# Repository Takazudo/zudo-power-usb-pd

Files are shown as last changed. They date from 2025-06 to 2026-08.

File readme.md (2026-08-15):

# USB-PD Powered Modular Synthesizer Power Supply

A low-noise power module design that takes USB-C PD 15V input and provides ±12V/+5V power for modular synthesizers.

## Documentation

**Main documentation is in the `/doc/` Docusaurus site**

```bash
cd doc
pnpm install
pnpm start
```

Open http://localhost:3000 in your browser to view the documentation.

### Key Documents

- **[Project Overview](doc/src/content/docs/overview/overview.md)** - Design goals, architecture, features
- **[Board A — USB-PD Sink Core](doc/src/content/docs/overview/board-a-usb-pd-core.md)** - PD negotiation, load switch, A↔B interface
- **[Board B — Synth Power Conversion](doc/src/content/docs/overview/board-b-synth-power.md)** - DC-DCs, LDOs, protection, outputs
- **[Circuit Diagrams](doc/src/content/docs/overview/circuit-diagrams.mdx)** - Complete circuit configuration
- **[Bill of Materials](doc/src/content/docs/overview/bom.md)** - JLCPCB-compatible BOM
- **[Component Records](doc/src/content/docs/components/index.mdx)** - Generated per-component evidence pages

## Project Overview

### Design Goals

A modular synthesizer power supply powered by USB-C PD chargers.

- **Input**: USB-C PD 15V 3A (max 45W)
- **Output**: +12V/1.2A, -12V/1.0A, +5V/1.2A
- **Ripple**: <1mVp-p (low noise optimized for modular synths)
- **Protection**: PTC auto-reset + fuse backup (beginner-friendly)
- **Sourcing**: All parts JLCPCB-compatible (reliable supply, low cost)

### 4-Stage Architecture

```
USB-C 15V ──┬─→ +13.5V (DC-DC) ──→ +12V (LDO) ──→ +12V OUT
            │
            ├─→ +7.5V  (DC-DC) ──→ +5V  (LDO) ──→ +5V OUT
            │
            └─→ -13.5V (inverting DC-DC) ──→ -12V (LDO) ──→ -12V OUT
```

**DC-DC + LDO Two-Stage Design**: Balancing efficiency and noise

- DC-DC ensures efficiency (85-90%)
- LDO removes noise (<1mVp-p)
- Overall efficiency: 75-80%

## Current Status

### Completed

- Circuit design complete (4-stage architecture)
- Main component selection complete (JLCPCB part numbers confirmed)
- Detailed documentation complete

### Next Steps

1. **Search for remaining parts** (PTC fuses × 3, 2A fuse × 1)
2. **KiCad PCB design** (4-layer board recommended)
3. **Order prototype** (JLCPCB SMT)
4. **Performance testing** (ripple, efficiency, thermal)

## Repository Structure

- `/doc/` - Docusaurus documentation site **← Main documentation**
- `/footprints/` - PCB footprint images (CH224Q, USB-C)
- `/diagram-sources/` - Python schemdraw scripts for circuit diagrams
- `/symbols/` - KiCad symbol library
- `/3dp-files/` - 3D printable files
- `/jlcpcb-templates/` - JLCPCB order templates
- `/__inbox/` - Working directory (temporary files, gitignored)

## Original Concept

The reliable Doepfer power supplies use DC-DC converters for voltage conversion, with linear regulators (LM7812/LM7912) and capacitors at the final stage to reduce switching noise.

Following this design philosophy, this project obtains 15V power from USB-PD and provides low-noise ±12V/+5V power required by modular synthesizers.

- **+12V**: 1200mA (most commonly used voltage in modular synths)
- **-12V**: 800mA (used by VCOs/VCAs)
- **+5V**: 500mA (used by digital modules)

These values are based on typical usage ratios in standard modular synthesizer systems.

## Reference Links

- [JLCPCB Parts Library](https://jlcpcb.com/parts)
- [KiCad Official Site](https://www.kicad.org/)
- [CH224Q Datasheet](https://www.wch-ic.com/products/CH224.html)

## License

This project is open source. Hardware design files can be freely used and modified.

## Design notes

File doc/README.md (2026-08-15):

# USB-PD Modular Synth Power Documentation

This directory is the documentation site for the USB-PD powered modular
synthesizer power supply. It is a [zudo-doc](https://github.com/takazudo) site
(a zfb / MDX / Tailwind / Preact static-site framework) consuming
`@takazudo/zfb` + `@takazudo/zdtp`, deployed to **Cloudflare Workers** (static
assets).

## Setup

```bash
pnpm install        # install dependencies
pnpm dev            # start dev server at http://localhost:4321
pnpm build          # production build (emits dist/, incl. dist/_worker.js)
pnpm preview        # preview the built dist/ locally
pnpm check          # TypeScript typecheck
```

## Directory Structure

```
doc/
├── src/
│   ├── content/docs/   # Documentation content (the pages)
│   │   ├── overview/   # Project overview, circuit diagrams, BOM
│   │   ├── components/ # Individual component specifications
│   │   ├── learning/   # Circuit design learning notes
│   │   ├── how-to/     # How-to guides
│   │   ├── misc/       # Footprint preview, misc
│   │   └── inbox/      # Status, debug logs, quick reference
│   ├── chrome-bindings.tsx    # MDX component registry for generated pages
│   ├── component-model-viewer/ # 3D model viewer island
│   ├── component-preview/     # Footprint/component preview island
│   └── styles/                # Global CSS
├── public/             # Static assets served at site root
│   ├── circuits/       # Circuit diagram SVGs   → /circuits/<name>.svg
│   ├── footprints/     # Footprint layout SVGs  → /footprints/<name>.svg
│   ├── footprint-imgs/ # Footprint preview PNGs → /footprint-imgs/<name>.png
│   ├── datasheets/     # Component datasheets (PDF)
│   ├── img/            # General images
│   └── kicad/          # KiCad screenshots
├── pages/              # two package-owned route stubs (index, docs catch-all)
├── zfb.config.ts       # site config — one zudoDoc({...}) call
└── wrangler.toml       # Cloudflare Workers deploy config
```

## Adding Documentation

1. Create a `.md` (no JSX) or `.mdx` (with JSX) file in the appropriate
   `src/content/docs/<section>/` directory.
2. Add frontmatter — `title:` is required; `sidebar_position:` controls order:
   ```yaml
   ---
   title: My Page
   sidebar_position: 3
   ---
   ```
3. Write content in Markdown/MDX. Start headings at `##` (the `title` renders as
   the h1). See `CLAUDE.md` in this directory for the full authoring rules.

## Tech Stack

- **zudo-doc** / **zfb** (`@takazudo/zfb`) — static-site framework
- **Preact** — UI rendering (server-rendered, islands for interactivity)
- **MDX** — Markdown + JSX content
- **Tailwind CSS** — styling
- **Mermaid** — diagram rendering
- **TypeScript** — type safety
- **Cloudflare Workers** — hosting (static assets via the zfb CF adapter)

## Commands

- `pnpm dev` — dev server at http://localhost:4321
- `pnpm build` — production build → `dist/`
- `pnpm preview` — preview the built `dist/`
- `pnpm check` — TypeScript typecheck
- `pnpm check:html` — validate built HTML

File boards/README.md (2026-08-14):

# boards/

Home for the split-board KiCad projects — **Board A** (USB-PD sink core:
STUSB4500 + USB-C + load switch + NVM pads) and **Board B** (synth power
conversion: DC-DCs + LDOs + protection + outputs). See
`doc/src/content/docs/inbox/board-split-decision.md` for the full board-split
decision and the A/B interface contract.

Both board projects exist and their schematics are generated from the spec
modules in `scripts/schgen/`. PCB layout has not started yet — the
directories carry schematics only, no `.kicad_pcb`.

## Layout

Each board has its own directory with its own KiCad project, named after the
board (a `<board>.kicad_pcb` is added when layout starts):

```
boards/
  board-a/
    board-a.kicad_pro
    board-a.kicad_sch
    fp-lib-table
    sym-lib-table
  board-b/
    board-b.kicad_pro
    board-b.kicad_sch
    fp-lib-table
    sym-lib-table
```

## Depth rule for library tables

The repo's shared symbol and footprint libraries live at the repo root
(`symbols/zudo-pd.kicad_sym`, `footprints/kicad/zudo-power.pretty`). The
root-level `zudo-pd.kicad_pro`'s own `sym-lib-table`/`fp-lib-table` reference
them directly, because `${KIPRJMOD}` (the project's own directory) *is* the
repo root there:

```
(lib (name "zudo-pd")(uri "${KIPRJMOD}/symbols/zudo-pd.kicad_sym") ...)
```

Each board project instead lives two directories below the repo root
(`boards/<name>/`), so `${KIPRJMOD}` there resolves to `boards/<name>/`, not
the repo root. Board `fp-lib-table`/`sym-lib-table` files must therefore add
one extra `..` to reach back up to the shared libraries:

```
(lib (name "zudo-pd")(uri "${KIPRJMOD}/../../symbols/zudo-pd.kicad_sym") ...)
(lib (name "zudo-pd")(uri "${KIPRJMOD}/../../footprints/kicad/zudo-power.pretty") ...)
```

Getting this depth wrong is the classic "board opens with missing symbols"
failure mode — double-check it whenever a new board project is created here.

## Regenerating a board schematic

Board schematics are not hand-drawn; they're generated from a Python spec
module by the `schgen` toolchain. See `scripts/schgen/README.md` for the full
workflow. Short version:

```
python3 scripts/schgen/gen_schematic.py board_a_spec   # or board_b_spec
```

`<spec_module>` is either a dotted module name (`board_a_spec`) or a path
(`scripts/schgen/board_a_spec.py`); `--help` works.

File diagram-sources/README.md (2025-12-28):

# Circuit Diagram Sources

This directory contains Python scripts that generate circuit diagrams using the `schemdraw` library.

## Organization

- **Source files**: Python scripts (`.py`) are stored here
- **Generated files**: SVG outputs are saved to `../docs/_fragments/`
- **Dark theme**: All diagrams use dark theme (black background, white foreground, Arial font)

## Generating Diagrams

Run any Python script to regenerate its corresponding SVG:

```bash
cd diagram-sources
python3 buck-u2-diagram.py
```

Output will be saved to `docs/_fragments/buck-u2-diagram.svg`

## Current Diagrams

- `buck-u2-diagram.py` → LM2596S-ADJ Buck Converter (+15V → +13.5V)

## Adding New Diagrams

1. Create a new `.py` file in this directory
2. Use the existing scripts as templates
3. Set output path to: `../docs/_fragments/your-diagram-name.svg`
4. Run the script to generate the SVG
5. Import and use in MDX files via the `CircuitSvg` component

## Requirements

```bash
pip install schemdraw
```

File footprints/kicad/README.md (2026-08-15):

# KiCad Footprints

This directory contains KiCad footprint files (.kicad_mod) for components used in this USB-PD power supply project. All footprints were downloaded from LCSC/EasyEDA using the [easyeda2kicad.py](https://github.com/uPesy/easyeda2kicad.py) tool.

## Key Component Footprints

### USB-PD Stage
- **QFN-20_L3.0-W3.0-P0.40-BL-EP1.7.kicad_mod** - CH224D USB PD Controller (C3975094)
- **TYPE-C-SMD_TYPE-C-6P.kicad_mod** - USB Type-C 6P Female Connector (C456012)

### DC-DC Converter Stage
- **TO-263-5_L10.2-W8.9-P1.70-BR.kicad_mod** - LM2596S-ADJ Buck Converter (C347423) — also used for U4 in inverting buck-boost config

### Linear Regulator Stage
- **TO-220-3_L10.0-W4.5-P2.54-L.kicad_mod** - LM7812CV +12V Regulator (C2914)
- **TO-263-2_L10.0-W9.2-P5.08-LS15.3-TL-CW.kicad_mod** - L7805ABD2T +5V Regulator (C86206)
- **TO-252-3_L6.5-W5.8-P4.58-BL.kicad_mod** - CJ7912 -12V Regulator (C94173)

### Passive Components
- **C0603.kicad_mod** - 0603 Capacitor
- **R0603.kicad_mod** - 0603 Resistor
- **CAP-SMD_BD4.0-L4.3-W4.3-LS5.0-FD.kicad_mod** - SMD Electrolytic Capacitor (small)
- **CAP-SMD_BD18.0-L19.0-W19.0-LS20.4-FD.kicad_mod** - SMD Electrolytic Capacitor (large)

### Protection & Indicators
- **SMA_L4.4-W2.8-LS5.4-RD.kicad_mod** - SMA Diode Package (TVS, Schottky)
- **SOD-123FL_L2.8-W1.8-LS3.7-RD.kicad_mod** - SOD-123FL Diode Package
- **LED0603-RD.kicad_mod** - 0603 LED (Red)
- **LED0603-R-RD_WHITE.kicad_mod** - 0603 LED (White)

### Connectors
- **HDR-TH_16P-P2.54-H-M-R2-C8-S2.54.kicad_mod** - 16-pin 2.54mm Through-hole Header (Eurorack Power)
- **HDR-TH_3P-P2.54-V-M.kicad_mod** - 3-pin 2.54mm Through-hole Header
- **HDR-SMD_6P-P2.00-V-M_XBK_R2.kicad_mod** - 6-pin 2.00mm SMD Header
- **HDR-SMD_8P-P2.54-V-M-LS4.8_R2.kicad_mod** - 8-pin 2.54mm SMD Header
- **DC-IN-TH_DC550250-0366-2H.kicad_mod** - DC Input Jack (Through-hole)

## Usage

### In KiCad
1. Add this directory to your KiCad footprint library list
2. Select footprints when assigning components in your schematic

### Downloading Additional Footprints

To download footprints for other components:

```bash
easyeda2kicad --lcsc_id <LCSC_ID> --footprint
```

The footprints will be saved to `~/Documents/Kicad/easyeda2kicad/easyeda2kicad.pretty/` and can be copied to this directory.

Example:
```bash
# Download CH224D footprint
easyeda2kicad --lcsc_id C3975094 --footprint

# Copy to project
cp ~/Documents/Kicad/easyeda2kicad/easyeda2kicad.pretty/*.kicad_mod ./
```

## Notes

- All LCSC part numbers are referenced in the [Bill of Materials](/doc/src/content/docs/overview/bom.md)
- Footprints include pads, silkscreen, and courtyard layers
- Some footprints may include 3D model references (if available from EasyEDA)

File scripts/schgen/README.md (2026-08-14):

# schgen — schematic generation from board spec modules

Board schematics under `boards/` are not hand-drawn. Each board is generated
from a Python spec module (`board_a_spec.py` / `board_b_spec.py`) that lists
components, positions, nets, and no-connects. The spec is the source of
truth; the `.kicad_sch` file is a build artifact of it.

The toolchain was ported from `zudo-led-lamp`; both board spec modules are
committed and both boards under `boards/` are generated from them. See
`doc/src/content/docs/inbox/board-split-decision.md` for the A/B interface
contract.

## Files

- `board_a_spec.py`, `board_b_spec.py` — per-board `COMPONENTS` / `NETS` /
  `NO_CONNECT` tables. Edit these, never the generated `.kicad_sch` directly.
- `decisions.json` — the wave-6 decision lock for epic #86 (part swaps,
  provisions, dispositions the board specs must implement), with rationale and
  fact-ID evidence per decision. Machine-consumable source of truth; issue
  bodies #124/#125/#126 mirror it. Its `required_decision_keys` list declares
  which decision keys the validator requires.
- `check_decisions.py` — offline validator for `decisions.json`: schema shape,
  the data-declared required decision keys, and kind-aware resolution of every
  evidence ID against the component-bundle / integration-rule fact base. Run:
  `python3 scripts/schgen/check_decisions.py`.
- `baselines/` — locked connectivity baselines per board
  (`board-a.json` / `board-b.json`: net → `Ref.Pin` lists derived from the
  reviewed netlist) plus the allow-list files naming the intentional
  spec-vs-baseline deltas (`board-a-allowed-deltas.json` /
  `board-b-allow.json`).
- `check_baseline.py` — diffs a spec module's `NETS` against its locked
  baseline JSON, modulo the allow-list. Every declared allow-list delta is
  also verified to actually hold in the spec, so a stale entry surfaces as a
  mismatch instead of masking an incomplete implementation. Also has a
  fixture-driven `--self-test` (see `fixtures/check_baseline/`). Run:
  ```
  python3 scripts/schgen/check_baseline.py scripts/schgen/board_a_spec.py scripts/schgen/baselines/board-a.json --allow scripts/schgen/baselines/board-a-allowed-deltas.json
  python3 scripts/schgen/check_baseline.py scripts/schgen/board_b_spec.py scripts/schgen/baselines/board-b.json --allow scripts/schgen/baselines/board-b-allow.json
  python3 scripts/schgen/check_baseline.py --self-test
  ```
- `schgen_core.py` — shared generator: reads symbols from
  `symbols/zudo-pd.kicad_sym`, places components, and emits global labels for
  every net (no drawn wires) plus no-connect markers. Also home of the shared
  `load_spec_module()` loader (path or dotted module name) every CLI here
  uses, and the `SchgenError` the tools report as messages rather than
  tracebacks.
- `sexp.py` — tiny, dependency-free KiCad s-expression tokenizer/parser used
  by the generator, the verifiers, and the smoke test. No KiCad install
  required.
- `gen_schematic.py` — CLI entry point:
  `python3 scripts/schgen/gen_schematic.py <spec_module>` where
  `<spec_module>` is a path (`scripts/schgen/board_a_spec.py`) or a dotted
  module name (`board_a_spec`). `--help` works.
- `verify_geometry.py` — re-derives every pin endpoint from a generated
  `.kicad_sch` itself (embedded lib_symbols + instance placements) and checks
  that every global label sits on a pin endpoint, no coordinate mixes two
  nets (no implicit shorts), the label-derived net map equals the spec's
  `NETS`, and no-connect markers match `NO_CONNECT`. Pure Python, no KiCad.
  Run: `python3 scripts/schgen/verify_geometry.py <spec_module> <kicad_sch>`.
- `verify_netlist.py` — diffs a kicad-cli netlist export against a spec's
  `NETS`/`NO_CONNECT` tables and prints `PASS`/`FAIL`.
- `verify.sh` — wraps the kicad-cli export + `verify_netlist.py` call for one
  board. Local-only (see below); not run in CI.
- `test_spec_smoke.py` — minimal spec (3 real zudo-pd resistor symbols, 2
  nets, 2 no-connects) used only to smoke-test the generator itself. Not a
  real board.
- `run_smoke_test.sh` — regenerates `test_spec_smoke.py` into a throwaway
  temp dir (never touches the repo tree), asserts the emitted global net
  labels match the spec's `NETS`, runs the `verify_geometry.py` checks on the
  output, and proves the geometry check can fail via a corrupted-label
  negative control. Requires only stock `python3` — no pip installs, no
  KiCad.
- `fixtures/check_baseline/` — the fixture corpus behind
  `check_baseline.py --self-test`.

## Regen + verify workflow

1. Edit the spec module (`board_a_spec.py` or `board_b_spec.py`) — add/move a
   component, change a net, etc.
2. Regenerate the schematic:
   ```
   python3 scripts/schgen/gen_schematic.py board_a_spec   # or board_b_spec
   ```
   This rewrites `boards/<board>/<board>.kicad_sch` in place. No KiCad
   install needed — `gen_schematic.py` only depends on `sexp.py`.
3. Run the offline checks CI will run (baseline drift + geometry):
   ```
   python3 scripts/schgen/check_baseline.py scripts/schgen/board_a_spec.py scripts/schgen/baselines/board-a.json --allow scripts/schgen/baselines/board-a-allowed-deltas.json
   python3 scripts/schgen/verify_geometry.py scripts/schgen/board_a_spec.py boards/board-a/board-a.kicad_sch
   ```
4. Verify connectivity against a real netlist export (requires a local KiCad
   install with `kicad-cli` on `PATH`):
   ```
   scripts/schgen/verify.sh board-a   # or board-b
   ```
   This runs `kicad-cli sch export netlist --format kicadsexpr` on the
   regenerated `.kicad_sch`, then diffs the result against the spec's `NETS`
   and `NO_CONNECT` tables via `verify_netlist.py`, printing `PASS`/`FAIL`.
5. Open the regenerated schematic in KiCad's Eeschema at least once (ERC,
   visual sanity) before committing.
6. Commit the spec module and the regenerated `.kicad_sch` together — never
   one without the other.

## Smoke test (no board, no KiCad)

To sanity-check the generator itself — e.g. after touching `schgen_core.py`
or `sexp.py` — run:

```
bash scripts/schgen/run_smoke_test.sh
```

This generates `test_spec_smoke.py` into a temp directory, parses the result
back with `sexp.py`, asserts the emitted global labels equal the spec's
`NETS`, and runs the full geometry check (including its negative control). It
needs stock `python3` only.

## kicad-cli availability

`verify.sh` degrades gracefully when `kicad-cli` is not on `PATH`: it prints
a `SKIPPED` marker and exits `0` rather than failing. This is intentional —
netlist verification is a local-only check that needs a real KiCad install
(the CI runner has no KiCad). Install KiCad (kicad-cli ships with the desktop
app) to exercise the real path.

## What CI checks

`.github/workflows/component-spec-skills.yml` runs, for every PR touching
this toolchain (and pushes to `main`):

- **Regen-idempotency** — regenerate both boards against the checked-out tree
  and fail on any diff under `boards/` (with `git add --intent-to-add` first,
  so a newly emitted untracked file also fails). Catches "spec and committed
  schematic drifted apart".
- **Label geometry** — `verify_geometry.py` on both committed boards: labels
  on pin endpoints, no cross-net coordinate collisions, label net map equal
  to the spec, no-connects matching.
- **Baseline drift** — `check_baseline.py` per board against
  `baselines/*.json` with the allow-list files.
- **Tool self-tests** — `check_baseline.py --self-test` and
  `run_smoke_test.sh`.
- **Decision lock** — `check_decisions.py`.

What CI still cannot do is run `kicad-cli`; the netlist cross-check in
`verify.sh` stays a local, KiCad-installed step.

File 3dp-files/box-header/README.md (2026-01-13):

# Box Header Guard for Eurorack Power Connector

3D printable shrouded/keyed box header frame that converts standard 2×8 pin headers into IDC-compatible Eurorack power connectors.

## Target Component

- **LCSC Part**: [C5383092](https://jlcpcb.com/partdetail/C5383092)
- **Part Number**: 2541WR-2x08P
- **Type**: 2×8 pin header (16-pin), 2.54mm pitch

## Files

| File | Description |
|---|---|
| `box-header.scad` | OpenSCAD source file |
| `box-header.stl` | 3D printable STL |
| `C5383092.pdf` | Pin header datasheet (if present) |

## Key Dimensions

| Parameter | Value | Source |
|---|---|---|
| Pin pitch | 2.54mm | Datasheet |
| Pin size | 0.64mm (square) | Datasheet SQ.0.64 |
| Row spacing | 2.54mm | Standard |
| Box height | 8.9mm | Standard IDC |
| Bottom thickness | 0.5mm | Modified |
| Slot width | 0.6mm | Adjusted after print test |

## Design Features

- **Center divider** on bottom surface for alignment
- **0.8mm pin holes** for tight press-fit
- **Key notch** for polarized connection (prevents reverse insertion)
- **Thicker walls** (1.5mm) for print durability

## Print Settings

- Layer height: 0.2mm recommended
- No supports needed
- Print with bottom face down

## License

Original design by John Stäck 2018, licensed under [CC BY-SA 4.0](https://creativecommons.org/licenses/by-sa/4.0/).

Modifications:
- Changed bottom thickness to 0.5mm
- Added center divider
- Adjusted slot width to 0.6mm

## Usage

Press-fit onto the 2×8 pin headers (J2-J5) on the PCB to create shrouded connectors compatible with standard Eurorack 16-pin ribbon cables.

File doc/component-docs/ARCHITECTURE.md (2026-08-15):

# Component knowledge docs — architecture contract (zudo-pd port)

Status: **locked** (spec-architecture epic #86; ported from `zudo-led-lamp`'s
epic-#57 engine and trimmed to this repository's adapter reality)
Scope: project-local code under `doc/`. Not a framework feature, not an
installable package, not a change to any other repository.

This document is the contract the generator code cites. Where it names a file,
a command or a rule, that is the decision — not a suggestion. Section numbers
are stable because source comments cite them (`§5`, `§7`). Where this port
deliberately differs from led-lamp, the difference is stated inline; the
led-lamp original remains the reference for the sections of the engine that
were ported unchanged.

---

## 1. What this is

The repository holds validated component evidence as structured JSON under
`.claude/skills/`. That data is the **only** source of technical truth. This
feature adds a **projection** of it into human documentation. It never
re-states a fact in prose, never repairs a value, and never synthesises a
component-wide verdict.

Corpus as of this contract: **21 owner bundles, 41 records (all standalone),
126 sources, 454 facts, 144 coverage domains, 36 interactions, 41 routes, 41
pin maps, 136 pins**, plus **9 cross-component rules** in
`circuit-spec-integration`; 40 inventory lines fitted, 2 DNP/hand-fit (one
line, `line-c23186`, is mixed — fitted on board-b, DNP on board-a — which is
why fit state is carried per placement, §5). These figures are asserted in
code (`adapters/circuit/selection.ts` `expect`, and the test suites) and a
mismatch fails the build.

## 2. Directory ownership

| Path | Owner | Rule |
|---|---|---|
| `doc/component-docs/` | this feature | all generator code, tests, this document |
| `doc/src/content/docs/components/` | **generator, exclusively** | committed; never hand-edit; every file is rewritten from evidence |
| `doc/component-docs/preflight.json` | generator | committed, deterministic, reviewable |
| `doc/src/chrome-bindings.tsx` | site | carries the evidence-component registrations (`mdxExtras`); must stay in sync with `core/mdx.ts` `ALLOWED_COMPONENT_ATTRIBUTES` (guarded by `tests/presentation.test.ts`) |
| `doc/src/styles/global.css` | site | an appended presentation block for the generated pages (`.zld-evidence-*`) |
| `.claude/skills/**` | evidence owners | **read-only** to this feature |

**Matches led-lamp.** The exclusively-owned generated tree is rooted directly
at `doc/src/content/docs/components/` (`GENERATED_ROOT` in
`adapters/circuit/paths.ts`), identical to led-lamp's shape. The public URLs
read `/docs/components/{catalog,integration,records,records/<slug>}/`.

### Module layout under `doc/component-docs/`

```
core/                       provider-neutral; no Python, no `.claude`, no fs paths
  errors.ts                 ErrorCode union + ComponentDocsError + fail()
  text.ts                   SafeText brand + safeText() sanitiser
  url.ts                    SafeUrl brand + classifyUrl() policy
  ids.ts                    Slug/Anchor brands, recordSlug(), anchor(), byCodeUnit()
  view-model.ts             the public view model TYPES (frozen here)
  publication.ts            FieldKey union, PublicationMatrix, PublicationPolicy, PreflightReport
  mdx.ts                    mdast builders + serializeBody() + assertMdxSafe()
  page.ts                   frontmatter + buildPage() + generated-file marker
  emit.ts                   owned-tree write / prune / diff, path containment
  adapter.ts                ComponentDataAdapter + ValidationRunner interfaces
  pipeline.ts               the one generation path
  scan.ts                   denied-value artifact scanning (wired by cli/scan.ts)
  render/landing.ts         /docs/components/                    (landing)
  render/catalog.ts         /docs/components/catalog/
  render/record.ts          /docs/components/records/<slug>/
  render/shared.ts          routes, glosses and orderings the pages share
  render/integration.ts     /docs/components/integration/
adapters/circuit/           this repository's evidence provider
  paths.ts                  every path the adapter may touch
  validate.ts               python3 validate.py --strict subprocess
  read.ts                   contained, symlink-refusing JSON reads
  selection.ts              committed instance allowlist (41 records / 126 sources)
  matrix.ts                 committed per-field decisions
  canaries.ts               denied-key harvest for the artifact scan
  integration.ts            cross-component rules: shapes, projection, closure
  evidence.ts               provider shapes, bundle reads, the joins (pure)
  references.ts             the reviewed document / footprint / model contract
  model-assets.ts           deterministic WRL publication into doc/public/
  index.ts                  the adapter itself; `projectIndex` is the pure projection
footprint-previews/         the committed footprint SVG generator + drift check
cli/                        run.ts (shared body), generate.ts, check.ts, scan.ts, watch.ts, models.ts
ui/                         evidence-{anchor,details,table}.tsx, component-references.tsx,
                            footprint-preview.tsx, package-model-viewer.tsx
scripts/                    model-viewer-browser-smoke.mjs (headless Chrome over CDP)
tests/                      node:test suites + fixtures.ts / provider fixtures
```

The two interactive previews live outside this directory, under
`doc/src/component-preview/` and `doc/src/component-model-viewer/`: they are
`"use client"` islands the site's build bundles, and `ui/` holds only the
SSR-safe bindings that mount them. `three` is imported by exactly one module
(`viewer-runtime.ts`), which the island loads with a dynamic `import()`, so it
ships in its own chunk and never in the page bundle.

`evidence.ts` and `projectIndex` are pure functions over parsed JSON, so every
join rule and every publication rule is provable against a fixture corpus with
no filesystem, no subprocess and no edit to the read-only evidence tree.

The dependency direction is one-way: `adapters/circuit/**` imports from
`core/**`; `core/**` imports nothing from `adapters/**`.

## 3. Build seam — package scripts, not a host plugin

`doc/package.json`:

| Script | Purpose |
|---|---|
| `generate:components` | validate (strict) → project → render → emit |
| `check:components` | dry-run; nonzero on drift |
| `scan:components` | denied-value scan of the BUILT site (`dist/`, §6.1) |
| `test:components` | unit + integration suites |
| `dev:components` | debounced regeneration (watch) |
| `generate:models` / `check:models` | publish (or drift-check) the reviewed WRL models |
| `generate:footprint-previews` / `check:footprint-previews` | the same pair for the footprint SVGs |
| `check:built-component-references` | the reference section's built-`dist/` contract |
| `test:model-viewer:browser` | headless-Chrome smoke over `dist/` (not in `b4push`; needs a browser) |
| `build` | `pnpm generate:models && pnpm generate:components && zfb build` — generation precedes the content snapshot |
| `b4push` | `check && test:components && check:footprint-previews && check:models && build && check:built-component-references && check:components && scan:components` |

Generation ordering is a **package-script** boundary, not a host-plugin
assumption: `generate:components` has finished and exited before `zfb` starts,
which is why `cli/generate.ts` can promise the snapshot already contains its
output. (led-lamp's §3 records the full plugin-vs-script rationale; it applies
here unchanged.) `generate:models` runs before it for the same reason one step
down: the model assets have to be in `public/` before `zfb` copies it.

The browser smoke is deliberately outside `b4push`. It needs a Chrome binary
and roughly a minute of wall clock, which is a reasonable ask of CI and of a
change to the viewer, but not of every push.

## 4. Validation — one validator, in Python, fatal on failure

`adapters/circuit/validate.ts` runs
`python3 .claude/skills/component-spec-audit/scripts/validate.py --strict` as
an argument array (`execFile`, no shell, no interpolation), cwd = repository
root, before any evidence is read. `--strict` matches the mode CI's PR gate
enforces (`component-spec-skills.yml`), so the doc build cannot pass on
evidence the PR gate rejects. Nonzero exit aborts generation with
`VALIDATION_FAILED`. `--online` is never passed. Python is pinned to >= 3.12,
matching the workflow pin; `COMPONENT_DOCS_PYTHON` overrides the interpreter.
No component validation is reimplemented in TypeScript.

## 5. View model and adapter seam

`core/view-model.ts` freezes the public shape. `VIEW_MODEL_VERSION = 1`; an
adapter declares `supportedViewModelVersions` and the pipeline refuses to run
on a mismatch, so a core/adapter skew is a startup error rather than a subtly
wrong page.

**v1 stays v1 while `core/` and the only adapter compile together from this
repository, including through incompatible shape changes.** led-lamp's epic
made two such changes without bumping the number (widening
`PublicFact["value"]`; adding required `ownerSkill` fields), and this port has
made its own (adding required `PublicPlacement.dnp`; deleting the unported
3D/preview seam — `packagePreviews` and its types). None bumped the number,
deliberately: core and the single adapter are compiled together from one
repository, so a skew between them is a *compile* error long before the
runtime check sees it, and nothing outside this repository has ever consumed
v1 — a bump would only churn `preflight.json` and imply a compatibility
boundary that never existed. The number becomes a real boundary the moment
`core/**` is extracted as a package; from then on the rule in the
`VIEW_MODEL_VERSION` doc comment applies literally and any incompatible change
bumps it.

Port-specific shape decisions:

- **`PublicPlacement.dnp`** — fit state is per placement, because one
  inventory line is fitted on one board and DNP on the other
  (`line-c23186`). The line-level `dnp` is only the catalog rollup
  (fitted-if-fitted-anywhere); the record page renders each placement's own
  fit state, and a mixed line labels itself as mixed rather than either
  single state.
- **`ownerSkill` is `null` always** — zudo-pd runs with
  `claudeResources: false`, so `/docs/claude-skills/<name>/` does not exist
  as a route to link back to; `matrix.ts` denies both `record.ownerSkill`
  and `integration.ownerSkill`.
- **No `packagePreviews` seam** — led-lamp carries previews as a top-level
  view-model collection (`PublicPackagePreview` / `packagePreviews`) plus the
  `asset.footprintPreview` / `asset.modelPreview` field keys. Neither is
  ported: here both previews hang off `reference.footprint` on the record that
  uses them, so a preview cannot exist without a record pointing at it. The
  assets themselves do exist (waves 6 and 7) and both previews render — this
  is a shape difference, not an absence. Re-porting the collection starts from
  led-lamp's source, not from a vestigial copy here.
- **`corpus` counts what was published**, not what the provider holds: the
  landing page must never assert counts the site does not deliver. The three
  inventory-scoped rows (`inventoryLines`, `fittedLines`,
  `dnpOrHandFitLines`) stay inventory truth by design.

Identity, ordering and error rules (slugs from record IDs, verbatim provider
anchors scoped per page, inventory-line ordering with `byCodeUnit`, selection
closed under published links, integration rules count-asserted rather than
instance-selected, the closed `ErrorCode` union, fail-closed everywhere) are
ported unchanged from led-lamp §5.

## 6. Publication — default-zero, three gates

A value publishes only if it clears all three:

1. **Instance** — its record ID (and for a source, its source ID) is listed
   in `adapters/circuit/selection.ts`.
2. **Field** — its `FieldKey` is `PUBLISH` in `adapters/circuit/matrix.ts`.
3. **Value** — it survives `safeText()` / `classifyUrl()`.

`InstanceSelection.expect` pins **both sides**: the provider corpus size AND
the selection list lengths. The selection-side check exists because this
corpus once shipped a record (`rec-bzt52c11-c92321`) whose bundle validated
and whose counts were bumped while the ID list was left behind — the record
silently had no page. Either direction failing is a `STALE_SELECTION`.

zudo-pd's `DENY` set is 11 of 97 keys: led-lamp's seven content denials
(`source.sha256`, `source.evidenceExtract`,
`source.alternateAuthoritativeUrl`, `source.physicalPdfPageIndex`,
`routing.positivePrompts`, `routing.negativePrompts`, `pinMap.reviewedBy`),
`asset.binary`, both `ownerSkill` keys (`claudeResources: false`), and
`reference.package.recordIds`, which no renderer reads. All three halves of
`reference.*` publish: `documentSelections` names one reviewed source for 40
of the 41 records and `documentExceptions` names why the 41st has none,
`reference.footprint.{packageId,name,path}` back the rendered footprint
preview and its `Source:` line, and `reference.model.*` backs the interactive
package model viewer (wave 7 sourced a reviewed `.wrl`/`.step` pair for all
27 packages; wave 8 built the viewer). URL policy, the preflight report
contract, and the emitted-vs-withheld accounting are ported unchanged from
led-lamp §6.

### 6.1 Artifact-level proof (`pnpm scan:components`)

Everything above reasons about the projection; it cannot prove the **built
site** is clean, because between the view model and `dist/` sit the MDX
compiler, the HTML minifier and the indexers — none owned by this feature. So
`cli/scan.ts` (wired into `b4push` and `main-deploy.yml` after `pnpm build`)
harvests every value reachable only through a denied provider key
(`adapters/circuit/canaries.ts`), subtracts values independently published by
the hand-authored narrative pages, and scans every text artifact under
`dist/`. The scan fails closed in both directions: a hit is a leak, and too
few canaries or too few files means the scan proved nothing. Positive
controls (including `rec-bzt52c11-c92321`, the record that once shipped
page-less) prove "nothing leaked" is not "nothing shipped".

## 7. Safe generation — three layers

1. **Build.** Content is constructed only through the builders in
   `core/mdx.ts`. They accept `SafeText`/`SafeUrl` and a closed node
   vocabulary; there is no raw-node builder.
2. **Serialize.** `mdast-util-to-markdown` with `mdast-util-mdx` and
   `mdast-util-gfm-table`, plus `unsafe` rules for line-leading `:::` and
   line-leading `import`/`export`.
3. **Guard.** `assertMdxSafe` re-reads the **final** body text and fails the
   build on: line-leading `import`/`export`, line-leading `:::`, a `---`
   fence line, an HTML comment, any un-escaped `{` or `<`, any JSX name
   outside `ALLOWED_COMPONENT_ATTRIBUTES`, any attribute not listed for that
   component, and any attribute value outside `ATTRIBUTE_VALUE_PATTERN`
   (slug paths — slash-separated slug segments, admitted for `CategoryNav`'s
   nested `category` — and nothing else).

The guard's false positives are **deliberate**: it does not ask whether a
brace sat inside an inline-code span where MDX would treat it as inert — it
fails closed and a human decides. Renderers obey this rather than work around
it (monospace is for identifiers, which are code-shaped by construction;
evidence phrases render as text). Evidence text never reaches a JSX
attribute; frontmatter is a closed key set with `JSON.stringify`d values;
no generated data module is imported by any client entry; `safeText`
NFC-normalises and then **rejects** rather than strips. Relaxing any of this
is a publication decision, not a refactor.

## 8. Generated-tree ownership and cleanup

`doc/src/content/docs/components/` is written by `core/emit.ts` and
nothing else. Every write path is `assertContained` (segment-wise); emit
never `rm -rf`s — it prunes only marker-carrying `.mdx` leftovers under the
owned root; a file there without the generated marker is a fatal
`PATH_CONTAINMENT`; symlinks are fatal on both the write side and the
evidence-read side; emit is idempotent (a second run reports `0 written`).

## 9. Routes and navigation

| Route | Source |
|---|---|
| `/docs/components/` | `render/landing.ts` |
| `/docs/components/catalog/` | `render/catalog.ts` |
| `/docs/components/integration/` | `render/integration.ts` |
| `/docs/components/records/` | `render/record.ts` (records index) |
| `/docs/components/records/<slug>/` | `render/record.ts` (per-record pages) |

The landing page's `CategoryNav` targets `components` — this project's
wrapper resolves `category` as a slug path. The three evidence components
(`EvidenceAnchor`, `EvidenceDetails`, `EvidenceTable`) are registered in
`doc/src/chrome-bindings.tsx`; that registry and
`ALLOWED_COMPONENT_ATTRIBUTES` must change together, and
`tests/presentation.test.ts` enforces it.

## 10. CI

Two workflows, both credential-free on the checking side:

- **`component-spec-skills.yml`** (PRs + main): the strict Python validator,
  its unit tests, the strict forward tests, `check_baseline.py --self-test`,
  the schgen smoke test, regen-idempotency for both boards (untracked-aware
  via `git add --intent-to-add`), the label-geometry check, baseline drift,
  the decision lock — and a `doc-tests` job running `pnpm test:components`
  (Node + Python, because the pipeline tests shell out to the validator).
- **`main-deploy.yml`** (push to main): typecheck, build, the two-step
  generated-output drift gate (`--intent-to-add` + second-generation
  byte-identity via `check:components`), the `scan:components` artifact scan,
  then the guarded Cloudflare deploy. All actions are SHA-pinned.

## 11. Direct dependencies added

`mdast-util-to-markdown`, `mdast-util-mdx`, `mdast-util-gfm-table` (serializer
+ syntax tables), and `@types/mdast`. Everything else the generator uses is
Node builtin or already a site dependency.

## 12. Portability boundary

`core/**` is written to be extractable as a package: provider-neutral, no
`.claude` paths, no Python, no zudo-pd names. Extraction is deliberately
deferred — the port copies led-lamp's engine rather than sharing it, and both
repositories accept the divergence risk until a third consumer exists. The
`VIEW_MODEL_VERSION` rule flips from "stays 1" to "bumps on every
incompatible change" at that extraction boundary (§5).

## 13. Non-goals

No re-stated facts, no prose summaries of evidence, no component-wide
verdicts, no PDF republication, no `/docs/claude-skills/` routes, no sitemap
change, no framework feature. The generated pages are a projection; where they
disagree with the evidence JSON, the evidence is correct. The 3D preview is
in scope but stays inside that rule: the viewer shows the shared FOOTPRINT
package's geometry and says so on the card, which is a weaker claim than
"this is the part" and is the only one the evidence supports.

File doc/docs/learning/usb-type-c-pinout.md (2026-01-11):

---
sidebar_position: 6
---

# USB Type-C Pinout and Power Delivery

Understanding USB Type-C connector pinout and how it enables USB Power Delivery (PD) negotiation.

## Full USB Type-C Pinout (24-pin)

A full USB Type-C receptacle has 24 pins arranged symmetrically to support reversible insertion:

```
USB Type-C Receptacle (24-pin)
Receptacle Front View (looking into connector)

Top Row (A-side):
┌────────────────────────────────────────────────────┐
│ A1   A2   A3   A4   A5   A6   A7   A8   A9  A10  A11  A12 │
│ GND  TX1+ TX1- VBUS CC1  D+   D-  SBU1 VBUS RX2- RX2+ GND │
└────────────────────────────────────────────────────┘

Bottom Row (B-side):
┌────────────────────────────────────────────────────┐
│ B12  B11  B10  B9   B8   B7   B6   B5   B4   B3   B2   B1  │
│ GND  RX1- RX1+ VBUS SBU2 D-   D+  CC2  VBUS TX2- TX2+ GND │
└────────────────────────────────────────────────────┘
```

### Pin Functions

| Pin(s) | Signal | Purpose | Speed |
| --- | --- | --- | --- |
| **A1, A12, B1, B12** | **GND** | Ground reference | - |
| **A4, A9, B4, B9** | **VBUS** | Power delivery (5V-20V) | - |
| **A5** | **CC1** | Configuration Channel 1 | - |
| **B5** | **CC2** | Configuration Channel 2 | - |
| **A6, A7, B6, B7** | **D+, D-** | USB 2.0 data | 480 Mbps |
| **A2, A3** | **TX1+, TX1-** | SuperSpeed TX Lane 1 | 5-10 Gbps |
| **A10, A11** | **RX2-, RX2+** | SuperSpeed RX Lane 2 | 5-10 Gbps |
| **B2, B3** | **TX2-, TX2+** | SuperSpeed TX Lane 2 | 5-10 Gbps |
| **B10, B11** | **RX1-, RX1+** | SuperSpeed RX Lane 1 | 5-10 Gbps |
| **A8** | **SBU1** | Sideband Use 1 | Alternate modes |
| **B8** | **SBU2** | Sideband Use 2 | Alternate modes |

## Simplified USB Type-C for Power-Only (6-pin)

For applications requiring **only power delivery** (no data transfer), a simplified 6-pin connector is sufficient:

```
USB Type-C 6-Pin Connector (Power-Only)

┌──────────────────┐
│   1    2    3    │  Top Row
│  GND  VBUS  CC1  │
└──────────────────┘
┌──────────────────┐
│  CC2  VBUS  GND  │  Bottom Row
│   4    5    6    │
└──────────────────┘
```

### 6-Pin Functions

| Pin | Signal | Purpose |
| --- | --- | --- |
| **1, 6** | **GND**  | Ground reference |
| **2, 5** | **VBUS** | Power delivery (5V-20V) |
| **3** | **CC1**  | Configuration Channel 1 (orientation & PD) |
| **4** | **CC2**  | Configuration Channel 2 (orientation & PD) |

**This project uses a 6-pin connector** (JLCPCB C2927029) - see [J1 USB-C Connector documentation](/docs/components/usb-c-connector).

## Configuration Channel (CC) Pins

The CC pins are critical for USB Power Delivery. They serve multiple purposes:

### 1. Cable Orientation Detection

USB Type-C is reversible. When you plug in a cable:

- Only **one** CC pin is active at a time
- The active CC pin identifies cable orientation
- The other CC pin remains inactive

**Example**:

```
Orientation 1 (normal):
- CC1 active → CH224D detects cable on CC1
- CC2 inactive

Orientation 2 (flipped):
- CC2 active → CH224D detects cable on CC2
- CC1 inactive
```

### 2. Current Advertisement (Non-PD)

For standard USB Type-C (without PD negotiation), CC pins advertise available current:

| Rp (Pull-up resistor on source) | Advertised Current |
| --- | --- |
| 56kΩ | Default USB (500-900mA) |
| 22kΩ | 1.5A @ 5V |
| 10kΩ | 3A @ 5V |

### 3. Power Delivery Negotiation

With USB-PD (like CH224D), CC pins carry **digital communication**:

```
Negotiation Sequence:

1. Initial Connection (0-100ms):
   ┌─────────┐                    ┌─────────┐
   │ Source  │ ─── CC line ────→  │  Sink   │
   │ (PD     │                    │ (CH224D)│
   │ Charger)│                    │         │
   └─────────┘                    └─────────┘
   VBUS = 5V (default)

2. Capability Discovery (100-200ms):
   ┌─────────┐                    ┌─────────┐
   │ Source  │ ←── CC line ────   │  Sink   │
   │         │  "What voltages    │         │
   │         │   do you have?"    │         │
   └─────────┘                    └─────────┘

   Source responds:
   - 5V @ 3A
   - 9V @ 3A
   - 12V @ 3A
   - 15V @ 3A ✅
   - 20V @ 2.25A

3. Voltage Request (200-300ms):
   ┌─────────┐                    ┌─────────┐
   │ Source  │ ←── CC line ────   │  Sink   │
   │         │  "I want 15V/3A"   │         │
   │         │                    │         │
   └─────────┘                    └─────────┘

4. Acceptance (300-500ms):
   ┌─────────┐                    ┌─────────┐
   │ Source  │ ─── CC line ────→  │  Sink   │
   │         │  "OK, switching"   │         │
   │         │                    │         │
   └─────────┘                    └─────────┘

5. Voltage Transition (500-1000ms):
   VBUS transitions: 5V → 15V

6. Power Ready (>1000ms):
   VBUS stable at 15V
   System draws up to 45W (15V × 3A)
```

## VBUS Pins and Current Distribution

### Why Multiple VBUS Pins?

USB Type-C has **4 VBUS pins** (A4, A9, B4, B9) to:

1. **Distribute current**: Each pin carries a portion of total current
2. **Reduce resistance**: Parallel pins = lower resistance
3. **Improve reliability**: Redundancy in case of poor contact

**Current distribution example (3A total)**:

```
A4 ──┬─→ ~0.75A
     │
A9 ──┤─→ ~0.75A
     │
B4 ──┤─→ ~0.75A       Total: 3A
     │
B9 ──┴─→ ~0.75A
```

### 6-Pin Connector VBUS

In 6-pin connectors, only **2 VBUS pins** are present (pins 2, 5):

- Maximum current: **3A** (sufficient for most USB-PD applications)
- Current distribution: ~1.5A per pin

**This is adequate for our 15V/3A (45W) power supply.**

## Critical: Always Connect Redundant Pins Together

### Why Connect Both VBUS Pins Together?

USB Type-C has **redundant power pins** by design. For 6-pin connectors, this means:

- **2 VBUS pins** (pins 2, 5)
- **2 GND pins** (pins 1, 6)

**You must ALWAYS connect both pins of each type together.** Never connect just one!

### ✅ Correct Connection Strategy

```
J1 (USB-C 6P Connector)

Pin 1 (GND)  ──┬─→ System GND
               │   (via wide trace or ground plane)
Pin 6 (GND)  ──┘

Pin 2 (VBUS) ──┬─→ VBUS node → CH224D pin 2
               │   (via wide trace or copper pour)
Pin 5 (VBUS) ──┘

Pin 3 (CC1)  ────→ CH224D pin 10 (separate)
Pin 4 (CC2)  ────→ CH224D pin 11 (separate)
```

### ❌ Wrong: Connecting Only One Pin

```
❌ WRONG:
Pin 1 (GND)  ──→ System GND
Pin 6 (GND)  ──→ Not connected  ❌

Pin 2 (VBUS) ──→ VBUS node
Pin 5 (VBUS) ──→ Not connected  ❌
```

### Benefits of Connecting Both Pins

| Benefit | Single Pin | Both Pins Connected |
| --- | --- | --- |
| **Resistance** | R | **R/2** (half) ✅ |
| **Current per pin** | 3A | **1.5A** (distributed) ✅ |
| **Power dissipation** | I²R | **I²R/4** (quarter) ✅ |
| **Voltage drop** | High | **Low** ✅ |
| **Heating** | High | **Low** ✅ |
| **Reliability** | Single point of failure | **Redundancy** ✅ |
| **EMI/Noise** | Higher | **Lower** ✅ |

### Why This Matters: Practical Example

**Scenario**: 15V @ 3A power delivery

#### ❌ Using Only One GND Pin:

```
Resistance: 10mΩ (typical pin + trace resistance)
Current: 3A (full current through one pin)
Voltage drop: V = I × R = 3A × 10mΩ = 30mV
Power dissipation: P = I² × R = 9W × 10mΩ = 90mW (heats up!)
```

#### ✅ Using Both GND Pins:

```
Resistance: 5mΩ (two pins in parallel)
Current per pin: 1.5A (distributed)
Voltage drop: V = I × R = 3A × 5mΩ = 15mV (half!)
Power dissipation: P = I² × R = 9W × 5mΩ = 45mW (half the heating!)
```

**Result**: Connecting both pins gives you:

- 50% less voltage drop
- 50% less heating
- Better reliability with redundancy

### PCB Layout Best Practices

```
Top Copper Layer:

┌────────────────────────────────┐
│  USB-C Connector J1            │
│                                │
│  Pin 1 (GND) ────┐             │
│                  ├──→ Via to GND plane
│  Pin 6 (GND) ────┘             │
│                                │
│  Pin 2 (VBUS) ───┐             │
│                  ├──→ Wide trace to VBUS
│  Pin 5 (VBUS) ───┘             │
└────────────────────────────────┘

Ground Plane (Internal Layer):
████████████████████████████████
█ Solid copper pour             █
█ Multiple vias from pins 1, 6  █
████████████████████████████████
```

**Key points**:

1. Use **wide traces** (≥1mm) or **copper pours** for VBUS
2. Use **multiple vias** to connect GND pins to ground plane
3. Keep traces **short and direct**
4. Use **symmetrical routing** when possible

### USB-C Specification Requirement

The **USB Type-C specification requires** all redundant power pins to be connected:

- Ensures proper current distribution
- Guarantees reliable operation in both orientations
- Meets thermal and electrical specifications
- Required for USB-IF certification

**Bottom line**: Always connect both VBUS pins together AND both GND pins together. This is not optional!

## CH224D Connection to USB-C Connector

In this project, the CH224D connects to the 6-pin USB Type-C connector:

```
J1 (USB-C 6P)          CH224D (QFN-20)

Pin 1 (GND) ──────────→ Pin 0 (GND/EPAD)
Pin 2 (VBUS) ─────────→ Pin 2 (VBUS)
Pin 3 (CC1) ──────────→ Pin 10 (CC1)
Pin 4 (CC2) ──────────→ Pin 11 (CC2)
Pin 5 (VBUS) ─────────→ Pin 2 (VBUS) (paralleled with pin 2)
Pin 6 (GND) ──────────→ Pin 0 (GND/EPAD)
```

**Key points**:

- Both VBUS pins (2, 5) connect to CH224D VBUS (pin 2)
- Both GND pins (1, 6) connect to CH224D GND (pin 0/EPAD)
- CC1 and CC2 are separate signals for orientation detection
- CH224D automatically detects which CC pin is active

## Advantages of 6-Pin Power-Only Design

| Feature | 24-Pin Connector | 6-Pin Connector | Winner |
| --- | --- | --- | --- |
| **Cost** | Higher ($0.50-1.00)  | Lower ($0.20-0.30) | ✅ 6-pin |
| **PCB Space** | Larger footprint | Smaller footprint  | ✅ 6-pin |
| **Complexity** | More routing | Simpler routing | ✅ 6-pin |
| **Data Transfer** | ✅ Yes (USB 2.0/3.x) | ❌ No | 24-pin |
| **Power Delivery** | ✅ Yes (up to 5A) | ✅ Yes (up to 3A)  | Both |
| **Stock Availability** | Good | Very good | ✅ 6-pin |

**For power-only USB-PD applications, 6-pin connectors are the optimal choice.**

## Common Misconceptions

### ❌ "You need all 24 pins for USB-PD"

**False.** USB-PD only requires VBUS, GND, and CC pins. The 6-pin connector is sufficient for up to 60W (20V/3A).

### ❌ "CC pins carry power"

**False.** CC pins carry only **low-current signals** for communication and detection. Power flows through VBUS pins only.

### ❌ "Both CC pins are always active"

**False.** Only **one CC pin is active** at a time, depending on cable orientation. The CH224D automatically detects which one.

### ❌ "More VBUS pins = more power"

**Partially true.** More VBUS pins allow **higher current** (24-pin supports 5A, 6-pin supports 3A), but voltage is the same. For 45W (15V/3A), the 6-pin connector is sufficient.

## Related Documentation

- [J1 USB-C Connector Component Page](/docs/components/usb-c-connector) - Full specifications and footprint
- [CH224D USB-PD Controller](/docs/components/ch224d) - PD negotiation IC
- [Diagram1: USB-PD Section](/docs/overview/circuit-diagrams#diagram1-usb-pd-power-supply-section) - Complete circuit diagram
- [Open-Drain PG Pin](/docs/learning/open-drain-pg-pin) - Understanding the Power Good indicator

## References

- [USB Type-C Cable and Connector Specification v2.1](https://www.usb.org/document-library/usb-type-cr-cable-and-connector-specification-release-21)
- [USB Power Delivery Specification v3.1](https://www.usb.org/document-library/usb-power-delivery)
- [AN4879: USB Type-C Power Delivery Using the STM32 MCU](https://www.st.com/resource/en/application_note/an4879-usb-typec-power-delivery-using-stm32-mcus-and-stm32mpu-devices-stmicroelectronics.pdf)

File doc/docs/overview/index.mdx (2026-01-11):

---
sidebar_position: 1
pagination_next: null
pagination_prev: null
---

import CategoryNav from '@site/src/components/CategoryNav';

# Overview

Documentation for USB-PD powered modular synthesizer power supply.

## Project Features

### 4-Stage Design

1. **USB-PD Power Supply** (CH224D)
2. **DC-DC Converters** (LM2596S x 3)
3. **Linear Regulators** (LM7812/7805/7912)
4. **Protection Circuit** (PTC + Fuse + TVS)

### Performance

- **Output**: +12V/1.2A, -12V/1A, +5V/1.2A
- **Ripple**: &lt;1mVp-p
- **Efficiency**: 75-80%
- **Protection**: 2-stage (PTC auto-reset + fuse backup)

## Pages in this category

<CategoryNav category="overview" />

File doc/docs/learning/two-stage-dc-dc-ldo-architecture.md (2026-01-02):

---
sidebar_position: 10
---

# Two-Stage DC-DC + LDO Power Supply Architecture for Low-Noise Audio

Research and validation of the two-stage power supply topology used in this project: switching DC-DC converter followed by linear regulator for low-noise audio applications.

## Overview

This document synthesizes research from professional audio designs, modular synthesizer power supplies, and semiconductor application notes to validate the design approach used in this USB-PD power supply.

### Design Question

**Is a 1.5V dropout margin adequate for low-noise audio applications?**

The project uses intermediate voltages (±13.5V, +7.5V) that provide only 1.5V-2.5V headroom above the linear regulator outputs. Industry datasheets typically specify 2.0V-2.5V dropout voltage, raising the question of whether this margin is sufficient.

### Answer Summary

✅ **YES - The 1.5V dropout is validated by professional designs and represents proper engineering for audio applications.**

- Real-world professional PSU uses identical -13.5V → -12V (1.5V margin)
- Industry guidelines recommend 1-1.5V headroom for low-noise/precision applications
- The "marginal" dropout is an intentional design choice prioritizing noise reduction over efficiency

---

## Real-World Design Validation

### Professional Implementation: The Gremblog Dual ±12V 48W PSU

**Source:** [The Gremblog - Dual ±12V 48W Linear Power Supply (January 2025)](https://blog.gremblor.com/2025/01/dual-%C2%B112v-48w-linear-power-supply-from-single-sided-dc-input/)

This professional power supply design uses an approach nearly identical to our project:

**Architecture:**

- **Input:** +15V DC (from external power brick)
- **+12V Rail:** Direct linear regulation
  - Input voltage: ~14.5V (after protection)
  - Regulator: TI LM1085 (3A, ~1.5V dropout)
  - Output: +12V
- **-12V Rail:** Two-stage DC-DC + LDO
  - **Stage 1 (DC-DC):** LM3478 Boost Controller in Ćuk converter topology
    - Converts +15V → **-13.5V** at up to 1A
  - **Stage 2 (LDO):** LM2991 linear regulator (0.6V typical dropout)
    - Converts **-13.5V → -12V**
  - **Dropout margin: 1.5V** (identical to our design!)

**Key Design Features:**

- LC input filtering with RC damping
- BJT soft-start circuits (~100ms ramp)
- Type II compensation network for Ćuk converter (~500Hz cutoff)
- 60mΩ current sensing resistor

**Significance:** This validates that professional audio equipment designers choose 1.5V dropout margins for negative rail regulation, confirming our design approach.

### DIY Community Approaches

From ModWiggler forums and DIY audio communities:

- Users report using **adjustable DC-DC converters set to ±16V**, then using **15V LDO linear regulators** to eliminate ripple noise
- Some designs use **LM2596-ADJ modules** followed by linear regulation (matching our approach)
- Typical intermediate voltages: **±13.5V to ±16V** for ±12V outputs

**Common Practice:**

- For 12V systems: Get a ±15V converter and bring it down to 12V with linear regulators
- Provides 2-3V minimum margin above dropout voltage to account for ripple and load variations

---

## Industry Standards and Best Practices

### Dropout Voltage vs. Headroom Voltage

**Critical Distinction:**

- **Dropout Voltage (VDO):** Minimum voltage differential for basic regulation (DC conditions)
- **Headroom Voltage:** Input-to-output differential required for an LDO to meet **all specifications** (PSRR, regulation accuracy, noise)

**Typical Requirements:**

| Application Type | Recommended Headroom | Rationale |
| --- | --- | --- |
| General purpose | 300-400 mV | Basic regulation with margin |
| Optimal PSRR | 500 mV - 1 V | Good ripple rejection vs. power trade-off |
| Low-noise/precision audio | **1 - 1.5 V** | Excellent PSRR and noise performance |

**Our Design:**

- U6 (LM7812): 13.5V → 12V = **1.5V headroom** ✅
- U7 (LM7805): 7.5V → 5V = **2.5V headroom** ✅
- U8 (LM7912): |-13.5V| - |-12V| = **1.5V headroom** ✅

All rails meet or exceed the 1-1.5V recommendation for low-noise audio applications.

### PSRR (Power Supply Rejection Ratio) Performance

**PSRR Degradation with Reduced Headroom:**

At 100 kHz switching frequency:

- **1V → 500 mV headroom:** PSRR drops **5 dB**
- **500 mV → 300 mV headroom:** PSRR drops **>18 dB** (dramatic!)
- **Below 300 mV:** PSRR → 0 dB (unusable for noise rejection)

**Source:** [Analog Devices AN-1120: Noise Sources in Low Dropout (LDO) Regulators](https://www.analog.com/en/resources/app-notes/an-1120.html)

**Implication:** The 1.5V headroom provides excellent PSRR at the LM2596S switching frequency (~150 kHz), enabling effective ripple suppression.

### Load Current Dependency

**Dropout voltage increases with load current** due to internal pass transistor resistance (RDS(on)):

- **Example:** RDS(on) = 1 Ω → VDO = 1 Ω × 170 mA = 170 mV
- **Worst-case dropout:** Calculate at maximum load current and maximum temperature

**Our Design:**

- U6 load: 1.2A (below 1.5A max) → Lower dropout than rated spec
- U8 load: 0.8A (below 1.5A max) → Lower dropout than rated spec

Operating below maximum rated current reduces actual dropout requirements, making the 1.5V margin more conservative than it appears.

---

## Noise Performance Comparison

### Target Specifications

| Application | Ripple Target | Our Design |
| --- | --- | --- |
| Typical Eurorack switching  | 25-120 mVp-p  | **&lt;1 mVp-p** |
| Good DIY linear design | 10-22 mVp-p | **&lt;1 mVp-p** |
| Professional audio | &lt;1 mVp-p | **&lt;1 mVp-p** |
| Ultra-low noise (reference) | 100 µVp-p | Not targeting |

**Our design meets professional audio standards**, significantly exceeding typical modular synthesizer requirements.

### PSRR Specifications

**LM78xx/79xx Series:**

- **LM7812 PSRR:** 55-72 dB at 120 Hz
- **LM7805 PSRR:** 62-78 dB at 120 Hz
- **LM7912 noise:** 200 µV (5× higher than LM7812's 42 µV)

**Frequency Response:**

- **Low frequencies (&lt;1 kHz):** Excellent PSRR (60-80 dB)
- **Mid-range (1-100 kHz):** Error amplifier loop gain provides PSRR
- **High frequencies (&gt;100 kHz):** Output capacitors dominate PSRR

**LM2596S switching frequency:** ~150 kHz → Falls in range where both loop gain and output capacitors contribute to ripple rejection.

### Why Two-Stage Topology Works

From [Rohm Application Note](https://fscdn.rohm.com/en/products/databook/applinote/ic/power/suppression_method_of_switching_noise_an-e.pdf) and [DigiKey Technical Article](https://www.digikey.com/en/articles/understanding-linear-regulator-noise-in-hybrid-power-supplies):

> "Linear regulators tend to provide ripple suppression over a broader range of frequencies, making them useful for suppressing broadband noise from an upstream regulator, which is one reason a linear regulator is often used on the output in this strategy."

> "The LDO filters the switching regulator's ripple-affected regulated output, eliminating potential EMI issues and obviating the requirement to spend long hours refining the PCB design."

**Practical Results:**

- Hybrid designs (DC-DC + LDO) combine efficiency of switching regulators with low-noise characteristics of linear regulation
- Two-stage approach achieves &lt;1mVp-p ripple typical for audio applications
- An LDO with good PSRR after a switching supply is "the way to go if you want clean supplies"

---

## Alternative Regulator Options

### Lower-Dropout Modern LDOs

If even better dropout margin is desired, consider these alternatives:

| Current Part | Alternative | Dropout @ 1A | Output Noise | Benefit |
| --- | --- | --- | --- | --- |
| LM7812 | **LM1085**  | 1.5V | ~50 µV | Lower dropout |
| LM7912 | **LM2991**  | 0.6V | Lower | Much lower dropout |
| LM7805 | (keep) | 2.0V | Good | Already has 2.5V drop |

**The Gremblog design uses LM2991 for the -12V rail**, achieving only 0.6V dropout compared to LM7912's 2.5V requirement.

**Trade-offs:**

- **Pro:** Better dropout margins with same intermediate voltages
- **Pro:** LM2991 has lower noise than LM7912
- **Con:** Different package/footprint may require PCB redesign
- **Con:** Slightly higher cost

**Current design is sound as-is**, but these alternatives exist if optimization is desired.

---

## Design Philosophy: Audio vs. Efficiency

### Why Accept "Marginal" Dropout?

In modular synthesizer and audio applications:

1. **Noise reduction is paramount** - Clean power prevents audio artifacts
2. **Efficiency is secondary** - Power levels are low (&lt;30W total)
3. **Two-stage filtering provides maximum ripple rejection** - DC-DC handles bulk conversion, LDO eliminates switching noise
4. **Thermal management is not limiting** - Heat dissipation at these power levels is manageable

### The Trade-off Spectrum

| Approach | Dropout  | Efficiency | Noise Performance | Thermal Load |
| --- | --- | --- | --- | --- |
| Pure switching DC-DC | N/A | 85-95% | 25-120 mVp-p | Low |
| DC-DC + LDO (4V drop)  | 4.0V | 60-70% | &lt;1 mVp-p | High |
| DC-DC + LDO (2V drop)  | 2.0V | 70-80% | &lt;1 mVp-p | Medium |
| **DC-DC + LDO (1.5V)** | **1.5V** | **75-82%** | **&lt;1 mVp-p** | **Low** |
| DC-DC + LDO (0.6V) | 0.6V | 85-90% | &lt;1 mVp-p | Very Low |

**Our design sits in the "sweet spot":**

- Adequate dropout for excellent noise performance
- Reasonable efficiency for the application
- Manageable thermal dissipation
- Validated by professional implementations

---

## Modular Synthesizer Context

### DIY Culture and Power Budgeting

In the modular synthesizer community:

- **Users are expected to understand power budgets** - No automatic current monitoring needed
- **Power supply quality affects sound** - Clean power is critical for audio fidelity
- **Linear PSUs preferred by many** for lowest noise, despite lower efficiency
- **This is the compact version** - Larger current designs will follow

### Design Constraints

**Target Use Case:**

- Small modular synth system (10-20 modules)
- Current requirements: +12V/1.2A, -12V/0.8A, +5V/0.5A
- Noise-sensitive analog circuits (VCOs, VCAs, filters)

**Why Linear Regulators:**

- **DC-DC alone:** Efficient but noisy (25-120 mVp-p typical)
- **Linear alone:** Clean but inefficient from 15V USB-PD input
- **Two-stage hybrid:** Best of both worlds

**The 1.5V dropout is a conscious design choice** to balance noise performance with thermal management.

---

## Key Takeaways

### Design Validation

1. ✅ **Real-world professional designs use 1.5V dropout** - The Gremblog PSU validates our approach
2. ✅ **Industry guidelines support 1-1.5V headroom** for low-noise/precision applications
3. ✅ **PSRR performance is excellent** at 1.5V headroom (minimal degradation vs. 2V)
4. ✅ **Two-stage topology is industry standard** for audio power supplies
5. ✅ **Target ripple &lt;1mVp-p matches professional audio** requirements

### When to Accept Lower Dropout

**1.5V dropout is appropriate when:**

- Application prioritizes noise over efficiency
- Load currents are below regulator maximum ratings
- Power dissipation at the dropout is thermally manageable
- Switching regulator provides stable intermediate voltage
- Professional audio or precision analog applications

### When to Increase Dropout

**Consider 2V+ dropout if:**

- Input voltage has significant ripple (&gt;100 mVp-p)
- Operating at maximum rated load currents
- Temperature extremes reduce regulator performance
- PSRR requirements exceed standard LDO capabilities
- Safety margin for production variations needed

**For this project:** 1.5V dropout is validated and appropriate.

---

## References

### Professional Designs

- [Dual ±12V 48W linear power supply from single-sided DC input – The Gremblog](https://blog.gremblor.com/2025/01/dual-%C2%B112v-48w-linear-power-supply-from-single-sided-dc-input/)
- [Modular Synth – Dual 12V Power Supply – chillibasket](https://wired.chillibasket.com/2020/06/dual-power-supply/)
- [Green modular, part 1: Energy, carbon, and power supply regulators - North Coast Synthesis](https://northcoastsynthesis.com/news/green-modular-part-1-energy-carbon-and-power-supply-regulators/)

### Technical Application Notes

- [AN-1120: Noise Sources in Low Dropout (LDO) Regulators - Analog Devices](https://www.analog.com/en/resources/app-notes/an-1120.html)
- [Understanding power supply ripple rejection in linear regulators - TI SLYT202](https://www.ti.com/lit/pdf/slyt202)
- [Suppression Method of Switching Noise Using Linear Regulators - ROHM](https://fscdn.rohm.com/en/products/databook/applinote/ic/power/suppression_method_of_switching_noise_an-e.pdf)
- [Understanding Linear Regulator Noise in Hybrid Power Supplies - DigiKey](https://www.digikey.com/en/articles/understanding-linear-regulator-noise-in-hybrid-power-supplies)

### PSRR and Dropout Analysis

- [Understanding Noise and PSRR in LDOs - All About Circuits](https://www.allaboutcircuits.com/technical-articles/understanding-noise-and-psrr-in-ldos/)
- [LDO Operational Corners: Low Headroom and Minimum Load - Analog Devices](https://www.analog.com/en/analog-dialogue/articles/ldo-operational-corners.html)
- [Improved Power-Supply Rejection for Linear Regulators - Analog Devices](https://www.analog.com/en/resources/technical-articles/improved-powersupply-rejection-for-linear-regulators.html)

### Community Resources

- [Eurorack Power Supply Questions - MOD WIGGLER](https://www.modwiggler.com/forum/viewtopic.php?t=182586)
- [Modular Synthesizer Power Supplies and Distribution - Rabid Elephant](https://rabidelephant.com/blogs/general/modular-synthesizer-power-supplies-and-distribution-a-thorough-introduction)
- [Eurorack Power Guide - AI Synthesis](https://aisynthesis.com/eurorack-power-guide/)

### Component Datasheets

- [LM78 Positive Voltage Regulator Datasheet - STMicroelectronics](https://www.st.com/resource/en/datasheet/l78.pdf)
- [Understanding the Terms and Definitions of LDO Voltage Regulators - TI SLVA079](https://www.ti.com/lit/pdf/slva079)
- [Voltage Regulators 78xx and 79xx Family specifications](https://www.electroniclinic.com/voltage-regulators-78xx-and-79xx-family-specifications-and-uses/)

---

## Conclusion

The 1.5V dropout margin used in this power supply design is not "marginal" in the negative sense - it represents **proper engineering for low-noise audio applications**, validated by professional implementations and industry best practices.

The design achieves professional audio noise specifications (&lt;1mVp-p) while maintaining reasonable efficiency and manageable thermal dissipation. The two-stage DC-DC + LDO architecture is industry-standard for combining the efficiency of switching regulators with the clean output of linear regulation.

**For modular synthesizer applications, this approach is optimal.**

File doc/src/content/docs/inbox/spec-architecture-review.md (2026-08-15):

---
title: Spec Architecture Review
sidebar_position: 16
description: Evidence-grounded connectivity review of Board A and Board B against the wave-3 component fact bundles and wave-4 cross-component rules — findings are leads with fact IDs and locators, never verdicts.
---

This page is the wave-5 evidence review of the two-board split (epic #86). Each board
section reviews the locked baseline connectivity against the full fact base: the 20
component bundles (`.claude/skills/component-*`), the 9 cross-component rules
(`.claude/skills/circuit-spec-integration/references/rules.json`), the board baselines
(`scripts/schgen/baselines/`), and the locked decisions in
[Board Split Decision](./board-split-decision.md) (#90).

<Note>

**Findings are leads, never verdicts** (pd-schematic-review method). Every finding cites
the fact IDs and locators behind it; a static connectivity-plus-fact-table pass cannot
measure a waveform, prove a limit, or clear a rail. No v4 board ever completed PD
negotiation, so every downstream electrical claim stays NEEDS BENCH by construction
(`rule-evidence-chain`). Locked #90 items are re-verified but not reopened here.

</Note>

## Board A

### Inputs reviewed

- `scripts/schgen/baselines/board-a.json` (netlist-derived doc-table baseline)
- `usb-pd-input.kicad_sch` in this worktree (the as-fixed sheet after the #93 edits)
- Bundles: `component-stusb4500qtr`, `component-umw-ao3401a-c347476`,
  `component-high-diode-smaj20a-c571370`, `component-usb-type-c-009-c456012`,
  `component-pesd24vs1ub-c85382`, `component-jst-b6b-xh-a`, `component-project-passives`
- Rules: `rule-q1-gate-drive-vs-contract`, `rule-tvs-clamp-vs-absmax`,
  `rule-ab-interface-current`, `rule-evidence-chain`
- Locked decisions: #90 fix list (A1–A6) and the A↔B interface contract

### Locked items re-verified — baseline, bundles, and schematic agree

Each row was checked against the baseline nets, the owner bundle's board-a facts, and
(where the property survives a text-level read) the as-fixed `usb-pd-input.kicad_sch`.
No locked item is reopened; contradictions that are conditional on a 20 V contract are
carried as leads BA-1/BA-4 for the wave-6 decision task.

| Locked item | Evidence checked | Result |
|---|---|---|
| A1 CC topology (CCDB↔CC 0R links, R17/R18 DNP) | Baseline `CC1`/`CC2`/`CC1DB`/`CC2DB` rows; `fact-stusb-cc-termination`; `fact-usb-type-c-009-cc-topology`; `int-stusb-cc-termination`; sch properties R17/R18 `dnp yes` + `in_bom no` (C23186), R19/R20 fitted 0 Ω (C21189); D4 has zero references left in the sheet | Consistent across all three sources. Wire-level rewiring of R19.2/R20.2 onto the CC nets is **not** netlist-verifiable in this pass (no `kicad-cli` on this machine) — see coverage limits |
| A3 pin-18 network (`VBUS_IN → R14 470 Ω → U1.18`, no divider) | Baseline `VBUS_VS_DISCH` row (`U1.18 R14.2 TP6.1`); `fact-stusb-pin18-path`; `fact-c23179-topology`; sch R14 Value `470ohm`/C23179; discharge current 15 V/470 Ω ≈ 32 mA and 20 V/470 Ω ≈ 43 mA, both inside the 50 mA cap (`fact-stusb-vbus-vs-disch`) | Consistent; matches the locked A3 text. Clamp-event corner carried in BA-8 |
| A2 D5 SMAJ20A on VBUS_IN | Baseline `VBUS_IN` row (`D5.1`) + `GND` row (`D5.2`); `fact-smaj20a-d5-nets` (cathode on VBUS_IN); sch D5 Value `SMAJ20A_C571370`, fitted | Present and oriented per the locked decision (cathode = pin 1 on VBUS_IN). Clamp/standoff arithmetic carried in BA-2/BA-4 |
| J4 interface contract (pins 1–2 +15V, 3 ATT, 4 PDOK, 5–6 GND) | Baseline `VBUS_OUT` (`J4.1 J4.2`), `ATT` (`U1.11 J3.6 J4.3`), `PDOK` (`U1.20 J3.7 J4.4`), `GND` (`J4.5 J4.6`); `fact-stusb-interface-flags`; `fact-jst-b6b-xh-a-locked-contract`; pin-map rows ATTACH=11, POWER_OK2=20 | Baseline conforms to the locked pinout exactly; both flags are open-drain with no on-board pull-up, per contract. J4 exists only in the baseline — the legacy sheet has J1/J2/J3 only, which matches the "no Board A KiCad project yet" state (`cov-stusb-board-a-netlist`) |
| NVM provisioning (J2 pogo, I2C pull-ups) | Baseline `SCL-pin1` (`U1.7 R15.1 J2.1`), `SDA-pin2` (`U1.8 R16.1 J2.2`), `GND` (`J2.3`); `fact-c23162-topology` (R15/R16 4.7 kΩ); `int-stusb-safe-power` | Wiring consistent; J2.4 NC per the Board A doc. The pull-up *rail choice* (VREG_2V7) is lead BA-6 |
| Decoupling set | Baseline: C1 (10 µF, C13585, 50 V) + C2 (100 nF, C1711, 50 V) on `VBUS_IN`/VDD; C30 (1 µF, C15849) on `VREG_2V7`; C34 (1 µF) on `Net-(U1-VREG_1V2)`; C35 (100 nF) on the gate node; all voltage-rating facts 50 Vdc (`fact-c13585-voltage`, `fact-c1711-voltage`, `fact-c15849-voltage`) | All present and connected; cap ratings clear the 15 V rail and the 32.4 V clamp table point. Conformance to DS12499's *required* decoupling values is not checkable — the bundle retains no such requirement fact (coverage limits). Value-label drift on C30/C34 is lead BA-9 |
| Unused-pin set | Baseline `GND` row vs pin-map: RESET(6, active-high) grounded = run; ADDR0/1(12/13) grounded = I2C 0x28; VSYS(22) grounded ("ground if unused"); EP(25) grounded. Floating: 3 (NC), 14 (POWER_OK3), 15 (GPIO), 17 (A_B_SIDE), 19 (ALERT) — all open-drain outputs, float-safe (`fact-stusb-pin-states`) | Safe as wired; no unconnected input found |

### Clamp-event stress topology

The single highest-leverage net on Board A is `VBUS_IN`: a D5 clamp event at the
32.4 V table point reaches the STUSB4500's high-voltage pins and the Q1 gate divider
through the paths below (which pins are exposed depends on the Q1/VBEN state — see
BA-2). This diagram is the net-level view behind findings BA-1/BA-2.

```mermaid
flowchart TD
  D5["D5 SMAJ20A clamp\n32.4 V max table point\n(fact-high-diode-smaj20a-clamp)"] ---|"VBUS_IN"| VBUS["VBUS_IN net"]
  VBUS -->|"direct"| VDD["U1.24 VDD\nabs-max 28 V (mirror)"]
  VBUS -->|"R14 470R, sense input"| P18["U1.18 VBUS_VS_DISCH\nabs-max 28 V (mirror)"]
  VBUS -->|"R11 100k pull-up"| GATE["Q1 gate node\nNet-(Q1-G)"]
  GATE -->|"R12 56k, VBEN Hi-Z"| VBEN["U1.16 VBUS_EN_SNK\nabs-max 28 V (mirror)"]
  GATE -->|"Vgs = -VBUS x 100/156\nwhen VBEN asserted"| Q1G["Q1 gate-source\nabs-max +/-12 V"]
  VBUS -->|"Q1 on: VBUS_OUT tracks VBUS_IN"| VOUT["VBUS_OUT net"]
  VOUT -->|"R13 470R"| DISCH["U1.9 DISCH\nabs-max 28 V (mirror)"]
  VOUT -->|"J4.1 / J4.2"| BOARDB["Board B via A-B cable\nLM2596 VIN abs-max 45 V:\n12.6 V margin at table point"]
```

### Findings — leads ranked by severity

#### BA-1 — Q1 gate divider exceeds the Vgs abs-max at a 20 V contract (crossover ≈18.7 V); the factory-NVM 20 V window is unguarded in hardware (BLOCKER-class lead)

With VBEN asserted low, the R11/R12 divider sets `Vgs = -VBUS x R11/(R11+R12)` =
−VBUS × 0.641, crossing the ±12 V abs-max at VBUS ≈ 18.7 V (12 × 156/100):

- 15 V contract: **−9.62 V**, 2.38 V of margin to the ±12 V abs-max — legal.
- 20 V contract: **−12.82 V**, **0.82 V past the abs-max** — the deterministic
  BLOCKER fact.
- D5 clamp table point (32.4 V) while VBEN is asserted: **−20.77 V**, 8.77 V past
  abs-max (new arithmetic this pass — same divider, transient-class; companion to the
  already-recorded off-state VDS overage in BA-2).

Net-level analysis of when the 20 V case is reachable: VBEN asserts only on a live
contract, and a **factory-default (unprogrammed) STUSB4500 advertises PDO3 = 20 V/1 A
at highest priority** ([NVM Programming Setup](./nvm-programming.md), factory-defaults
table). Board A's build order is assemble → program NVM via J2 → use; on the first
plug-in of an unprogrammed board into a 20 V-capable charger, this divider exceeds Q1's
gate rating with **no hardware interlock** — the only guard is the procedural "use a
5 V-only charger for the programming session" instruction. The locked #90 warning
"do not touch the Q1 gate network — re-confirmed correct by #87/#89" holds **at the
15 V contract only**; this is not a reopen — the wave-6 20 V-contract decision task
owns the disposition (reprogram-before-first-attach gate, divider change, clamp, or
other mitigation).

Evidence: `fact-umw-ao3401a-vgs` (±12 V abs-max, PRIMARY-SPEC, page 1 abs-max table row
VGS), `fact-c25803-resistance` (100 kΩ) + `fact-c23206-resistance` (56 kΩ),
`fact-umw-ao3401a-gate-resistor-values` (sch instance values),
`fact-umw-ao3401a-vgs-pdo3-margin` (−0.8205 V margin, verdict "BLOCKER - deterministic
spec violation"), `rule-q1-gate-drive-vs-contract` / `calc-q1-vgs-margin-vben-low`
(reproduces −0.8205 at 20 V, +2.3846 at 15 V), `fact-high-diode-smaj20a-clamp` (32.4 V
table point), `fact-stusb-gate-network` (network topology).

#### BA-2 — a D5 clamp event reaches four distinct STUSB4500 high-voltage pins past the 28 V mirror-only abs-max (three at a time, by Q1 state), plus Q1 VDS (HIGH lead, mirror-conditioned)

`calc-tvs-d5-clamp-vs-stusb-vdd` records the 32.4 − 28 = **4.4 V overage** against VDD.
The net-level extension this pass adds: `VBUS_IN` reaches **U1.24 (VDD) directly** and
**U1.18 via R14** (high-impedance sense — no meaningful drop) in every state. The other
two exposures are state-dependent: with Q1 **off** (VBEN Hi-Z), **U1.16** floats to the
clamp voltage through R11+R12 (open-drain, no current); with Q1 **on** (VBEN actively
driven low — U1.16 itself safe), `VBUS_OUT` tracks `VBUS_IN` and reaches **U1.9 via
R13**. So each clamp event stresses three pins past the shared 28 V grouped abs-max
row, and four distinct pins are exposed across the two states. The off-state Q1 VDS overage (32.4 V vs −30 V,
2.4 V past) is `calc-tvs-d5-clamp-vs-q1-vds` and was **acknowledged as an accepted
residual in #90 A2 — but only for Q1**; the #90 residual text does not mention the
STUSB4500 28 V family at all. Downstream, the LM2596 keeps 12.6 V of margin at the
table point (`calc-tvs-d5-clamp-vs-lm2596-vin-absmax`).

Severity is capped at HIGH, not BLOCKER: the 28 V limit is **mirror-only evidence**
(see the cross-cutting caveat below), and 32.4 V is a 10/1000 µs table point at
12.3 A — not the installed surge waveform (`rule-tvs-clamp-vs-absmax`, verdict
UNSOURCED). Wave-6 input: either accept as transient-class residual with the mirror
caveat recorded, or pick a lower-clamp part during Board A layout (the #90 text itself
floats SMBJ20A as an upgrade).

Evidence: `fact-high-diode-smaj20a-clamp` (32.4 V, PRIMARY-SPEC),
`fact-stusb-vdd-absolute-max` + `fact-stusb-vbus-pin-absolute-max` (28 V, UNSOURCED
mirror), `fact-umw-ao3401a-vds` (−30 V, PRIMARY-SPEC), `calc-tvs-d5-clamp-vs-stusb-vdd`
(4.4), `calc-tvs-d5-clamp-vs-q1-vds` (2.4), baseline nets `VBUS_IN`, `VBEN`,
`Net-(Q1-G)`, `VBUS_OUT`, `Net-(U1-DISCH)`.

#### BA-3 — the Board A doc's "Electrical limits to respect" section contradicts the fact base (HIGH lead, doc defect — agent-found issue raised)

[Board A — USB-PD Core](../overview/board-a-usb-pd-core.md), reuse-guidance section,
states: "`VBUS_IN`/VDD abs-max is 22 V (DS12499)" and that D5's ≤32.4 V clamp was
chosen "specifically to sit under that ceiling with margin". Against the fact base,
both halves fail:

- 22 V is the top of VDD's **operating** range (`fact-stusb-supplies`, Table 21) and
  the **CC-pin** abs-max (`fact-stusb-cc-absolute-max`, Table 20); the VDD abs-max row
  is **28 V** (`fact-stusb-vdd-absolute-max`).
- 32.4 is greater than 28 is greater than 22 — the clamp table point sits **above**
  every one of those ceilings, not under any of them (`calc-tvs-d5-clamp-vs-stusb-vdd`).

The same section's reuse guidance says a reuse project may reprogram the NVM up to
20 V "as long as D5's 20 V standoff and Q1's ratings … still cover the new target
voltage", while listing only Q1's VDS/current rating — at 20 V the gate divider already
exceeds Q1's Vgs abs-max (BA-1) and D5's standoff margin is zero (BA-4), so the
guidance points a reuse reader at exactly the unsafe corner. This is a wave-3 doc
(#91), not a locked #90 decision, so it is a fixable doc defect, raised as agent-found
issue #130 rather than folded into the locked fix list.

Evidence: `fact-stusb-supplies`, `fact-stusb-cc-absolute-max`,
`fact-stusb-vdd-absolute-max`, `calc-tvs-d5-clamp-vs-stusb-vdd`,
`fact-umw-ao3401a-vgs-pdo3-margin`, `calc-tvs-d5-standoff-vs-pdo`; locator:
`doc/src/content/docs/overview/board-a-usb-pd-core.md`, "Electrical limits to respect"
and "NVM reconfiguration for other voltages" blocks.

#### BA-4 — D5 standoff has zero margin at a 20 V contract; minimum breakdown is only 2.2 V above it (MEDIUM lead)

`calc-tvs-d5-standoff-vs-pdo`: 5 V of standoff margin at the 15 V contract, **0 V at
20 V**. At exactly 20 V the part sits at its VRWM edge — leakage is specified at
precisely that voltage (5 µA, `fact-high-diode-smaj20a-leakage`) and any source
overshoot walks into the 22.2–24.5 V breakdown band
(`fact-high-diode-smaj20a-breakdown`). The #90 A2 justification "stays non-conducting
through the 20 V mis-contract edge case" is true only at exactly 20.0 V with zero
tolerance for overshoot — #90 itself flagged a 15 V-standoff part at 0% margin as "the
exact mistake #89 flagged for TVS2/SD05", and a 20 V contract reproduces that same 0%
condition one step up. Not a reopen (the fitted rail is 15 V by locked contract, where
the 33% margin claim holds); this is a numeric input to the wave-6 20 V-contract
decision alongside BA-1.

Evidence: `fact-high-diode-smaj20a-standoff` (20 V VRWM, PRIMARY-SPEC),
`fact-high-diode-smaj20a-breakdown`, `fact-high-diode-smaj20a-leakage`,
`calc-tvs-d5-standoff-vs-pdo` (0 V margin at vbus_v 20).

#### BA-5 — USB-C receptacle: 15 V contract is 3× the mirror's 5 V rating, 3 A is its zero-margin current cap, and the part identity is unsourced (MEDIUM lead, NEEDS BENCH)

The only voltage evidence for J1 (LCSC C456012) is a mirror approval spec's RATING row
of **5 V / 3 A** (`fact-usb-type-c-009-rating-voltage`,
`fact-usb-type-c-009-rating-current`, both UNSOURCED). The negotiated contract applies
15 V at up to 3 A: three times the voltage row, and exactly the current row with zero
margin (`fact-usb-type-c-009-pd-contract-stress`, NEEDS BENCH). The AC 100 V dielectric
test row suggests insulation headroom but is a test stress, not a working-voltage
rating (`fact-usb-type-c-009-dielectric`). Identity itself is degraded: the project MPN
label `USB-TYPE-C-009` matches no manufacturer or distributor document — the LCSC
catalog model is `TYPE-C 6P` — so the confirmed-distributor-identity lane is closed
(`fact-usb-type-c-009-distributor-binding`). The same 3 A cap is shared by the
A↔B interface's arithmetic (`rule-ab-interface-current`: 1.6× derated margin on J4's
paired contacts, but the receptacle itself carries 3 A at 1.0×). Bench engineering
acceptance at 15 V on the dead v4 boards is the stated gate.

Evidence: fact IDs above plus `rule-ab-interface-current` /
`calc-ab-derated-margin-ratio` (1.6) and `fact-jst-b6b-xh-a-current-derating-math`.

#### BA-6 — VREG_2V7 carries an external DC load DS12499 does not authorize (MEDIUM lead, NEEDS BENCH)

Pin 23 is documented as 2.7 V regulator **decoupling only**, yet the baseline hangs
R15/R16 (4.7 kΩ I2C pull-ups) and debug pad J3.3 on it (`fact-stusb-vreg2v7-load`,
`cov-stusb-vreg2v7-load`). Each asserted-low I2C line sinks ≈0.57 mA (2.7 V/4.7 kΩ)
from the internal regulator — ≈1.15 mA with both lines low, sustained during NVM
programming traffic. Open companions: whether the NVM jig (NUCLEO-F072RB, 3.3 V logic)
is happy with a 2.7 V pull-up rail (its VIH is ≈2.3 V — thin margin), and the SCL/SDA
pin abs-max, which the bundle does not retain at all. Wave-6/bench item: either confirm
the load empirically on a dead v4 board (the identical network is fitted there) or move
the pull-ups to a rail ST's reference designs use.

Evidence: `fact-stusb-vreg2v7-load` (NEEDS BENCH), `int-stusb-netlist` (UNSOURCED),
`fact-c23162-topology`/`fact-c23162-resistance`, baseline `VREG_2V7`/`SCL-pin1`/
`SDA-pin2` rows.

#### BA-7 — a fitted D6/D7 (PESD24VS1UB) clamps only above the CC pins' 22 V abs-max (LOW/MEDIUM lead, scope clarification)

The DNP CC-ESD provision's numbers: VRWM 24 V (`fact-pesd24vs1ub-standoff`), breakdown
26.5–27.5 V (`fact-pesd24vs1ub-breakdown`), clamp 36 V at 1 A / 70 V at 3 A
(`fact-pesd24vs1ub-clamp-1a`, `fact-pesd24vs1ub-clamp-3a`) — every conduction threshold
sits above the STUSB4500 CC-pin abs-max of 22 V (`fact-stusb-cc-absolute-max`,
mirror-only). This is *deliberate* per #90 A2 (the part must never become the weakest
link during a CC-short-to-VBUS fault) and is not a reopen — but the flip side deserves
recording: when fitted, D6/D7 provide **fast-ESD energy diversion only**; they cannot
hold any sustained overvoltage below the pin rating, and during a rated 8/20 µs surge
the CC pin still sees up to the 36 V clamp. CC-line protection therefore rests entirely
on U1's integrated structures in every DC/quasi-DC scenario, exactly as the fitted
(no-D6/D7) build does.

Evidence: fact IDs above plus `fact-pesd24vs1ub-dnp-provision` (DNP state, NEEDS
BENCH).

#### BA-8 — R13/R14 discharge-pulse dissipation is unspecified for the fitted 0.1 W parts (LOW lead, NEEDS BENCH)

Both 470 Ω resistors are 0603, 0.1 W rated (`fact-c23179-power`). During active
discharge with the rail still up, instantaneous dissipation is V²/470: **0.48 W at
15 V, 0.85 W at 20 V** — 4.8× to 8.5× the continuous rating. Discharge windows are
bounded (0x25 defaults: 800 ms to 0 V, 270 ms transition — `fact-stusb-discharge-registers`)
and the cap-bleed case is energy-trivial, but the resistor spec retains **no
installed-waveform pulse rating** — only the 5 s short-time-overload test
(`fact-c23179-pulse-caveat`, NEEDS BENCH). Current stays inside the pin's 50 mA cap at
both contract voltages (32 mA / 43 mA, `fact-stusb-vbus-vs-disch`); a discharge
coinciding with a clamp event would reach 69 mA (32.4 V/470 Ω), above the cap —
transient-class corner only. Bench scope note for the repeated attach/detach test.

Evidence: `fact-c23179-power`, `fact-c23179-resistance`, `fact-c23179-pulse-caveat`,
`fact-stusb-vbus-vs-disch`, `fact-stusb-discharge-registers`, baseline
`VBUS_VS_DISCH`/`Net-(U1-DISCH)` rows.

#### BA-9 — C30/C34 Value fields read "1uF 16V" but C15849 is a 50 V part (LOW lead, label drift)

The worktree `usb-pd-input.kicad_sch` carries `Value "1uF 16V"` on both C30 and C34
(LCSC C15849 = Samsung CL10A105KB8NNNC), while the primary-sourced rating is **50 Vdc**
(`fact-c15849-voltage`). Same class as the locked C4/C22/C23 value-label fix (#90 A5,
"prevents a future reviewer trusting the wrong label"), in the conservative direction
this time (label understates), electrically irrelevant on the 2.7 V/1.2 V nodes.
Netlist-neutral candidate for the same treatment at the next KiCad edit window — not
added to the locked #93 list by this review. The Board A doc's component table repeats
the 16 V label.

Evidence: `fact-c15849-voltage` (PRIMARY-SPEC); locator: `usb-pd-input.kicad_sch`
symbol property rows C30/C34; `doc/src/content/docs/overview/board-a-usb-pd-core.md`
component table.

#### BA-10 — the Board A doc still claims the fix list was never written back to KiCad (LOW lead, staleness — folded into agent-found issue #130)

[Board A — USB-PD Core](../overview/board-a-usb-pd-core.md) (net-table preamble) says
the #90 deltas were "applied on paper … none of this was written back into the KiCad
file". The as-fixed sheet in this worktree now carries them: D4 deleted (zero
references), D5 fitted as `SMAJ20A_C571370`/C571370, R17/R18 DNP + excluded from BOM,
R19/R20 fitted 0 Ω. The sentence predates #93 landing and now misleads a reader about
which artifact is authoritative.

Evidence: property-level reads of `usb-pd-input.kicad_sch` (this pass); locator:
`doc/src/content/docs/overview/board-a-usb-pd-core.md`, "Net-connectivity table (fixed
circuit)" intro paragraph.

### Cross-cutting caveat — every STUSB4500 limit above is mirror-only

Direct manufacturer-primary retrieval of DS12499 and UM2650 from st.com failed on both
attempt dates (2026-08-02, 2026-08-14); the retained bytes are reproducible mirrors
(`fact-stusb-ds12499-primary-attempt`, `fact-stusb-um2650-primary-attempt`, both
UNSOURCED). Every 28 V / 22 V abs-max and 4.1–22 V operating claim in BA-1 through BA-7
inherits that status: the arithmetic is deterministic, but the limits it compares
against are not primary-confirmed. This is why no finding above escalates past
BLOCKER-class *lead*.

### What this pass can and cannot catch

**Can catch (and did):** baseline-vs-bundle-vs-doc connectivity disagreements;
deterministic arithmetic on retained fact values (divider ratios, margins, overages);
locked-decision conformance of the baseline (J4 pinout, CC topology, pin-18 path);
property-level schematic state (DNP flags, BOM exclusion, Value/LCSC fields, symbol
presence/absence); doc text contradicting retained facts; unconnected-pin safety from
pin-function tables.

**Cannot catch:**

- **Wire-level netlist truth of the as-fixed sheet.** No `kicad-cli` exists on this
  machine, so the R19/R20 rewiring, D5 pin-to-net orientation, and every other
  geometry-borne connection in `usb-pd-input.kicad_sch` were verified only at the
  property level plus the (older, 2026-07-05) netlist-derived doc tables. A fresh
  netlist export diffed against `board-a.json` (`scripts/schgen/check_baseline.py`)
  remains open.
- **Anything bench-stage.** No rail has ever been energized from a negotiated contract
  (`rule-evidence-chain`: PCB orientation, BOM/CPL, as-built, programmed, and bench
  stages all OPEN). Waveforms — gate soft-start, clamp events, discharge pulses,
  inrush — are all unmeasured.
- **Mirror-limit truth.** BA-1/BA-2/BA-7's comparison ceilings are mirror-only; a
  primary DS12499 retrieval could move them.
- **Facts the bundles do not retain:** STUSB4500 SCL/SDA pin abs-max; DS12499's
  required decoupling values; the USB-PD CC-line capacitance budget (relevant to the
  J3.1/J3.2 debug stubs and a fitted D6/D7's 50 pF); NVM write endurance
  (`fact-stusb-endurance`); receptacle CC-pad continuity (a ranked v4 root-cause
  candidate, bench-gated).
- **Layout-phase items:** pogo-pad adjacency risk (J3.4 carries raw VBUS one pad away
  from the 2.7 V VREG_2V7 pad J3.3 — a probe slip is an unfused 15 V-into-2.7 V
  event), footprint geometry, thermal copper. Board A has no layout yet.

## Board B

### Inputs reviewed

- `scripts/schgen/baselines/board-b.json` (netlist-derived doc-table baseline; its
  output-stage nets are deliberately `unresolved` — see coverage limits)
- `dc-dc-conversion.kicad_sch`, `linear-regulation.kicad_sch`, `output.kicad_sch` in
  this worktree (as-fixed after the #93 edits, commit `1e053e1`)
- Bundles: `component-lm2596s-adj-c347423`, `component-l7812cd2t-c13456`,
  `component-l7805abd2t-c86206`, `component-cj7912-c94173`,
  `component-ptc-smd1210p200tf-c20808`, `component-ptc-msmd110-33v-c70119`,
  `component-ptc-bsmd1206-150-16v-c883133`, `component-sd05-c502527`,
  `component-smaj15a-c571368`, `component-ss34-c8678`,
  `component-cya1265-100uh-c19268674`, `component-project-passives`,
  `component-faston-c591344`, `component-hdr-2541wr-2x08p-c5383092`,
  `component-jst-b6b-xh-a`
- Rules: `rule-rail-envelope`, `rule-u4-inverting-stress`, `rule-ldo-dropout-chain`,
  `rule-pptc-vmax-vs-rail`, `rule-tvs-clamp-vs-absmax`,
  `rule-inverting-startup-vs-pd-source`, `rule-ab-interface-current`,
  `rule-evidence-chain`
- Locked decisions: #90 A5/A6 (Board B dispositions and #93 rows 6–8) and the A↔B
  interface contract

### Locked items re-verified — baseline, bundles, schematic, and fix-commit agree

| Locked item | Evidence checked | Result |
|---|---|---|
| DC-DC feedback dividers (13.53 / 7.503 / −13.53 V setpoints) | Sch values R1 `10k`/R2 `1k`, R3 `5.1k`/R4 `1k`, R5 `10k`/R6 `1k` (property reads, all matching `fact-lm2596-u2-r1` … `fact-lm2596-u4-r6`); `Vout = 1.23 × (1 + Rtop/Rbottom)` reproduces 13.53 / 7.503 / 13.53-magnitude (`fact-lm2596-u2-vout-setpoint`, `fact-lm2596-u3-vout-setpoint`, `fact-lm2596-u4-vout-setpoint-magnitude`); setpoint-vs-target errors +0.03 / +0.003 / −0.03 V (`calc-rail-u2/u3/u4-setpoint-error`); feedforward caps C31/C32/C33 22 nF placed across each high-side divider leg (`fact-c1729-topology`, baseline FB rows) | Consistent everywhere; all three magnitudes inside the 1.2–37 V ADJ range (`fact-lm2596-vout-adjust-range`). Rail truth stays NEEDS BENCH per `rule-rail-envelope` — tolerance-stack corners feed BB-5 |
| U4 inverting referencing (LOCKED — verify only) | Baseline `-13.5V OUT` row (`U4.3 U4.5 U4.6 D3.2 C9.2 C10.2 C11.2 R6.2 …`), `GND` row (`L3.2`), `Net-(D3-K)` (`U4.2 D3.1 L3.1`); `fact-lm2596-u4-inverting-nets`; ON/OFF at 0 V relative to the device GND pin = ON (`fact-lm2596-onoff-thresholds`, `fact-lm2596-onoff-inverting-note`); catch-diode sense D3.1 = K on the switch node, D3.2 = A on the negative output — the manufacturer-documented inverting arrangement (`fact-lm2596-inverting-topology-support`) | Verified, not reopened. Inductor-to-system-GND / diode-to-output arrangement is the mirror of U2/U3, exactly as the sheet doc states |
| #93 row 6 — `Net-(C16-Pad2)` → GND merge | Commit `1e053e1` message + diff (adds GND power symbol `#PWR054` to `linear-regulation.kicad_sch`); baseline `GND` row carries `C16.2 C24.1 C19.2 C25.1`; board-b-synth-power.md "Negative-rail decoupling" note | Applied at commit-diff + property level. Wire-level attach of all four plates is netlist-borne — open (no `kicad-cli`, see coverage limits) |
| #93 row 7 — C9 swap to 100 µF 50 V | Sch C9 Value `100uF 50V`, `LCSC Part` C970687, Datasheet `lcsc.com/datasheet/C970687.pdf`, Footprint `CAP-SMD_BD8.0-L8.3-W8.3-LS9.0-FD` (the 8×10.2 can) | Applied in full. The placed lib_id string still reads `RVT1E101M0607_C22383804` (the replaced 25 V part's name) — cosmetic drift, folded into BB-14 |
| #93 row 8 — C4/C22/C23 Value fix | All three read `470uF 10V` (property reads) | Applied. The deeper LCSC-field/drawn-symbol identity tangle is recorded by the bundle (`fact-c22383803-canonical-choice`) — BB-14 |
| J5 A↔B interface contract | Pinout tables in board-split-decision.md, board-a-usb-pd-core.md, and board-b-synth-power.md are byte-identical (md5-verified this pass); J5 absent from every sheet, matching the "connector does not exist in the netlist yet" doc state; 1.6× derated margin arithmetic reproduced by `calc-ab-derated-margin-ratio` | Conformant. Margin stays NEEDS BENCH (`rule-ab-interface-current`: harness unbuilt, derating assumed) |
| Output stage — Faston assignment + J10/J11 GND moat | Doc tables only: J6=−12V, J7=+12V, J8=+5V, J9=GND (`fact-faston-rail-assignment`); J10/J11 pins 9–14 six-pin GND moat, −12V on 15–16 far from signals (`fact-hdr-pin-pair-assignment`, `fact-hdr-gnd-moat-interactions`, `fact-hdr-misalignment-safety-note`) | Structure conforms to the Doepfer convention at doc level. **Not baselined**: every output-stage net is in `board-b.json`'s `unresolved` list, so no Ref.Pin verification exists — carried as a standing gap (coverage limits), with header key orientation NEEDS BENCH (`fact-hdr-keying-not-netlist-verifiable`) |
| Electrolytic polarity on the resolved nets | Baseline pin sides: C21.1/C25.2 on the ±12 V outputs, C21.2/C25.1 on GND; C24.2 on `-13.5V OUT`, C24.1 on GND; C11.2 on `-13.5V OUT`; C12.2 on `-13.5V OUT`, C12.1 on GND (decision `neg-rail-cap-bank`, mirrors C24) | Positive-plate-to-higher-potential convention holds on every resolved electrolytic, including the negative-rail mirror pattern |

### The two highest-leverage nets — +15 V input bus and the −13.5 V loop

Board B's stress concentrates on the shared +15 V input bus (three converters, the
C9/C10 bridge, and the only path a Board A clamp event can take into Board B) and on
the −13.5 V loop, where U4's bootstrapped ground makes every voltage additive. This
diagram is the net-level view behind BB-3/BB-5/BB-6/BB-7.

```mermaid
flowchart TD
  J5["J5 pins 1-2\n+15V from Board A\n(3.0 A contract cap)"] -->|"+15V bus"| BUS["+15V -> +13.5V gen net\nC5/C7 100uF 25V\nC6/C8 100nF 50V"]
  BUS --> U2["U2 buck -> +13.5V\nVIN sees 15 V"]
  BUS --> U3["U3 buck -> +7.5V\nVIN sees 15 V"]
  BUS --> U4["U4 inverting -> -13.5V\ndevice sees VIN + 13.53 V = 28.53 V\n45.93 V at the 32.4 V clamp table point"]
  BUS ---|"C9 100uF 50V + C10 100nF 50V\nbridge +15V to -13.5V"| N135
  U4 -->|"-13.5V OUT\n(U4 GND/ON-OFF/TAB ride here)"| N135["-13.5V rail\nC11 + C24 + C12 output bulk"]
  U2 -->|"+13.5V OUT"| U6["U6 L7812\n1.5 V headroom vs 2.0 V typ dropout"]
  U3 -->|"+7.5V OUT"| U7["U7 L7805\n0.5 V typ headroom at 5.0 V out"]
  N135 --> U8["U8 CJ7912\ninput 1.0 V outside guaranteed band"]
  U6 -->|"Net-(U6-OUT)"| PTC1["PTC1 SMD1210P200TF\nVmax 6 VDC on a 12 V rail"]
  U7 -->|"Net-(U7-OUT)"| PTC2["PTC2 33 V - clears"]
  U8 -->|"Net-(U8-OUT)"| PTC3["PTC3 16 V\n4 V nominal margin"]
  PTC1 -->|"+12V rail (unresolved)"| OUT["TVS1/TVS2/TVS3, J6-J11\n(no Ref.Pin baseline)"]
  PTC2 --> OUT
  PTC3 --> OUT
```

### Findings — leads ranked by severity

#### BB-1 — PTC1's 6 VDC maximum voltage sits on the +12 V rail: −6 V margin under normal operation, replacement required before any rail power-on (BLOCKER-class lead)

The fitted RUILON `SMD1210P200TF` (LCSC C20808) is rated **Vmax 6 VDC** — the
unsuffixed family member — while it protects the +12 V output. A tripped PPTC absorbs
its full rail voltage, so every trip applies twice its rating; the datasheet's own
cautions name arcing/flame as the exceed-Vmax failure mode. This is deterministic and
primary-sourced on both sides (`fact-ptc1-vmax`, PRIMARY-SPEC, RUILON SMD1210 spec
table + LCSC listing text; `fact-ptc1-vmax-margin` = −6 V, "BLOCKER - deterministic
spec violation"; `calc-pptc1-vmax-margin` reproduces −6). The rule's refusal is
explicit: *replace PTC1 with a part rated at or above the +12 V rail before any rail
power-on* (`rule-pptc-vmax-vs-rail`). The passthrough corner is worse than nominal: a
tripped PTC1 with U6 out of regulation can see up to ≈13.5 V.

Replacement leads already in evidence: the same RUILON datasheet lists 16 V-suffixed
siblings of adjacent current ratings (`SMD1210P150TF/16`, `SMD1210P110TF/16` — bundle
SKILL.md, suffixed-variants note), and the legacy `components/ptc-12v.md` page (since
deleted; the content now lives in `overview/board-b-synth-power.md`'s Protection Stage
table) *already documented* the P150TF/16 (see BB-10). Trade-off to carry into wave-6: P150TF/16's 1.5 A hold leaves
0.3 A of margin over the 1.2 A rail rating (vs the P200TF's 0.8 A,
`fact-ptc1-ihold-margin`) and its 85 °C derated hold will sit proportionally lower
(the P200TF's own 85 °C figure is 0.98 A, `fact-ptc1-hold-85c` — already below the
1.2 A rail rating; see BB-8). Wave-6 owns the part pick; this pass records that **no
currently-fitted-part disposition exists** — #90's protection-stage text predates the
Vmax confirmation and the board-b doc still calls it an open data gap.

Evidence: `fact-ptc1-vmax`, `fact-ptc1-vmax-margin`, `fact-ptc1-ihold`,
`fact-ptc1-ihold-margin`, `fact-ptc1-hold-85c`, `calc-pptc1-vmax-margin`,
`rule-pptc-vmax-vs-rail` (refusal text); sch property read PTC1 =
`SMD1210P200TF`/C20808, fitted; locator: bundle SKILL.md suffixed-sibling paragraph.

#### BB-2 — TVS2 SD05 stands off exactly 5 V on a rail whose guaranteed band tops at 5.2 V: zero margin at nominal, −0.2 V inside normal regulation (BLOCKER-class lead, locked deferral re-verified)

`fact-sd05-standoff` (5 V, PRIMARY-SPEC) against the L7805's guaranteed output band
(min 4.8 / max 5.2 V, `fact-l7805abd2t-vout-band`): margin is 0 V at 5.0 V and
**−0.2 V at the 5.2 V band top** (`calc-tvs-sd05-standoff-vs-plus5`,
`fact-sd05-plus5-margin` = 0, BLOCKER verdict) — the TVS can conduct inside normal
regulation, with breakdown starting at 6 V min (`fact-sd05-breakdown`). The #90
deferral ("replace with a ≥6 V-standoff part in the Board B design phase") is
re-verified, not reopened: TVS2 is still fitted in the legacy sheet (property read,
`dnp no`), which is consistent with the deferral scope. Three dated replacement
candidates are already primary-sourced in the bundle (all retrieved 2026-08-14):

| Candidate | LCSC | Standoff | Breakdown min | Margin at 5 V | Leakage at VRWM | Stock |
|---|---|---|---|---|---|---|
| MDD SMF6.0A | C123790 | 6 V | 6.67 V | 1.0 V | 400 µA | 148,360 |
| Brightking SMAJ6.5A | C87267 | 6.5 V | 7.22 V | 1.5 V | 500 µA | 8,450 |
| FOSAN SMAJ6.0A | C5353156 | 6 V | 6.67 V | 1.0 V | 800 µA | 6,400 |

All three clear the 5.2 V band top with their breakdown minimum. Note for the wave-6
pick: every candidate leaks 40–80× more than the SD05's 10 µA (`fact-sd05-leakage`) —
a real but budgetable trade on a 500 mA rail.

Evidence: fact IDs above plus `fact-cand-smf6-0a-*`, `fact-cand-smaj6-5a-*`,
`fact-cand-smaj6-0a-*` (standoff/breakdown/clamp/leakage/stock rows),
`rule-tvs-clamp-vs-absmax` (SD05 clause in conditions + refusal).

#### BB-3 — a Board A clamp event puts U4's effective input 0.93 V past its 45 V absolute maximum; the #90 A2 justification "clamp stays inside the LM2596S abs-max (40 V)" does not hold for U4 and mislabels the 40 V operating maximum (HIGH lead, table-point-conditioned)

U4's bootstrapped ground makes its device-seen input `VBUS + |VOUT|`
(`fact-lm2596-u4-effective-input-setpoint` = 28.53 V nominal). Across the VBUS
envelope (`calc-u4-effective-input-envelope` / `calc-u4-absmax-margin-envelope`):
28.53 V at the 15 V contract (16.47 V of margin), 33.53 V at a 20 V mis-contract
(11.47 V), and **45.93 V at the D5 SMAJ20A 32.4 V clamp table point — −0.93 V past
the 45 V absolute maximum** (`fact-lm2596-vin-absmax`, PRIMARY-SPEC;
`fact-high-diode-smaj20a-clamp`, PRIMARY-SPEC). Both compared values are
primary-sourced; what keeps this a lead rather than a verdict is the waveform: 32.4 V
is a 10/1000 µs table point, not the installed surge (`rule-u4-inverting-stress`,
NEEDS BENCH).

The #90 A2 text justifies the SMAJ20A with "the ≤32.4 V clamp stays inside the
LM2596S abs-max (40 V)". Two defects, neither a reopen: (a) 40 V is the *operating*
maximum (`fact-lm2596-vin-operating-max`); the absolute maximum is 45 V; (b) the
comparison is correct for U2/U3 (VIN-to-GND sees 32.4 V directly, 12.6 V under 45 V,
`calc-tvs-d5-clamp-vs-lm2596-vin-absmax`) but wrong in kind for U4, whose stress adds
the output magnitude. This mirrors BA-2's finding shape (the #90 residual text audits
one victim and misses another). C9/C10 (50 V, `fact-c970687-voltage`,
`fact-c1711-voltage`) keep 4.07 V of margin at the same table point — thin but
positive. Wave-6 input alongside BA-2's clamp-part options: a lower-clamp Board A part
(SMBJ20A is already floated in #90) shrinks this overage at its source.

Evidence: fact and calc IDs above; `fact-lm2596-u4-absmax-margin` (nominal 16.5 V),
`rule-u4-inverting-stress` (conditions + refusal), #90 A2 justification text
(board-split-decision.md, "Why a 20 V standoff" bullet).
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

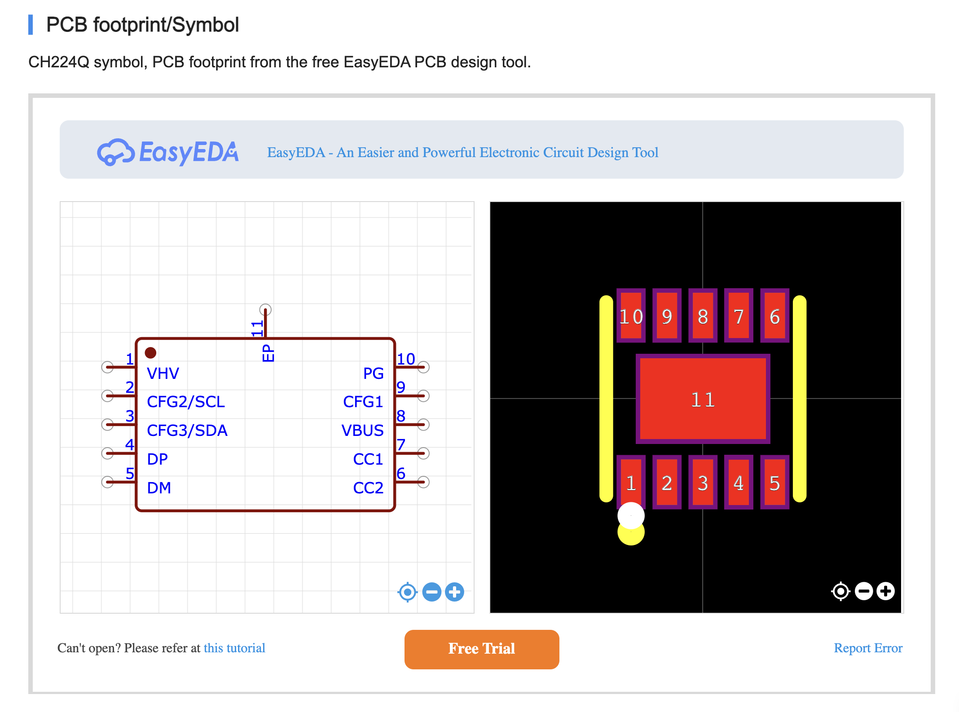
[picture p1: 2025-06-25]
footprints/CH224Q.png

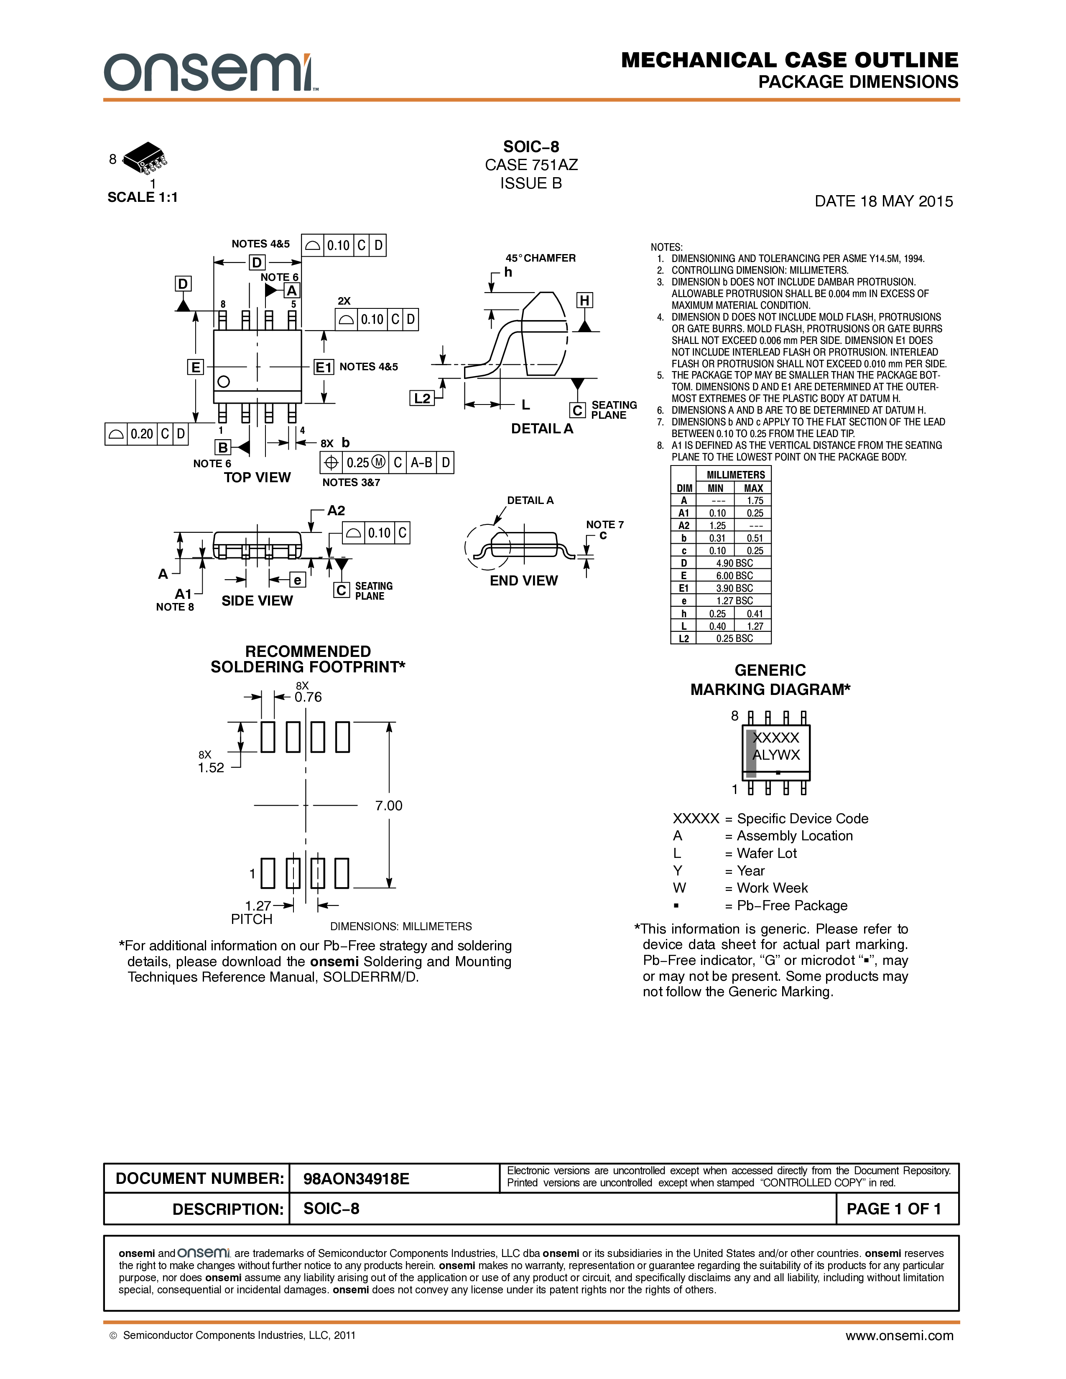
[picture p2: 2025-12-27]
doc/static/footprints/L7812CV.png

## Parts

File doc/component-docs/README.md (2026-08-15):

# component-docs — the evidence-to-docs generator

Projects the validated component evidence under `.claude/skills/` into the
generated human reference at `/docs/components/records/`. The evidence JSON is
the only source of truth; every generated page is a projection of it —
nothing is re-stated in prose, repaired, or rolled up into a verdict.

- **Architecture contract**: [`ARCHITECTURE.md`](./ARCHITECTURE.md) — the
  document the source comments cite (`§5` view-model versioning, `§7` safe
  generation). Read it before changing anything here.
- **Layout**: `core/` (provider-neutral engine) → `adapters/circuit/` (this
  repository's evidence provider) → `cli/` (generate / check / scan / watch /
  models) → `footprint-previews/` (SVG generator) → `ui/` (the MDX components)
  → `scripts/` (browser smoke) → `tests/`.
- **Commands** (run from `doc/`):
  - `pnpm generate:components` — validate (strict) → project → render → emit
  - `pnpm check:components` — dry-run drift check (CI's determinism gate)
  - `pnpm scan:components` — denied-value scan of the built `dist/`
  - `pnpm test:components` — the full test suite
  - `pnpm generate:models` / `pnpm check:models` — publish (or drift-check) the
    reviewed WRL package models into `public/assets/component-previews/models/`
  - `pnpm generate:footprint-previews` / `pnpm check:footprint-previews` — the
    same pair for the footprint SVGs
  - `pnpm check:built-component-references` — the built-`dist/` contract for the
    reference section (needs `pnpm build` first)
  - `pnpm test:model-viewer:browser` — headless-Chrome smoke over the built
    site: layout, WebGL, both enlarge dialogs, SPA teardown, no-JS fallback
- **Owned output**: `doc/src/content/docs/components/records/`,
  `preflight.json`, and the two published preview asset directories under
  `doc/public/assets/component-previews/` — committed, deterministic, never
  hand-edited.

Ported from `zudo-led-lamp`'s component-docs engine; the port's deliberate
differences (re-rooted generated tree, no `packagePreviews` seam, independently
optional reference cards, `ownerSkill` denied, per-placement DNP) are
catalogued in `ARCHITECTURE.md`.

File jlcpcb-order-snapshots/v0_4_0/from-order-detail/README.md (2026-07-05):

# v0.4.0 — from-order-detail (placeholder)

This directory is empty on purpose. Unlike `v0_1_0`, `v0_2_0`, and `v0_3_0` (each of which has a
`from-order-detail/` containing JLCPCB's own confirmed BOM export, layout render, and/or
product-detail photo), no equivalent artifact for the v0.4.0 order could be found anywhere on
this machine as of 2026-07-05. See
`doc/src/content/docs/inbox/v4-asbuilt-audit.md` for the full investigation.

## What to do

1. Log into the JLCPCB account used for this project's orders
   (`https://jlcpcb.com/user/order/list` → Order History).
2. Look for an order placed on or after **2026-06-05** for this board (the pin-18 fix + faston
   swap + BOM harmonization were committed at that date/time in `7854736`/`2c29375`).
3. If found, from the order-detail page download:
   - The **confirmed BOM** export (shows JLCPCB's actual matched/substituted LCSC parts — this
     is the only way to rule out a silent substitution, e.g. for D4 USBLC6-2SC6).
   - Any **layout / placement-preview render** JLCPCB generated.
   - Any **product-detail photo** (post-assembly photo, if the order has shipped).
4. Save them into this directory using the same naming convention as `v0_3_0/from-order-detail/`
   (`bom.xls`, `layout.png`, `product-detail.png`).
5. If **no** order exists for this date, v0.4.0 has not actually been manufactured yet — the
   design fix only exists in git plus the locally-generated package in
   `../used-for-order/` (recovered from this machine's gitignored `jlcpcb/` working directory).
   The next step would be to actually place the order using those files.

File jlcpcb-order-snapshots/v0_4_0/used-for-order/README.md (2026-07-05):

# v0.4.0 — used-for-order (recovered, not a fresh export)

`BOM-zudo-pd.csv`, `CPL-zudo-pd.csv`, and `GERBER-zudo-pd.zip` in this directory are **not**
newly generated — they were recovered on 2026-07-05 from this machine's gitignored `jlcpcb/`
working directory (`kicad-jlcpcb-tools` plugin output), where their file mtimes are
**2026-06-05 03:24**, about 1.5 hours before the design was committed as `7854736`
(`fix(usb-pd): v0.4.0 faston swap to C591344 + harmonize BOM comments`).

They reflect the fixed v0.4.0 design (pin-18 → R14 → VBUS_IN, faston C591344 swap) and are
believed to be the package that was prepared for the v0.4.0 order, but there is no local
evidence confirming they were ever actually uploaded/ordered at JLCPCB — see
`../from-order-detail/README.md` and
`doc/src/content/docs/inbox/v4-asbuilt-audit.md` for the full verification and what to check on
the JLCPCB side.

Known issue in this snapshot: the BOM's R13/R14 rows did not fully collapse per the
harmonization commit's intent (`R13` shows Comment `470`, `R14` shows `470ohm`, same LCSC
`C23179`) — a stale value cached in the plugin's local `project.db`, not a schematic problem.
Regenerate from KiCad before using this for a real order if that matters to you.

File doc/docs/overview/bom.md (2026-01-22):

---
sidebar_position: 4
---

# Bill of Materials (BOM)

Complete parts configuration using JLCPCB SMT service.

## Power Supply Specifications

- **+12V**: 1500mA max (L7812CD2T-TR)
- **-12V**: 1000mA max (CJ7912)
- **+5V**: 1500mA max (L7805ABD2T-TR)
- **Input**: USB-C PD 15V 3A
- **Efficiency**: Approximately 75-80%
- **Ripple**: \<1mVp-p (final output)

## Complete Parts Configuration by Stage

### Stage 1: USB-PD Voltage Acquisition (STUSB4500)

:::info v1.1 Upgrade
This stage was upgraded from CH224D to **STUSB4500** for significantly improved charger compatibility (~95%+ vs ~33%). See [CH224D](../components/ch224d) for the deprecated v1.0 design.
:::

#### Main ICs

| Symbol | Part Number | Manufacturer Part Number | Description | Package | Stock | Price | Application | Diagram |
| --- | --- | --- | --- | --- | --- | --- | --- | --- |
| **U1** | **[C2678061](https://jlcpcb.com/partdetail/C2678061)** | **[STUSB4500QTR](../components/stusb4500)** | USB-IF Certified PD Sink  | QFN-24  | **4,728** | **$2.50** | PD Negotiation (15V) | [D1](/docs/overview/circuit-diagrams#diagram1-usb-pd-power-supply-section) |
| **Q1** | **[C347476](https://jlcpcb.com/partdetail/C347476)** | **[AO3401A](../components/ao3401a)** | P-Channel MOSFET -30V -4A | SOT-23  | **1.1M**  | **$0.02** | Load Switch (High-side) | [D1](/docs/overview/circuit-diagrams#diagram1-usb-pd-power-supply-section) |
| **J1** | **[C456012](https://jlcpcb.com/partdetail/C456012)** | **[USB-TYPE-C-6P](../components/usb-c-connector)** | 6P Type-C Female | SMD | **Stock** | **$0.05** | USB-C Input | [D1](/docs/overview/circuit-diagrams#diagram1-usb-pd-power-supply-section) |

#### ESD Protection (Recommended)

| Symbol | Part Number | Manufacturer Part Number | Description | Package  | Stock | Price | Application | Diagram |
| --- | --- | --- | --- | --- | --- | --- | --- | --- |
| **D4** | **[C7519](https://jlcpcb.com/partdetail/C7519)** | **[USBLC6-2SC6](../components/usblc6-2sc6)** | CC + VBUS TVS Array 5V 3.5pF | SOT-23-6 | **354,000** | **$0.13** | CC1/CC2/VBUS Protection | [D1](/docs/overview/circuit-diagrams#diagram1-usb-pd-power-supply-section) |

#### Capacitors

| Symbol  | Part Number | Specification | Package | Stock | Price | Application | Diagram |
| --- | --- | --- | --- | --- | --- | --- | --- |
| **C1**  | **[C7432781](https://jlcpcb.com/partdetail/C7432781)** | 10µF 50V X5R ±10% | 1206 | **656,427** | **$0.024**  | VBUS Bulk Filter | [D1](/docs/overview/circuit-diagrams#diagram1-usb-pd-power-supply-section) |
| **C2**  | **[C49678](https://jlcpcb.com/partdetail/C49678)** | 100nF 50V X7R | 0805 | **23,309,869** | **$0.0021** | VDD HF Decoupling | [D1](/docs/overview/circuit-diagrams#diagram1-usb-pd-power-supply-section) |
| **C30** | **[C6119849](https://jlcpcb.com/partdetail/C6119849)** | 1µF 16V X5R ±10%  | 0603 | **1,225,237**  | **$0.0012** | VREG_2V7 Decoupling | [D1](/docs/overview/circuit-diagrams#diagram1-usb-pd-power-supply-section) |
| **C34** | **[C6119849](https://jlcpcb.com/partdetail/C6119849)** | 1µF 16V X5R ±10%  | 0603 | **1,225,237**  | **$0.0012** | VREG_1V2 Decoupling | [D1](/docs/overview/circuit-diagrams#diagram1-usb-pd-power-supply-section) |
| **C35** | **[C49678](https://jlcpcb.com/partdetail/C49678)** | 100nF 50V X7R | 0805 | **23,309,869** | **$0.0021** | Gate Soft-start | [D1](/docs/overview/circuit-diagrams#diagram1-usb-pd-power-supply-section) |

#### Resistors

| Symbol  | Part Number | Value | Description | Package | Price | Application | Diagram |
| --- | --- | ----- | --- | --- | --- | --- | --- |
| **R11** | **[C14675](https://jlcpcb.com/partdetail/C14675)** | 100kΩ | ±1% 100mW | 0603 | **$0.0005** | Gate Pull-up (default OFF) | [D1](/docs/overview/circuit-diagrams#diagram1-usb-pd-power-supply-section) |
| **R12** | **[C23168](https://jlcpcb.com/partdetail/C23168)** | 56kΩ  | ±1% 100mW | 0603 | **$0.0005** | Gate Voltage Divider | [D1](/docs/overview/circuit-diagrams#diagram1-usb-pd-power-supply-section) |
| **R13** | **[C23162](https://jlcpcb.com/partdetail/C23162)** | 470Ω  | ±1% 100mW | 0603 | **$0.0005** | VBUS Discharge | [D1](/docs/overview/circuit-diagrams#diagram1-usb-pd-power-supply-section) |

**Stage 1 Subtotal: ~$2.80**

**Key Features (STUSB4500 vs CH224D):**

| Feature | CH224D (v1.0) | STUSB4500 (v1.1) |
| --- | --- | --- |
| **USB-IF Certified** | No | **Yes** |
| **Charger Compat.**  | ~33% | **~95%+** |
| **Error Recovery** | None | **Built-in retry**  |
| **Power Sequencing** | None | **VBUS_EN_SNK pin** |
| **CC Protection** | 8V | **22V** |
| **Configuration** | Resistor | **NVM + I2C** |

**Critical Notes:**

- **Load switch (Q1)** controls power path - only enables after successful PD negotiation
- **VBUS_EN_SNK** goes HIGH when negotiation succeeds, turning ON Q1
- **Soft-start** via C35 (100nF) limits inrush current (τ = 56kΩ × 100nF = 5.6ms)
- **NVM programming** required to configure 15V PDO (one-time setup)

### Stage 2: DC-DC Converters (LM2596S-ADJ × 3 + ICL7660)

#### Main ICs

| Symbol | Part Number | Manufacturer Part Number | Description | Package  | Stock | Price | Application | Diagram |
| --- | --- | --- | --- | --- | --- | --- | --- | --- |
| **U2** | **[C347423](https://jlcpcb.com/partdetail/C347423)** | **[LM2596S-ADJ(UMW)](../components/lm2596s-adj)** | Adjustable 3A Buck | TO-263-5 | **12075** | **$0.266** | +15V→+13.5V | [D2](/docs/overview/circuit-diagrams#diagram2-usb-pd-15v--135v-buck-converter-lm2596s-adj-1)  |
| **U3** | **[C347423](https://jlcpcb.com/partdetail/C347423)** | **[LM2596S-ADJ(UMW)](../components/lm2596s-adj)** | Adjustable 3A Buck | TO-263-5 | **12075** | **$0.266** | +15V→+7.5V | [D3](/docs/overview/circuit-diagrams#diagram3-15v--75v-buck-converter-lm2596s-adj-2-u3) |
| **U4** | **[C347423](https://jlcpcb.com/partdetail/C347423)** | **[LM2596S-ADJ(UMW)](../components/lm2596s-adj)** | Adjustable 3A Buck | TO-263-5 | **12075** | **$0.266** | +15V→-13.5V Inverting Buck-Boost | [D4](/docs/overview/circuit-diagrams#diagram4-15v---135v-inverting-buck-boost-lm2596s-adj-u4) |

#### Inductors

| Symbol | Part Number | Manufacturer Part Number | Description | Package | Stock | Price | Application | Diagram |
| --- | --- | --- | --- | --- | --- | --- | --- | --- |
| **L1** | **[C19268674](https://jlcpcb.com/partdetail/C19268674)** | **CYA1265-100UH** | 100µH 4.5A  | SMD,13.8x12.8mm | **2763** | **$0.378** | U2 Energy Storage | [D2](/docs/overview/circuit-diagrams#diagram2-usb-pd-15v--135v-buck-converter-lm2596s-adj-1)  |
| **L2** | **[C19268674](https://jlcpcb.com/partdetail/C19268674)** | **CYA1265-100UH** | 100µH 4.5A  | SMD,13.8x12.8mm | **2763** | **$0.378** | U3 Energy Storage | [D3](/docs/overview/circuit-diagrams#diagram3-15v--75v-buck-converter-lm2596s-adj-2-u3) |
| **L3** | **[C19268674](https://jlcpcb.com/partdetail/C19268674)** | **CYA1265-100UH** | 100µH 4.5A  | SMD,13.8x12.8mm | **2763** | **$0.378** | U4 Energy Storage | [D4](/docs/overview/circuit-diagrams#diagram4-15v---135v-inverting-buck-boost-lm2596s-adj-u4) |

#### Diodes

| Symbol | Part Number | Manufacturer Part Number | Description | Package | Stock | Price | Application | Diagram |
| --- | --- | --- | --- | --- | --- | --- | --- | --- |
| **D1** | **[C8678](https://jlcpcb.com/partdetail/C8678)** | **SS34** | 3A 40V Schottky | SMA | **1,859,655** | **$0.012** | U2 Freewheeling | [D2](/docs/overview/circuit-diagrams#diagram2-usb-pd-15v--135v-buck-converter-lm2596s-adj-1)  |
| **D2** | **[C8678](https://jlcpcb.com/partdetail/C8678)** | **SS34** | 3A 40V Schottky | SMA | **1,859,655** | **$0.012** | U3 Freewheeling | [D3](/docs/overview/circuit-diagrams#diagram3-15v--75v-buck-converter-lm2596s-adj-2-u3) |
| **D3** | **[C8678](https://jlcpcb.com/partdetail/C8678)** | **SS34** | 3A 40V Schottky | SMA | **1,859,655** | **$0.012** | U4 Freewheeling | [D4](/docs/overview/circuit-diagrams#diagram4-15v---135v-inverting-buck-boost-lm2596s-adj-u4) |

#### Feedback Resistors (Basic Parts)

| Symbol | Part Number | Value | Description | Package | Price | Application | Diagram |
| --- | --- | --- | --- | --- | --- | --- | --- |
| **R1** | **[C25804](https://jlcpcb.com/partdetail/C25804)** | **10kΩ**  | ±1% 100mW | 0603 | **$0.0005** | U2 FB Upper | [D2](/docs/overview/circuit-diagrams#diagram2-usb-pd-15v--135v-buck-converter-lm2596s-adj-1)  |
| **R2** | **[C21190](https://jlcpcb.com/partdetail/C21190)** | **1kΩ** | ±1% 100mW | 0603 | **$0.0005** | U2 FB Lower | [D2](/docs/overview/circuit-diagrams#diagram2-usb-pd-15v--135v-buck-converter-lm2596s-adj-1)  |
| **R3** | **[C23186](https://jlcpcb.com/partdetail/C23186)** | **5.1kΩ** | ±1% 100mW | 0603 | **$0.0005** | U3 FB Upper | [D3](/docs/overview/circuit-diagrams#diagram3-15v--75v-buck-converter-lm2596s-adj-2-u3) |
| **R4** | **[C21190](https://jlcpcb.com/partdetail/C21190)** | **1kΩ** | ±1% 100mW | 0603 | **$0.0005** | U3 FB Lower | [D3](/docs/overview/circuit-diagrams#diagram3-15v--75v-buck-converter-lm2596s-adj-2-u3) |
| **R5** | **[C25804](https://jlcpcb.com/partdetail/C25804)** | **10kΩ**  | ±1% 100mW | 0603 | **$0.0005** | U4 FB Upper | [D4](/docs/overview/circuit-diagrams#diagram4-15v---135v-inverting-buck-boost-lm2596s-adj-u4) |
| **R6** | **[C21190](https://jlcpcb.com/partdetail/C21190)** | **1kΩ** | ±1% 100mW | 0603 | **$0.0005** | U4 FB Lower | [D4](/docs/overview/circuit-diagrams#diagram4-15v---135v-inverting-buck-boost-lm2596s-adj-u4) |

#### Electrolytic Capacitors

| Symbol  | Part Number | Specification | Package | Stock | Price | Application | Diagram |
| --- | --- | --- | --- | --- | --- | --- | --- |
| **C3**  | **[C2983319](https://jlcpcb.com/partdetail/C2983319)** | **470µF 25V** | D8xL10.5mm  | **46,748** | **$0.04**  | U2 Output Filter | [D2](/docs/overview/circuit-diagrams#diagram2-usb-pd-15v--135v-buck-converter-lm2596s-adj-1)  |
| **C4**  | **[C46550400](https://jlcpcb.com/partdetail/C46550400)** | **470µF 16V ±20%** | D6.3xL7.7mm | **23,331** | **$0.02**  | U3 Output Filter | [D3](/docs/overview/circuit-diagrams#diagram3-15v--75v-buck-converter-lm2596s-adj-2-u3) |
| **C5**  | **[C22383804](https://jlcpcb.com/partdetail/C22383804)** | **100µF 25V ±20%** | D6.3xL7.7mm | **43,359** | **$0.019** | U2 Input Bulk | [D2](/docs/overview/circuit-diagrams#diagram2-usb-pd-15v--135v-buck-converter-lm2596s-adj-1)  |
| **C7**  | **[C22383804](https://jlcpcb.com/partdetail/C22383804)** | **100µF 25V ±20%** | D6.3xL7.7mm | **43,359** | **$0.019** | U3 Input Bulk | [D3](/docs/overview/circuit-diagrams#diagram3-15v--75v-buck-converter-lm2596s-adj-2-u3) |
| **C9**  | **[C22383806](https://jlcpcb.com/partdetail/C22383806)** | **100µF 50V** | D6.3xL7.7mm | **8,337**  | **TBD** | U4 Input Bulk | [D4](/docs/overview/circuit-diagrams#diagram4-15v---135v-inverting-buck-boost-lm2596s-adj-u4) |
| **C11** | **[C2983319](https://jlcpcb.com/partdetail/C2983319)** | **470µF 25V** | D8xL10.5mm  | **46,748** | **$0.04**  | U4 Output Filter | [D4](/docs/overview/circuit-diagrams#diagram4-15v---135v-inverting-buck-boost-lm2596s-adj-u4) |

#### Ceramic Capacitors (DC-DC Stage)

| Symbol  | Part Number | Specification | Package | Stock | Price | Application | Diagram |
| --- | --- | --- | --- | --- | --- | --- | --- |
| **C6**  | **[C49678](https://jlcpcb.com/partdetail/C49678)** | **100nF 50V X7R** | 0805 | **23,309,869** | **$0.0021** | U2 Input Decoupling | [D2](/docs/overview/circuit-diagrams#diagram2-usb-pd-15v--135v-buck-converter-lm2596s-adj-1)  |
| **C8**  | **[C49678](https://jlcpcb.com/partdetail/C49678)** | **100nF 50V X7R** | 0805 | **23,309,869** | **$0.0021** | U3 Input Decoupling | [D3](/docs/overview/circuit-diagrams#diagram3-15v--75v-buck-converter-lm2596s-adj-2-u3) |
| **C10** | **[C49678](https://jlcpcb.com/partdetail/C49678)** | **100nF 50V X7R** | 0805 | **23,309,869** | **$0.0021** | U4 Input Decoupling | [D4](/docs/overview/circuit-diagrams#diagram4-15v---135v-inverting-buck-boost-lm2596s-adj-u4) |
| **C31** | **[C1710](https://jlcpcb.com/partdetail/C1710)** | **22nF 50V X7R**  | 0805 | **Rich Stock** | **$0.002**  | U2 Feedback Compensation | [D2](/docs/overview/circuit-diagrams#diagram2-usb-pd-15v--135v-buck-converter-lm2596s-adj-1)  |
| **C32** | **[C1710](https://jlcpcb.com/partdetail/C1710)** | **22nF 50V X7R**  | 0805 | **Rich Stock** | **$0.002**  | U3 Feedback Compensation | [D3](/docs/overview/circuit-diagrams#diagram3-15v--75v-buck-converter-lm2596s-adj-2-u3) |
| **C33** | **[C1710](https://jlcpcb.com/partdetail/C1710)** | **22nF 50V X7R**  | 0805 | **Rich Stock** | **$0.002**  | U4 Feedback Compensation | [D4](/docs/overview/circuit-diagrams#diagram4-15v---135v-inverting-buck-boost-lm2596s-adj-u4) |

**Note on C31/C32/C33:** These capacitors are not available in EasyEDA's symbol database. Use KiCad's built-in `Device:C` symbol paired with the `C0805.kicad_mod` footprint. This is standard practice for passive components in JLCPCB PCBA projects.

**Stage 2 Subtotal: TBD** (pending inductor/capacitor selection)

### Stage 3: Linear Regulators (LM7812/7805/7912)

#### Regulator ICs

| Symbol | Part Number | Manufacturer Part Number | Description | Package | Stock | Price | Application | Diagram |
| --- | --- | --- | --- | --- | --- | --- | --- | --- |
| **U6** | **[C13456](https://jlcpcb.com/partdetail/C13456)** | **[L7812CD2T-TR](../components/l7812cv)** | +12V 1.5A | TO-263-2  | **40,204**  | **$0.11** | +12V Output | [D5](/docs/overview/circuit-diagrams#diagram5-135v--12v-linear-regulator-l7812-u6) |
| **U7** | **[C86206](https://jlcpcb.com/partdetail/C86206)** | **[L7805ABD2T-TR](../components/l7805abd2t)** | +5V 1.5A | TO-263-2  | **272,379** | **$0.11** | +5V Output  | [D6](/docs/overview/circuit-diagrams#diagram6-75v--5v-linear-regulator-l7805-u7) |
| **U8** | **[C94173](https://jlcpcb.com/partdetail/C94173)** | **[CJ7912](../components/cj7912)** | -12V 1.5A | TO-252-2L | **3,386** | **$0.11** | -12V Output | [D7](/docs/overview/circuit-diagrams#diagram7--135v---12v-linear-regulator-cj7912-u8) |

#### Input Capacitors (470nF) - Basic Parts

| Symbol  | Part Number | Specification | Package | Stock | Price | Application | Diagram |
| --- | --- | --- | --- | --- | --- | --- | --- |
| **C15** | **[C1623](https://jlcpcb.com/partdetail/C1623)** | **470nF 25V X7R** | 0603 | **1,100,473** | **$0.0036** | U7 Input Filter | [D6](/docs/overview/circuit-diagrams#diagram6-75v--5v-linear-regulator-l7805-u7) |
| **C16** | **[C1623](https://jlcpcb.com/partdetail/C1623)** | **470nF 25V X7R** | 0603 | **1,100,473** | **$0.0036** | U8 Input Filter | [D7](/docs/overview/circuit-diagrams#diagram7--135v---12v-linear-regulator-cj7912-u8) |

#### Output Capacitors (0.1µF) - Basic Parts

| Symbol  | Part Number | Specification | Package | Stock | Price | Application | Diagram |
| --- | --- | --- | --- | --- | --- | --- | --- |
| **C17** | **[C49678](https://jlcpcb.com/partdetail/C49678)** | **100nF 50V X7R** | 0805 | **23,309,869** | **$0.0021** | U6 Output Filter | [D5](/docs/overview/circuit-diagrams#diagram5-135v--12v-linear-regulator-l7812-u6) |
| **C18** | **[C49678](https://jlcpcb.com/partdetail/C49678)** | **100nF 50V X7R** | 0805 | **23,309,869** | **$0.0021** | U7 Output Filter | [D6](/docs/overview/circuit-diagrams#diagram6-75v--5v-linear-regulator-l7805-u7) |
| **C19** | **[C49678](https://jlcpcb.com/partdetail/C49678)** | **100nF 50V X7R** | 0805 | **23,309,869** | **$0.0021** | U8 Output Filter | [D7](/docs/overview/circuit-diagrams#diagram7--135v---12v-linear-regulator-cj7912-u8) |

#### Large Electrolytic Capacitors (Linear Regulator Stage)

| Symbol  | Part Number | Specification | Package | Stock | Price | Application | Diagram |
| --- | --- | --- | --- | --- | --- | --- | --- |
| **C14** | **[C2992611](https://jlcpcb.com/partdetail/C2992611)** | **470µF 35V** | D10xL10.5mm | **13,862** | **$0.04** | U6 Input | [D5](/docs/overview/circuit-diagrams#diagram5-135v--12v-linear-regulator-l7812-u6) |
| **C20** | **[C2992611](https://jlcpcb.com/partdetail/C2992611)** | **470µF 35V** | D10xL10.5mm | **13,862** | **$0.04** | U6 Input | [D5](/docs/overview/circuit-diagrams#diagram5-135v--12v-linear-regulator-l7812-u6) |
| **C21** | **[C2992611](https://jlcpcb.com/partdetail/C2992611)** | **470µF 35V** | D10xL10.5mm | **13,862** | **$0.04** | U6 Output | [D5](/docs/overview/circuit-diagrams#diagram5-135v--12v-linear-regulator-l7812-u6) |
| **C22** | **[C46550400](https://jlcpcb.com/partdetail/C46550400)** | **470µF 16V** | D6.3xL7.7mm | **23,331** | **$0.02** | U7 Input | [D6](/docs/overview/circuit-diagrams#diagram6-75v--5v-linear-regulator-l7805-u7) |
| **C23** | **[C46550400](https://jlcpcb.com/partdetail/C46550400)** | **470µF 16V** | D6.3xL7.7mm | **23,331** | **$0.02** | U7 Output | [D6](/docs/overview/circuit-diagrams#diagram6-75v--5v-linear-regulator-l7805-u7) |
| **C24** | **[C2992611](https://jlcpcb.com/partdetail/C2992611)** | **470µF 35V** | D10xL10.5mm | **13,862** | **$0.04** | U8 Input | [D7](/docs/overview/circuit-diagrams#diagram7--135v---12v-linear-regulator-cj7912-u8) |
| **C25** | **[C2992611](https://jlcpcb.com/partdetail/C2992611)** | **470µF 35V** | D10xL10.5mm | **13,862** | **$0.04** | U8 Output | [D7](/docs/overview/circuit-diagrams#diagram7--135v---12v-linear-regulator-cj7912-u8) |

**Stage 3 Subtotal: $0.37** (Using high-stock regulators)

### Stage 4: Protection Circuit (PTC Auto-Reset with Multi-Layer Protection)

#### PTC Resettable Fuses (Auto-Recovery)

| Symbol | Part Number | Manufacturer Part Number | Specification | Package | Stock | Price | Application | Diagram |
| --- | --- | --- | --- | --- | --- | --- | --- | --- |
| **PTC1** | **[C20808](https://jlcpcb.com/partdetail/C20808)** | **[SMD1210P200TF](../components/ptc-12v)** | **2.0A hold / 4A trip** | SMD1210 | **1,744**  | **$0.22** | +12V Rail Protection | [D5](/docs/overview/circuit-diagrams#diagram5-135v--12v-linear-regulator-l7812-u6) |
| **PTC2** | **[C70119](https://jlcpcb.com/partdetail/C70119)** | **[mSMD110-33V](../components/ptc-5v)** | **1.1A hold / 2.2A trip** | 1812 | **44,459** | **$0.10** | +5V Rail Protection  | [D6](/docs/overview/circuit-diagrams#diagram6-75v--5v-linear-regulator-l7805-u7) |
| **PTC3** | **[C883133](https://jlcpcb.com/partdetail/C883133)** | **[BSMD1206-150-16V](../components/ptc-12v-neg)** | **1.5A hold / 3.0A trip** | 1206 | **60,591** | **$0.14** | -12V Rail Protection | [D7](/docs/overview/circuit-diagrams#diagram7--135v---12v-linear-regulator-cj7912-u8) |

**Protection Philosophy:**

- **PTC-only design** - No backup fuses needed (traditional fuses unavailable on JLCPCB)
- **Linear regulators provide inherent protection**: Current limiting (~1-2A) + thermal shutdown
- **Four-layer protection**: USB-PD → DC-DC → Linear Regulator → PTC
- **Auto-reset convenience**: No manual fuse replacement required

#### TVS Diodes

| Symbol | Part Number | Manufacturer Part Number | Description | Package | Estimated Price | Application | Diagram |
| --- | --- | --- | --- | --- | --- | --- | --- |
| **TVS1** | **[C571368](https://jlcpcb.com/partdetail/C571368)** | **[SMAJ15A](../components/smaj15a)** | 15V TVS Unidirectional | SMA | **$0.15** | +12V Protection | [D5](/docs/overview/circuit-diagrams#diagram5-135v--12v-linear-regulator-l7812-u6) |
| **TVS2** | **[C502527](https://jlcpcb.com/partdetail/C502527)** | **[SD05](../components/sd05)** | 5V TVS Unidirectional  | SOD-323 | **$0.02** | +5V Protection  | [D6](/docs/overview/circuit-diagrams#diagram6-75v--5v-linear-regulator-l7805-u7) |
| **TVS3** | **[C571368](https://jlcpcb.com/partdetail/C571368)** | **[SMAJ15A](../components/smaj15a)** | 15V TVS Unidirectional | SMA | **$0.15** | -12V Protection | [D7](/docs/overview/circuit-diagrams#diagram7--135v---12v-linear-regulator-cj7912-u8) |

#### Status Indicator LEDs (Using Basic Parts)

| Symbol | Part Number | Specification | Package | Price | Application | Diagram |
| --- | --- | --- | --- | --- | --- | --- |
| **LED2** | **[C19171392](https://jlcpcb.com/partdetail/C19171392)** | **Green LED** | 0603 | **$0.01** | +12V Status Indicator | [D5](/docs/overview/circuit-diagrams#diagram5-135v--12v-linear-regulator-l7812-u6) |
| **LED3** | **[C5382145](https://jlcpcb.com/partdetail/C5382145)** | **Blue LED**  | 0603 | **$0.01** | +5V Status Indicator  | [D6](/docs/overview/circuit-diagrams#diagram6-75v--5v-linear-regulator-l7805-u7) |
| **LED4** | **[C2286](https://jlcpcb.com/partdetail/C2286)** | **Red LED** | 0603 | **$0.01** | -12V Status Indicator | [D7](/docs/overview/circuit-diagrams#diagram7--135v---12v-linear-regulator-cj7912-u8) |
| **R7** | **[C25623](https://jlcpcb.com/partdetail/C25623)** | **1kΩ 125mW** | 0805 | **$0.0010** | LED2 Current Limit | [D5](/docs/overview/circuit-diagrams#diagram5-135v--12v-linear-regulator-l7812-u6) |
| **R8** | **[C25623](https://jlcpcb.com/partdetail/C25623)** | **1kΩ 125mW** | 0805 | **$0.0010** | LED3 Current Limit | [D6](/docs/overview/circuit-diagrams#diagram6-75v--5v-linear-regulator-l7805-u7) |
| **R9** | **[C25623](https://jlcpcb.com/partdetail/C25623)** | **1kΩ 125mW** | 0805 | **$0.0010** | LED4 Current Limit | [D7](/docs/overview/circuit-diagrams#diagram7--135v---12v-linear-regulator-cj7912-u8) |

**Stage 4 Subtotal: $0.77** (PTC-only protection, no fuses needed)

### Stage 5: Output Connectors

#### Eurorack Power Connector (16-pin)

| Symbol | Part Number | Manufacturer Part Number | Description | Package | Stock | Price | Application | Diagram |
| --- | --- | --- | --- | --- | --- | --- | --- | --- |
| **J2** | **[C5383092](https://jlcpcb.com/partdetail/C5383092)** | **2541WR-2x08P** | 2x8P Pin Header 2.54mm | Through-hole | **6,813** | **$0.08** | Eurorack Power Output | - |

**Connector Type:** Standard 2x8 pin header (male, through-hole, 2.54mm pitch)

**Note:** This is a standard pin header. For box/shrouded connectors (commonly used in Eurorack), users should source the mating female box header connector separately from:

- Tayda Electronics
- Mouser / Digikey
- Other electronics distributors

**Eurorack 16-Pin Pinout (Flipped for bottom-facing PCB):**

```
  GATE  [ 1]  [ 2]  GATE
  CV    [ 3]  [ 4]  CV
  +5V   [ 5]  [ 6]  +5V
  +12V  [ 7]  [ 8]  +12V
  n/c   [ 9]  [10]  n/c
  GND   [11]  [12]  GND
  n/c   [13]  [14]  n/c
  -12V  [15]  [16]  -12V   ← Red stripe side
```

**Design Note:** The pinout is vertically flipped from the standard Eurorack orientation because the PCB is mounted facing downward. When viewed from the module side (looking up at the PCB), the red stripe (-12V) is at the bottom as expected.

**Note:** This power supply provides +12V, -12V, +5V, and GND. The CV (pins 3-4) and GATE (pins 1-2) pins are active but typically unused for power-only applications.

#### Individual Power Terminals

| Symbol | Part Number | Manufacturer Part Number | Description | Package | Stock | Price | Application |
| --- | --- | --- | --- | --- | --- | --- | --- |
| **J6-J9** | **[C305825](https://jlcpcb.com/partdetail/C305825)** | **[1217754-1](../components/faston-terminal)** (×4) | FASTON 250 PCB Tab 6.35mm | Through-hole | **4,044** | **$0.03 × 4** | Individual Power Output |

**Individual Terminal Configuration:**

| Terminal | Signal | Max Current |
| --- | --- | --- |
| **J6** | -12V | 7A (rated)  |
| **J7** | +12V | 7A (rated)  |
| **J8** | +5V | 7A (rated)  |
| **J9** | GND | 7A (rated)  |

**Purpose:** Individual power output terminals for direct wire connection or busboard connection. FASTON 250 series terminals support thick gauge wire for low-resistance, low-noise power delivery.

**Note:** Requires matching FASTON receptacles. Combined GND return current is ~2.5A max (well within 7A rating).

**Stage 5 Subtotal: $0.20** (Header: $0.08 + FASTON × 4: $0.12)

## Performance Specifications

### Power Supply Performance

| Item | Specification |
| --- | --- |
| **Efficiency** | 75-80% (Overall) |
| **Ripple Noise** | \<1mVp-p (Final Output) |
| **Regulation** | ±1% (Line & Load Variation) |
| **Response Speed** | Excellent (Linear Stage) |
| **Safety Margin**  | 150%+ on All Circuits |

### Output Specifications

| Voltage  | Current | Accuracy | Ripple |
| --- | --- | --- | --- |
| **+12V** | 1.5A | ±0.5% | \<1mVp-p |
| **-12V** | 1.0A | ±0.5% | \<1mVp-p |
| **+5V**  | 1.5A | ±0.5% | \<1mVp-p |

## Protection Circuit Operation

### Normal Operation (Current < Hold Rating)

- PTC: Low resistance (0.03-0.05Ω), minimal voltage drop
- Linear regulator: Normal operation
- LED: Brightly lit ✅

### Overload Condition (Current > Hold Rating)

1. PTC heats up and increases resistance
2. LED dims/turns off (clear visual feedback)
3. Within 1-5 seconds: PTC trips, current drops to ~10mA
4. **User action**: Reduce modules
5. **Auto-recovery**: Wait 30-60 seconds for PTC to cool
6. PTC resets automatically, power restored 🔄

### Short Circuit Condition (Output Shorted to GND)

**Multi-layer protection sequence:**

1. **Immediate**: Linear regulator current limiting kicks in (~1-2A max)
2. **0.5-5s**: PTC trips due to limited current flow
3. **1-5s**: If sustained, regulator thermal shutdown (150°C)
4. **LED**: Turns off (indicates fault)
5. **Recovery**: Both PTC and regulator auto-reset after cooling
6. **No damage**: Protected by four independent layers ✅

**Key insight:** Linear regulators prevent catastrophic shorts by limiting current before PTC trips, making PTC-only protection adequate.

## Design Features

### 1. Fully JLCPCB Sourceable with High Stock

- **Extensive Basic Parts Usage**: No additional costs
- **Abundant Stock**: Regulator ICs 150k~270k pieces in stock
- **Stable Sourcing**: High stock secured for all major components
- **USB-PD IC**: STUSB4500 (USB-IF certified) - 15V support, excellent charger compatibility

### 2. High-Performance Design

- **2-Stage Filtering**: DC-DC + Linear for low noise
- **Ample Margin**: 150%+ safety margin on all circuits
- **Modular Synth Optimized**: Low noise, high stability

### 3. Advanced Multi-Layer Protection

- **Four independent protection layers**: USB-PD → DC-DC → Linear Regulator → PTC
- **PTC Auto-Recovery**: Auto-resets in 30-60 seconds for all fault types
- **Linear regulator protection**: Built-in current limiting + thermal shutdown
- **Visual Feedback**: LED status indicates power/fault conditions
- **No Manual Intervention**: All protections auto-reset (no fuse replacement)
- **Better than commercial**: Exceeds Doepfer (4 layers vs 1), simpler than Intellijel

### 4. Implementation

- **100% SMD Components**: Fully compatible with automated PCBA assembly
- **Surface-Mount Design**: All regulators use SMD packages (TO-263-2, TO-252-2L)
- **Separated Design**: Physical separation of DC-DC and linear stages

## Component Heights

For detailed component height information and mechanical design considerations, see **[Mechanical Design](/docs/overview/mechanical-design)**.

**Quick reference** (tallest components):

- 470µF 25V electrolytic caps: **10.2mm** (tallest)
- FASTON terminals: **8.89mm**
- Total board height: **~12mm** including PCB

## Total Cost Summary

| Stage | Description | Subtotal  |
| --- | --- | --- |
| **Stage 1** | USB-PD Voltage Acquisition  | **$0.45** |
| **Stage 2** | DC-DC Converters | **$2.09** |
| **Stage 3** | Linear Regulators | **$0.37** |
| **Stage 4** | Protection Circuit | **$0.77** |
| **Stage 5** | Output Connectors | **$0.20** |
| | **Total (Components Only)** | **$3.88** |

**Cost Savings:**

- **Previous design** (PTC + Fuse): ~$4.76
- **Current design** (PTC-only + Connectors): **$3.88**
- **Savings**: **$0.88** (18% reduction)

**Notes:**

- Prices are estimates based on JLCPCB part catalog
- Does not include PCB fabrication or assembly fees
- All parts available on JLCPCB with good stock levels
- PTC-only design reduces cost while improving user experience

## JLCPCB Assembly Cost Structure

The component prices above are only part of the total PCBA cost. JLCPCB charges additional fees:

### Fee Types

| Fee | Description | Typical Cost  |
| --- | --- | --- |
| **PCB Fabrication** | Board manufacturing | ¥500-1,000 |
| **Setup Fee** | One-time assembly setup  | ~¥1,250 |
| **Stencil** | Solder paste stencil | ~¥235 |
| **SMT Assembly** | Per-placement fee | ~¥145 |
| **Extended Parts Fee** | Per unique Extended part | **¥470 each** |
| **Hand-soldering** | THT components | ~¥550 |

### Basic vs Extended Parts

JLCPCB classifies components into two categories:

- **Basic Parts**: Common resistors, MLCCs, some diodes - **No extra fee**
- **Extended Parts**: Specialty ICs, electrolytic caps, LEDs, inductors, connectors - **¥470 per unique part number**

This project uses ~20 Extended parts, adding ~¥9,400 to the assembly cost.

### Cost Per Board (Reference: January 2025)

| Quantity  | Total Cost | Per Board  |
| --- | --- | --- |
| 1 board | ~¥16,500 | ¥16,500 |
| 5 boards  | ~¥21,000 | ¥4,200 |
| 10 boards | ~¥26,000 | **¥2,600** |

**Key insight**: Extended fees are **one-time setup costs**, not per-board. Ordering more boards significantly reduces the per-unit cost.

### Cost Optimization Tips

1. **Order in batches of 5-10** to amortize setup fees
2. **Hand-solder large components** (electrolytic caps, connectors) to reduce Extended fees
3. **Use Basic parts** where possible (resistors, MLCCs are usually Basic)
4. **Consolidate part numbers** - fewer unique Extended parts = lower fees

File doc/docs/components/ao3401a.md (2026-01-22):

---
sidebar_position: 3
---

# AO3401A - P-Channel MOSFET (Load Switch)

P-Channel MOSFET for USB-PD power path control, used as load switch with STUSB4500.

- [View on JLCPCB: C347476](https://jlcpcb.com/partdetail/C347476)

## Overview

The AO3401A is a P-Channel enhancement mode MOSFET used as a high-side load switch in the USB-PD power path. It is controlled by the STUSB4500's VBUS_EN_SNK pin to enable power to downstream circuits only after successful PD negotiation.

## Key Specifications

| Parameter | Value | Notes |
| --- | --- | --- |
| **JLCPCB Part Number** | C347476 | |
| **Manufacturer Part Number** | AO3401A | Alpha & Omega Semi |
| **Package** | SOT-23 | 3-pin surface-mount |
| **Stock Availability** | 1,094,498 | Excellent availability |
| **Unit Price** | ~$0.02 | Very low cost |
| **Drain-Source Voltage** | -30V | Suitable for 20V PD |
| **Continuous Drain Current** | -4A | Sufficient for 3A load |
| **Rds(on) @ Vgs=-4.5V** | 44mΩ | Low power loss |
| **Gate Threshold Voltage** | -0.5V to -1.2V | Logic-level compatible |
| **Power Dissipation** | 1.4W | SOT-23 package limit |

## Pin Configuration

```
    AO3401A (SOT-23)
        Top View

    ┌───────────────┐
    │   ┌─────┐     │
    │   │     │     │
  G │1  │     │  3│ S
    │   │     │     │
    │   └─────┘     │
    │       2       │
    └───────┬───────┘
            D

Pin 1: Gate (G)
Pin 2: Drain (D)
Pin 3: Source (S)
```

## Application in STUSB4500 Circuit

```
Load Switch Circuit:

VBUS_IN (15V from USB-C)
    │
    ├───────────────────────────────┐
    │                               │
   R1 (100kΩ)                     Source (pin 3)
    │                               │
    ├─────────── Gate (pin 1) ─── AO3401A
    │                               │
   R2 (56kΩ)                      Drain (pin 2)
    │                               │
VBUS_EN_SNK ──┘                     │
(from STUSB4500)                    │
    │                               ▼
   C5 (100nF)                   VBUS_OUT
    │                           (to DC-DC)
   GND

Operation:
- VBUS_EN_SNK = LOW: Gate pulled HIGH by R1 → MOSFET OFF
- VBUS_EN_SNK = HIGH: Gate pulled LOW through R2 → MOSFET ON
- C5 provides soft-start (slew rate control)
```

### Component Values

| Reference | Value | Purpose |
| --- | ----- | --- |
| R1 | 100kΩ | Gate pull-up (default OFF) |
| R2 | 56kΩ  | Gate voltage divider |
| C5 | 100nF | Soft-start |

### Soft-Start Calculation

Time constant: τ = R2 × C5 = 56kΩ × 100nF = 5.6ms

This limits the dV/dt during turn-on, reducing inrush current.

## Power Dissipation

At maximum load (3A, 15V):

- Conduction loss: P = I² × Rds(on) = 3² × 0.044 = 0.4W
- Well within SOT-23 thermal limit (1.4W)

## Why P-Channel for High-Side Switch?

| Switch Type | Position  | Gate Drive | Complexity |
| --- | --- | --- | --- |
| P-Channel | High-side | Simple (ref to VBUS) | Low |
| N-Channel | High-side | Needs charge pump | High |
| N-Channel | Low-side  | Simple | Breaks ground path |

P-Channel is ideal for high-side switching with simple gate drive.

## References

- [AO3401A Datasheet](https://www.aosmd.com/res/data_sheets/AO3401A.pdf)
- [JLCPCB Part Page](https://jlcpcb.com/partdetail/C347476)

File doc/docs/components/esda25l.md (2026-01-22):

---
sidebar_position: 4
---

# ESDA25L - TVS Diode (Legacy)

:::caution Not Used in Current Design
ESDA25L has been **replaced by [USBLC6-2SC6](./usblc6-2sc6.md)** in v1.1 design.

**Reason**: ESDA25L's clamping voltage (~44V) is too high for CC line protection. USBLC6-2SC6 clamps at ~17V and includes VBUS protection.
:::

TVS diode for high-voltage ESD and overvoltage protection.

- [View on JLCPCB: C343997](https://jlcpcb.com/partdetail/C343997)

## Overview

The ESDA25L is a TVS (Transient Voltage Suppressor) diode designed for ESD protection on USB Type-C CC (Configuration Channel) lines. It protects the STUSB4500 CC pins from electrostatic discharge and voltage transients.

## Key Specifications

| Parameter | Value | Notes |
| --- | --- | --- |
| **JLCPCB Part Number** | C343997 | |
| **Manufacturer Part Number** | ESDA25L | STMicroelectronics |
| **Package** | SOT-23 | 3-pin surface-mount |
| **Stock Availability** | 4,584 | Good availability |
| **Unit Price** | ~$0.15 | |
| **Working Voltage** | 25V | CC lines up to 22V |
| **Breakdown Voltage** | 27.6V min  | |
| **Clamping Voltage** | 40V @ 1A | |
| **Peak Pulse Current** | 3A | 8/20µs waveform |
| **Capacitance** | 3pF typ | Low impact on CC signals |
| **ESD Rating** | 15kV (HBM) | IEC 61000-4-2 |

## Pin Configuration

```
    ESDA25L (SOT-23)
       Top View

    ┌───────────────┐
    │   ┌─────┐     │
    │   │     │     │
 K1 │1  │     │  3│ K2
    │   │     │     │
    │   └─────┘     │
    │       2       │
    └───────┬───────┘
            A (Common Anode)

Pin 1: Cathode 1 (K1) - CC1
Pin 2: Anode (A) - GND
Pin 3: Cathode 2 (K2) - CC2

Internal Structure:
CC1 ───┤◄├───┬───┤►├─── CC2
              │
             GND
```

## Application in STUSB4500 Circuit

```
USB-C Connector              STUSB4500
┌──────────────┐            ┌──────────────┐
│              │            │              │
│  CC1  ───────┼────────┬───┤ CC1 (pin 2)  │
│              │        │   │              │
│  CC2  ───────┼────┬───┼───┤ CC2 (pin 3)  │
│              │    │   │   │              │
└──────────────┘    │   │   └──────────────┘
                    │   │
                    │   │   ESDA25L
                    │   │   ┌────────┐
                    │   └───┤ K1 (1) │
                    │       │        │
                    │       │ A  (2) ├─── GND
                    │       │        │
                    └───────┤ K2 (3) │
                            └────────┘
```

## Why CC Protection is Important

| Threat | Source | Protection |
| --- | --- | --- |
| ESD | Cable insertion/removal | 15kV HBM rating |
| Short to VBUS | Faulty cable/adapter | 25V working voltage |
| Transients | Hot-plug events | Fast clamping |

The STUSB4500 has internal CC protection up to 22V, but external TVS provides additional margin and faster response.

## Design Considerations

### Placement

- Place ESDA25L as close as possible to USB-C connector
- Short traces to GND for effective clamping
- Before any series resistors on CC lines

### Capacitance Impact

- 3pF typical capacitance is acceptable for CC communication
- USB PD CC signaling tolerates up to 200pF

## Alternative Parts

| Part | Package  | Voltage | Capacitance | Notes |
| --- | --- | --- | --- | --- |
| ESDA25L | SOT-23 | 25V | 3pF | Recommended |
| ESDA25W | SOT-353  | 25V | 1.5pF | Lower capacitance |
| ESDA25SC6 | SOT-23-6 | 25V | 1.5pF | 4-channel version |

## References

- [ESDA25L Datasheet (ST)](https://www.st.com/resource/en/datasheet/esda25.pdf)
- [JLCPCB Part Page](https://jlcpcb.com/partdetail/C343997)
- [USB Type-C ESD Protection App Note](https://www.st.com/resource/en/application_note/an4641-design-guidelines-for-using-st-esd-protection-device-for-usb-typec-interface-stmicroelectronics.pdf)

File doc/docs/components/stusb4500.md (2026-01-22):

---
sidebar_position: 2
---

# STUSB4500 - USB Power Delivery Controller

USB-IF certified USB Power Delivery sink controller for reliable 15V/3A power negotiation from USB-C PD chargers.

- [View on JLCPCB: C2678061](https://jlcpcb.com/partdetail/C2678061)
- [Download Datasheet (PDF)](https://www.st.com/resource/en/datasheet/stusb4500.pdf)

:::tip Why STUSB4500 over CH224D?
**STUSB4500 is USB-IF certified** with significantly better charger compatibility:

| Feature | CH224D | STUSB4500 |
| --- | --- | --- |
| USB-IF Certified | No | **Yes** |
| Charger Compat.  | ~33% | **~95%+** |
| Error Recovery | None | **Built-in** |
| Power Sequencing | None | **VBUS_EN_SNK** |
| Retry on Failure | No | **Yes** |
| CC Protection | 8V | **22V** |
| Configuration | Resistor | **NVM + I2C** |

CH224D failed with most modern GaN chargers. STUSB4500 is the recommended replacement for v1.1.
:::

## Overview

The STUSB4500 is a USB Power Delivery (PD) sink controller manufactured by STMicroelectronics. It implements a proprietary algorithm to negotiate power delivery contracts without MCU support (auto-run mode).

Key advantages:

- **USB-IF Certified**: Tested for interoperability with certified chargers
- **NVM Configuration**: Store up to 3 PDO profiles in non-volatile memory
- **Power Path Control**: VBUS_EN_SNK pin controls external load switch
- **Dead Battery Mode**: Can negotiate even with discharged battery
- **I2C Interface**: Optional MCU communication for advanced control

## Key Specifications

| Parameter | Value | Notes |
| --- | --- | --- |
| **JLCPCB Part Number** | C2678061 | |
| **Manufacturer Part Number** | STUSB4500QTR | |
| **Package** | QFN-24 (4mm × 4mm) | Surface-mount |
| **Stock Availability** | 4,728 units | Good availability |
| **Unit Price** | ~$2.50 | JLCPCB pricing |
| **VDD Voltage Range** | 4.1V - 22V DC | From USB-C VBUS |
| **VBUS Tolerance** | Up to 28V | Overvoltage tolerant |
| **CC Pin Protection** | Up to 22V | Short-to-VBUS protection |
| **Output Voltage Options** | 5V / 9V / 15V / 20V (configurable) | Via NVM programming |
| **Maximum Current** | 5A (100W) | Depends on PD source |
| **PD Protocol Support** | USB PD 2.0 / 3.0 | USB-IF certified |
| **Configuration Method** | NVM + I2C | No MCU required for basic use |
| **Operating Temperature** | -40°C to +105°C | |

## Pin Configuration

```
                 STUSB4500QTR (QFN-24)
                      Top View
    ┌──────────────────────────────────────┐
    │                                      │
    │ 1  CC1DB                   VDD    24 │
    │ 2  CC1                 VREG_2V7  23 │
    │ 3  NC                      VSYS  22 │
    │ 4  CC2                 VREG_1V2  21 │
    │ 5  CC2DB              POWER_OK2  20 │
    │ 6  RESET                  ALERT  19 │
    │ 7  SCL             VBUS_VS_DISCH 18 │
    │ 8  SDA                 A_B_SIDE  17 │
    │ 9  DISCH            VBUS_EN_SNK  16 │
    │ 10 GND                     GPIO  15 │
    │ 11 ATTACH            POWER_OK3   14 │
    │ 12 ADDR0                  ADDR1  13 │
    │                                      │
    │          ┌──────────────┐            │
    └──────────┤  Exposed Pad ├────────────┘
               │   GND (25)   │
               └──────────────┘

Note: Pin 16 (VBUS_EN_SNK) is critical for load switch control
```

### Pin Descriptions

| Pin | Name | Function | Connection in Design |
| --- | --- | --- | --- |
| 25  | GND (EPAD) | Ground / Thermal pad | System ground plane |
| 1 | CC1DB | CC1 dead battery mode | Connect to CC1 |
| 2 | CC1 | USB-C Configuration Channel 1 | USB-C CC1 via ESD protection (D4) |
| 3 | NC | No connection | Leave unconnected |
| 4 | CC2 | USB-C Configuration Channel 2 | USB-C CC2 via ESD protection (D4) |
| 5 | CC2DB | CC2 dead battery mode | Connect to CC2 |
| 6 | RESET | Active-HIGH reset | GND (normal operation) |
| 7 | SCL | I2C clock | NC (not used in this design) |
| 8 | SDA | I2C data | NC (not used in this design) |
| 9 | DISCH | VBUS discharge control | Via R13 (470Ω) to VBUS_OUT |
| 10  | GND | Ground | System ground |
| 11  | ATTACH | Cable attach indicator | NC (optional LED/MCU) |
| 12  | ADDR0 | I2C address bit 0 | GND (I2C address 0x28) |
| 13  | ADDR1 | I2C address bit 1 | GND (I2C address 0x28) |
| 14  | POWER_OK3 | PDO3 selected indicator | NC (optional LED/MCU) |
| 15  | GPIO | General purpose I/O | NC |
| 16  | VBUS_EN_SNK | **Load switch enable (active HIGH)** | To P-MOSFET gate via R12 (56kΩ) |
| 17  | A_B_SIDE | Cable orientation indicator | NC |
| 18  | VBUS_VS_DISCH | VBUS voltage sense / discharge | NC |
| 19  | ALERT | Interrupt output (open-drain) | NC |
| 20  | POWER_OK2 | PDO2 selected indicator | NC (optional LED/MCU) |
| 21  | VREG_1V2 | 1.2V internal regulator output | C34 (1µF) to GND |
| 22  | VSYS | System voltage input (3.0-5.5V) | Tie to VREG_2V7 (pin 23) |
| 23  | VREG_2V7 | 2.7V internal regulator output | C30 (1µF) to GND, also to VSYS |
| 24  | VDD | Main power supply (4.1-22V) | VBUS_IN + C1 (10µF) + C2 (100nF)  |
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

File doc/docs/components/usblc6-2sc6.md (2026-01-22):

---
sidebar_position: 5
---

# USBLC6-2SC6 - USB ESD Protection (D4)

TVS diode array for USB Type-C CC line and VBUS ESD protection. Replaces ESDA25L in v1.1 design.

- [View on JLCPCB: C7519](https://jlcpcb.com/partdetail/C7519)
- [Download Datasheet (PDF)](https://www.st.com/resource/en/datasheet/usblc6-2.pdf)

## Overview

The USBLC6-2SC6 is a 6-pin TVS diode array specifically designed for USB ESD protection. It provides 2 bidirectional channels for data/CC lines plus a VBUS protection channel, making it ideal for USB Type-C applications.

:::tip Why USBLC6-2SC6 over ESDA25L?
| Feature | ESDA25L | USBLC6-2SC6 |
|---|---|---|
| Clamping Voltage | ~44V | **~17V** |
| VBUS Protection | No | **Yes (Pin 5)** |
| Working Voltage | 25V | 5.25V |
| Capacitance | 3pF | 3.5pF |
| Design Target | High-voltage lines | **USB signals** |

USBLC6-2SC6 has lower clamping voltage, providing better protection for CC lines operating at ~1.7V.
:::

## Key Specifications

| Parameter | Value | Notes |
| --- | --- | --- |
| **JLCPCB Part Number** | C7519 | |
| **Manufacturer Part Number** | USBLC6-2SC6 | STMicroelectronics |
| **Package** | SOT-23-6 | 6-pin surface-mount |
| **Stock Availability** | 354,000+ | Excellent availability |
| **Unit Price** | ~$0.13 | |
| **Working Voltage** | 5.25V | USB specification |
| **Breakdown Voltage** | 6V min | |
| **Clamping Voltage** | 17V @ 1A | Much lower than ESDA25L  |
| **Peak Pulse Current** | 3A | 8/20µs waveform |
| **Capacitance** | 3.5pF typ | Low impact on CC signals |
| **ESD Rating** | 15kV (HBM)  | IEC 61000-4-2 |
| **Channels** | 2 + VBUS | I/O1, I/O2, and VBUS |
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

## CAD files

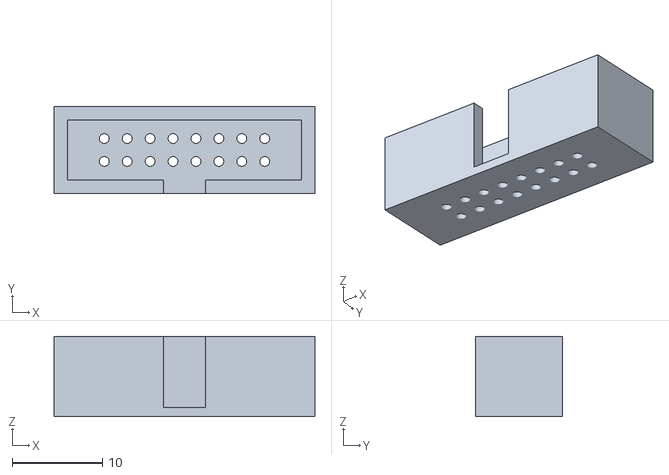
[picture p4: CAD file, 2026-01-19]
3dp-files/box-header/box-header.stl
28.9 x 9.60 x 8.90

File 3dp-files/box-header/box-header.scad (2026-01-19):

// IDC box connector frame for pin headers - WITH CENTER DIVIDER
// Based on design by John Stäck 2018
// Licensed under Creative Commons Attribution Share-alike 4.0 (CC BY-SA 4.0)
// https://creativecommons.org/licenses/by-sa/4.0/
//
// Modifications:
// - Changed bottom_thickness to 1.0mm (was 0.5mm, too thin)
// - Changed pin_hole_diameter to 1.2mm (0.8mm, 1.0mm were too tight)
// - Added center divider on bottom surface

//Number of pins in one row of connector (half number of total pins)
n_pins = 8;

//How much to increase size of things to allow for good fit
printer_fudge = 0.2;

//Standard pin pitch
pin_pitch = 2.54;

//Pin size from C5383092 datasheet (SQ.0.64)
pin_size = 0.64;

//Tight clearance for 3D printed plastic (press-fit)
tight_clearance = 0.2;

//Dimensions of IDC connector
connector_length = 5.4+pin_pitch*n_pins;
connector_width = 6.4;

//Size of pin header base holes - TIGHT FIT based on actual pin dimensions
//Length: pin span + pin size + clearance
base_length = pin_pitch*(n_pins-1) + pin_size + tight_clearance;  // 17.78 + 0.64 + 0.2 = 18.62mm
//Width of each slot
slot_width = 0.6;  // Adjusted after print test (0.4 was too tight)

//Size of orientation tab
tab_width=4.5;
tab_height=5.5; //Arbitrary number. Have no specs on this

//Height of standard IDC box header.
height=8.9;

//The height of a regular pin header plastic base
// MODIFIED: Changed from pin_pitch (2.54mm) to 1.0mm (0.5mm was too thin)
bottom_thickness=1.0;


//These are default sizes for the outside of the box
/*
outside_length = 7.6+pin_pitch*n_pins;
outside_width = 8.8;
*/

//Outside dimensions, a bit thicker for more sturdiness when printed.
wall_thickness = 1.5;

outside_length = connector_length + 2*wall_thickness + printer_fudge;
outside_width = connector_width + 2*wall_thickness + printer_fudge;

conn_length_actual = connector_length + printer_fudge;
conn_width_actual = connector_width + printer_fudge;

tab_width_actual = tab_width + printer_fudge;

// ADDED: Center divider - calculated from row spacing minus slot widths
// Divider fills the gap between the two pin row slots
divider_thickness = pin_pitch - slot_width;  // 2.54 - 0.84 = 1.7mm

// Pin hole diameter - MODIFIED: 1.1mm (0.8mm, 1.0mm too tight, 1.2mm too loose)
pin_hole_diameter = 1.1;


difference() {
    cube([outside_length, outside_width, height]);

    //All the things "cut out" are from center origin to make things easier to follow
    translate([outside_length/2, outside_width/2, 0]) {

        //Hole for connector (single open cavity above bottom plate)
        translate([-conn_length_actual/2, -conn_width_actual/2, bottom_thickness])
            cube([conn_length_actual, conn_width_actual, height]);

        //Tab (key notch for IDC connector) - extends from bottom plate to top
        //Bottom plate remains intact at tab end (no foot separator)
        translate([-tab_width_actual/2, -outside_width, bottom_thickness])
            cube([tab_width_actual, outside_width, height]);

        //Pin holes (2x8 grid) - 1.1mm diameter at 2.54mm pitch
        for (col = [0 : n_pins-1]) {
            for (row = [0 : 1]) {
                translate([
                    -pin_pitch*(n_pins-1)/2 + col*pin_pitch,  // X position
                    -pin_pitch/2 + row*pin_pitch,              // Y position (row 0 and row 1)
                    -0.1                                        // Z position (through bottom)
                ])
                cylinder(d=pin_hole_diameter, h=bottom_thickness+0.2, $fn=16);
            }
        }

    }

}

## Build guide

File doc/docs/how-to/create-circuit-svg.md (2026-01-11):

---
sidebar_position: 4
---

# Create Circuit SVG Files for Documentation

This guide explains how to create professional circuit diagrams using schemdraw and integrate them into the documentation.

## Overview

Circuit diagrams are generated using the schemdraw Python library with a systematic workflow that ensures electrical accuracy and visual clarity.

## Prerequisites

- Python 3.7 or later
- schemdraw library installed (`pip install schemdraw`)
- `/schemdraw-circuit-generator` skill configured

## Design Workflow

### Step 1: Collect Parts Data

Use the `/jlcpcb` skill to search for and verify component availability:

```bash
# Example: Search for buck converter
/jlcpcb LM2596S
```

Document:

- Part numbers
- Specifications (voltage ratings, current ratings, package types)
- JLCPCB stock codes
- Key specifications (resistance, capacitance, inductance, etc.)

### Step 2: Create ASCII Art Draft

Start with ASCII art circuit diagram in markdown code blocks. This serves as the specification for the final diagram.

**Example:**

```
+15V ─────┬─── L1: 100µH ──┬─── D1 ──┬─── C3: 470µF ──┬─→ +13.5V
          │    (4.5A)      │   SS34  │    (25V)       │
          │                │    ↓    │                │
          │           ┌────┴─────────┴──┐             │
          │           │5  VIN      OUT │4────────────┤
          └───────────┤3  ON        FB │2─────┬──────┘
                      │1  GND          │      │
                      └────────────────┘      │
                              │               │
                             GND          ┌───┴───┐
                                          │ R1    │ 10kΩ
                                          │ 10kΩ  │
                                          └───┬───┘
                                          ┌───┴───┐
                                          │ R2    │ 1kΩ
                                          │ 1kΩ   │
                                          └───┬───┘
                                              │
                                             GND
```

**Create Connection List:**

```
Connections:
- +15V input → U2 (LM2596S) pin 5 (VIN)
- +15V input → C5 (100µF) → GND
- U2 pin 3 (ON) → +15V (always enabled)
- U2 pin 4 (VOUT) → Switching node
- Switching node → L1 (100µH) → +13.5V Output
- Switching node → D1 (SS34 cathode)
- D1 (SS34 anode) → GND
- +13.5V → C3 (470µF) → GND
- U2 pin 2 (FB) → R1 (10kΩ) → Tap
- Tap → R2 (1kΩ) → GND
- Tap → +13.5V (feedback sense)
- U2 pin 1 (GND) → GND
```

### Step 3: Generate Schemdraw Diagram

Use the `/schemdraw-circuit-generator` skill to create professional circuit diagram:

```bash
/schemdraw-circuit-generator
```

Provide the connection list from Step 2 as the specification.

**Configuration:**

- **Theme**: Black foreground with transparent background (default)
- **Font**: Arial, 11pt
- **Color**: Black lines and text
- **Background**: Transparent (allows container background to show through)

**Example Python Code:**

```python
#!/usr/bin/env python3
"""
LM2596S-ADJ Buck Converter: +15V → +13.5V
Complete circuit with transparent background, black foreground, Arial font
"""

import schemdraw
from schemdraw import elements as elm

with schemdraw.Drawing(
    font='Arial',         # Sans-serif font
    fontsize=11,
    color='black',        # Foreground: black
    transparent=True      # Transparent background
) as d:
    d.config(unit=3)

    # IC definition
    ic = elm.Ic(
        pins=[
            elm.IcPin(name='GND', pin='3', side='left', slot='1/3'),
            elm.IcPin(name='ON', pin='5', side='left', slot='2/3'),
            elm.IcPin(name='VIN', pin='1', side='left', slot='3/3'),
            elm.IcPin(name='FB', pin='4', side='right', slot='1/2'),
            elm.IcPin(name='VOUT', pin='2', side='right', slot='2/2'),
        ],
        edgepadW=2.5,
        edgepadH=0.8,
        pinspacing=1.0,
        leadlen=1.0
    ).label('U2\nLM2596S', loc='center', fontsize=10)

    # Add all other components following the connection list...

    # Save to docs/_fragments
    import os
    script_dir = os.path.dirname(os.path.abspath(__file__))
    output_path = os.path.join(script_dir, '../docs/_fragments/buck-u2-diagram.svg')
    d.save(output_path)

print("✓ Buck converter diagram generated with transparent background")
```

### Step 4: Execute and Save

```bash
# Run the Python script
cd /Users/takazudo/repos/personal/zudo-pd/diagram-sources
python3 buck-u2-diagram.py

# Output: SVG saved to /doc/docs/_fragments/buck-u2-diagram.svg
```

### Step 5: Integrate into Documentation

Import and use the SVG in MDX files using the `CircuitSvg` component:

```jsx
import CircuitSvg from '@site/src/components/CircuitSvg';
import BuckU2Diagram from '@site/static/circuits/buck-u2-diagram.svg';

<CircuitSvg src={BuckU2Diagram} alt="LM2596S Buck Converter U2" />;
```

### Step 6: Hide ASCII Art (Optional)

Keep the ASCII art draft but collapse it using HTML `<details>` element:

```html
<details>
  <summary>View ASCII art version</summary>
</details>
```

[ASCII diagram here]

```

</details>
```

Keep the connection list visible for reference.

## Directory Structure

```
project/
├── diagram-sources/
│   └── *.py                        # Schemdraw Python source files
├── doc/
│   └── docs/
│       └── _fragments/
│           ├── CircuitSvg.jsx      # Click-to-enlarge component
│           ├── CircuitDialog.jsx   # Fullscreen dialog
│           └── *.svg               # Generated circuit diagrams
```

## Schemdraw Configuration

### Default Settings

```python
with schemdraw.Drawing(
    font='Arial',         # Sans-serif font
    fontsize=11,
    color='black',        # Black foreground
    transparent=True      # Transparent background
) as d:
    d.config(unit=3)      # Scale factor
    # ... circuit elements ...
```

### Why Transparent Background with Black Foreground?

- Allows HTML container background (`oklch(86.9% 0.005 56.366)`) to show through
- Black lines and text are visible on light container backgrounds
- Works seamlessly with web-based documentation (Docusaurus)
- Professional appearance with clean contrast
- Integrates with any light-themed documentation

### Alternative: Solid Background (If Needed)

```python
# Dark theme with solid black background
with schemdraw.Drawing(
    font='Arial',
    fontsize=11,
    color='white',
    bgcolor='black'
) as d:
    # ... circuit elements ...
```

## Best Practices

### 1. Consistent Label Positioning

For vertical components (resistors, capacitors going up/down):

```python
# For components going upward
elm.Capacitor().up(2.0).label('C3\n470µF\n25V', loc='bot', ofst=0.5)
elm.Ground().flip()  # Flipped ground at top

# For components going downward
elm.Resistor().down().label('R1\n10kΩ', loc='bot', ofst=0.5)
elm.Ground()  # Normal ground at bottom
```

### 2. IC Edge Padding

Use adequate `edgepadW` parameter to prevent label overlap:

```python
ic = elm.Ic(
    pins=[...],
    edgepadW=2.5,  # Wider box prevents label overlap
    edgepadH=0.8,
    pinspacing=1.0,
    leadlen=1.0
).label('U2\nLM2596S', loc='center', fontsize=10)
```

### 3. Precise Junction Positioning

Calculate position mathematically for symmetrical connections:

```python
# For horizontal rail between two pins
junction_y = (ic.VIN[1] + ic.ON[1]) / 2

# Build entire rail at calculated height
elm.Dot(open=True).at((x_position, junction_y)).label('+15V', loc='left')
elm.Line().right(2.0)
elm.Dot()
```

### 4. Ground Symbol Orientation

```python
# Component going UP - flip ground
elm.Capacitor().up(2.0)
elm.Ground().flip()  # Ground symbol at top, points down

# Component going DOWN - normal ground
elm.Resistor().down()
elm.Ground()  # Ground symbol at bottom, points down
```

## Using CircuitSvg Component

The `CircuitSvg` component provides click-to-enlarge functionality:

```jsx
<CircuitSvg src={DiagramSvg} alt="Circuit Description" />
```

**Features:**

- Click to open fullscreen (90vw × 90vh)
- Background color: `oklch(86.9% 0.005 56.366)`
- Padding: 20px (both thumbnail and dialog)
- Maintains aspect ratio
- Keyboard accessible (Enter/Space to open)

## Troubleshooting

### Problem: Import errors in Python

**Solution**: Install schemdraw:

```bash
pip install schemdraw
```

### Problem: SVG has black background

**Solution**: Ensure you're using `transparent=True` instead of `bgcolor='black'`:

```python
# ✅ Correct
with schemdraw.Drawing(transparent=True) as d:

# ❌ Wrong
with schemdraw.Drawing(bgcolor='black') as d:
```

### Problem: Lines or text appear white on light background

**Solution**: Use `color='black'` for foreground:

```python
# ✅ Correct for transparent background
with schemdraw.Drawing(color='black', transparent=True) as d:

# ❌ Wrong (white lines invisible on light background)
with schemdraw.Drawing(color='white', transparent=True) as d:
```

### Problem: Labels overlap component symbols

**Solution**: Increase spacing and adjust label positions:

```python
# Increase overall spacing
d.config(unit=3)  # or larger

# Adjust individual spacing
HORIZONTAL_SPACING = 1.5  # Increase from 1.0
VERTICAL_SPACING = 1.5

# Adjust label positions
elm.Resistor().label('R1\n10kΩ', loc='top', ofst=0.2)
```

## Complete Example Workflow

```bash
# 1. Create connection list (ASCII art + detailed connections)
# Document in markdown: circuit-diagrams.md

# 2. Use schemdraw skill to generate Python code
/schemdraw-circuit-generator

# 3. Save Python code to /diagram-sources/
# Example: /diagram-sources/buck-u2-diagram.py

# 4. Execute Python script
cd /Users/takazudo/repos/personal/zudo-pd/diagram-sources
python3 buck-u2-diagram.py

# 5. Verify SVG output
ls -l doc/docs/_fragments/buck-u2-diagram.svg

# 6. Test in documentation
cd /Users/takazudo/repos/personal/zudo-pd/doc
npm start
# Open: http://localhost:3000/do../components/lm2596s-adj

# 7. Commit both Python source and SVG
git add diagram-sources/buck-u2-diagram.py
git add doc/docs/_fragments/buck-u2-diagram.svg
git commit -m "Add LM2596S buck converter circuit diagram"
```

## Quality Checklist

Before considering a circuit diagram complete:

- ✅ Parts verified in JLCPCB database
- ✅ Connection list is accurate and complete
- ✅ ASCII art draft follows all golden rules
- ✅ Schemdraw SVG generated with transparent background and black foreground
- ✅ Click-to-enlarge works correctly
- ✅ ASCII art hidden in `<details>` element (optional)
- ✅ Connection list remains visible
- ✅ Both SVG and Python source committed

## References

- [schemdraw Documentation](https://schemdraw.readthedocs.io/)
- schemdraw-circuit-generator Skill (Claude Code skill for circuit generation)
- [Circuit Diagrams Page](/docs/overview/circuit-diagrams)

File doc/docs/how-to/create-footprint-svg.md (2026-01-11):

---
sidebar_position: 3
---

# Create Footprint SVG Files for Documentation

This guide explains how to export KiCad footprints to SVG format and prepare them for use in the documentation.

## Overview

The documentation displays clickable footprint previews on each component page. This workflow converts KiCad `.kicad_mod` files to clean SVG images.

## Prerequisites

- KiCad 9.0.6 or later (with `kicad-cli` command)
- Python 3 (for cleanup script)
- KiCad footprints downloaded (see [KiCad Parts Download Guide](./kicad-parts-download.md))

## Verify KiCad CLI

```bash
kicad-cli --version
# Should show: Version: 9.0.6 or later
```

If `kicad-cli` is not found, you need to add it to your PATH:

**macOS:**

```bash
export PATH="/Applications/KiCad/KiCad.app/Contents/MacOS:$PATH"
```

**Linux:**

```bash
# Usually already in PATH after KiCad installation
```

**Windows:**

```powershell
# Add KiCad installation directory to PATH
# Typically: C:\Program Files\KiCad\bin
```

## Workflow

### Step 1: Prepare .pretty Directory

KiCad CLI requires footprints in a `.pretty` directory structure:

```bash
cd /Users/takazudo/repos/personal/zudo-pd/footprints/kicad

# Create .pretty directory
mkdir -p zudo-power.pretty

# Copy .kicad_mod files
cp *.kicad_mod zudo-power.pretty/
```

### Step 2: Export to SVG

Export all footprints to SVG format with black-and-white rendering:

```bash
cd /Users/takazudo/repos/personal/zudo-pd/footprints

# Export SVGs
kicad-cli fp export svg kicad/zudo-power.pretty -o images --black-and-white
```

**Output:** SVG files are saved to `footprints/images/`

### Step 3: Clean SVG Files

Remove KiCad placeholder text (REF**, VAL**) from SVGs using the cleanup script:

```bash
cd /Users/takazudo/repos/personal/zudo-pd/footprints

# Run cleanup script
python3 scripts/clean-svg-refs.py images/
```

The script removes:

- `REF**` placeholder text
- `VAL**` placeholder text
- Both text elements and stroked-text path groups

### Step 4: Copy to Documentation

```bash
cd /Users/takazudo/repos/personal/zudo-pd/footprints

# Copy cleaned SVGs to documentation fragments
cp images/*.svg ../doc/docs/_fragments/footprints/
```

### Step 5: Verify Results

Check that SVGs are clean:

```bash
cd /Users/takazudo/repos/personal/zudo-pd/doc/docs/_fragments/footprints

# Quick check: should find NO instances of REF** in SVG files
grep -l "REF\*\*" *.svg
# (No output = success)
```

## Directory Structure

```
project/
├── footprints/
│   ├── kicad/
│   │   ├── *.kicad_mod              # Original KiCad footprints
│   │   └── zudo-power.pretty/       # .pretty directory for export
│   │       └── *.kicad_mod
│   ├── images/
│   │   └── *.svg                    # Exported and cleaned SVGs
│   └── scripts/
│       └── clean-svg-refs.py        # Cleanup script
└── doc/
    └── docs/
        └── _fragments/
            └── footprints/
                └── *.svg            # Final SVGs for documentation
```

## Cleanup Script Details

### Location

`/Users/takazudo/repos/personal/zudo-pd/footprints/scripts/clean-svg-refs.py`

### What It Does

The script processes SVG files to remove KiCad placeholders:

1. **Text Elements**: Removes `<text>` elements containing `REF**` or `VAL**`
2. **Stroked-Text Groups**: Removes path-based text rendered as vector shapes
3. **Preserves**: All footprint geometry, pads, and silkscreen

### Usage

```bash
# Clean all SVGs in a directory
python3 clean-svg-refs.py /path/to/svg/directory/

# The script modifies files in-place
# Creates no backup - commit to git first!
```

### Verification

The script reports how many elements were removed:

```
Processing: QFN-20_L3.0-W3.0-P0.40-BL-EP1.7.svg - Removed 2 elements
Processing: TO-263-5_L10.2-W8.9-P1.70-BR.svg - Removed 2 elements
...
✓ Processed 28 SVG files
```

## Using Footprints in Documentation

### Import and Use FootprintSvg Component

In MDX files (e.g., component pages):

```jsx
import FootprintSvg from '@site/src/components/FootprintSvg';
import CH224D from '@site/static/footprints-svg/QFN-20_L3.0-W3.0-P0.40-BL-EP1.7.svg';

<FootprintSvg src={CH224D} alt="CH224D QFN-20 Package" minWidth="300px" minHeight="300px" />;
```

### Component Features

- Click-to-enlarge (90vw × 90vh fullscreen dialog)
- Background color: `oklch(86.9% 0.005 56.366)`
- Padding: 20px
- Maintains aspect ratio

## Troubleshooting

### Problem: kicad-cli not found

**Solution**: Add KiCad to PATH (see "Verify KiCad CLI" above)

### Problem: Export fails with "Library not found"

**Solution**: Ensure footprints are in a `.pretty` directory:

```bash
# Correct structure:
footprints/kicad/zudo-power.pretty/QFN-20_L3.0-W3.0-P0.40-BL-EP1.7.kicad_mod

# Wrong structure:
footprints/kicad/QFN-20_L3.0-W3.0-P0.40-BL-EP1.7.kicad_mod
```

### Problem: SVG still shows REF\*\* after cleanup

**Solution**:

1. Check that cleanup script ran successfully
2. Some SVGs may have additional text elements - inspect manually:
   ```bash
   grep "REF\*\*" problem-file.svg
   ```
3. Update cleanup script if needed

### Problem: SVG appears blank in documentation

**Solution**:

1. Verify SVG file is not corrupted:
   ```bash
   head -5 footprint.svg
   # Should show valid SVG header
   ```
2. Check import path is correct
3. Verify file was copied to `docs/_fragments/footprints/`

## Complete Example Workflow

```bash
# 1. Navigate to footprints directory
cd /Users/takazudo/repos/personal/zudo-pd/footprints

# 2. Create .pretty directory structure
mkdir -p kicad/zudo-power.pretty
cp kicad/*.kicad_mod kicad/zudo-power.pretty/

# 3. Export to SVG
kicad-cli fp export svg kicad/zudo-power.pretty -o images --black-and-white

# 4. Clean SVG files
python3 scripts/clean-svg-refs.py images/

# 5. Verify cleanup
grep -l "REF\*\*" images/*.svg
# (No output = success)

# 6. Copy to documentation
cp images/*.svg ../doc/docs/_fragments/footprints/

# 7. Verify in documentation
cd ../doc
npm start
# Open browser to http://localhost:3000/docs/components
```

## Next Steps

- [View Footprint Preview](../misc/footprint-preview.md) - See all footprints in the documentation
- Update component pages to include new footprints
- Commit changes to git

## References

- [KiCad CLI Documentation](https://docs.kicad.org/master/en/cli/cli.html)
- [SVG Specification](https://www.w3.org/TR/SVG2/)

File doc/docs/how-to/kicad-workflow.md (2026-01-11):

# KiCad Project Workflow

Complete workflow for creating a PCB design in KiCad, from schematic to manufacturing files.

## Prerequisites

**CRITICAL:** Before starting, ensure your KiCad project files are located at the repository root:

```
zudo-pd/          ← Repository root
├── zudo-pd.kicad_pro       ← Project file must be here
├── zudo-pd.kicad_sch       ← Schematic file
├── zudo-pd.kicad_pcb       ← PCB file (created later)
└── footprints/             ← Footprint library
    └── kicad/
        └── zudo-power.pretty/
```

The `${KIPRJMOD}` variable in KiCad points to the directory containing the `.kicad_pro` file. If your project is in a subdirectory (like `kicad/` or `pcb/`), relative paths to footprints and libraries won't resolve correctly.

## Overview

KiCad uses a modular workflow where you work with different editors in sequence:

1. **Symbol Editor** - Create/import schematic symbols
2. **Schematic Editor** - Draw circuit diagrams
3. **Footprint Editor** - Create/import PCB footprints
4. **PCB Editor** - Layout the physical board
5. **Manufacturing Output** - Generate Gerber files

## Stage 1: Symbol Management

### 1.1 Check Existing Libraries

Before creating custom symbols, check if they already exist in KiCad's standard libraries:

**Common libraries for this project:**

- `Device` - Resistors, capacitors, inductors, diodes, LEDs
- `Regulator_Linear` - LM78xx, LM79xx series
- `Regulator_Switching` - LM2596, buck/boost converters
- `Connector` - USB connectors, power jacks, headers
- `power` - GND, VCC, voltage symbols

**To check:**

1. Open **Symbol Editor**
2. File → Add Library... → Browse standard KiCad libraries
3. Search for your part number or category

### 1.2 Import Symbols from Standard Libraries

For parts already in KiCad libraries:

1. Open **Schematic Editor**
2. Press `A` (Add Symbol)
3. Search by part name (e.g., "LM7812", "USB_C_Receptacle")
4. Browse by library category if unsure

### 1.3 Create Custom Symbols

For parts NOT in standard libraries (like CH224Q, specialized ICs):

**Method 1: Import from EasyEDA/LCSC**

Use `easyeda2kicad.py` to download both symbols and footprints:

```bash
# Download symbol + footprint for CH224Q (LCSC ID: C970725)
easyeda2kicad --lcsc_id C970725 --symbol --footprint

# Files saved to:
# ~/Documents/Kicad/easyeda2kicad/easyeda2kicad.pretty/  (footprints)
# ~/Documents/Kicad/easyeda2kicad/easyeda2kicad.kicad_sym (symbols)
```

**Method 2: Manual Creation**

1. Open **Symbol Editor**
2. File → New Library... → Create project-specific library (e.g., `zudo-power.kicad_sym`)
3. Create New Symbol
4. Define:
   - Pin numbers and names (from datasheet)
   - Pin electrical types (input, output, power, passive)
   - Symbol shape (rectangle, specialized)
   - Reference designator (U, R, C, J, etc.)

**Best practices:**

- Match datasheet pin numbering exactly
- Use descriptive pin names (VIN, VOUT, FB, EN, etc.)
- Set correct electrical types for ERC (Electrical Rule Check)
- Add datasheet link in symbol properties

## Stage 2: Schematic Creation

### 2.1 Create New Schematic

1. Open **Schematic Editor** (`zudo-pd.kicad_sch`)
2. Set up page properties:
   - Title: "USB-PD Modular Synth Power Supply"
   - Revision: v1.0
   - Date: (automatic)
   - Company/Organization (optional)

### 2.2 Place Symbols

1. Press `A` to add symbols
2. Search and place all components
3. Use logical groupings:
   - USB-PD input stage (left side)
   - DC-DC converters (center)
   - Linear regulators (right)
   - Output connectors (far right)

**Recommended layout flow:**

```
Left to Right = Signal Flow
USB-C Input → DC-DC Conversion → Linear Regulation → Outputs
```

### 2.3 Wire Connections

1. Press `W` to start wiring
2. Click start point → Click end point
3. Use labels for:
   - Power nets: `+15V`, `+13.5V`, `+12V`, `+5V`, `-12V`, `-15V`
   - Ground: `GND` (use power symbol)
   - Signal names: `PG` (Power Good), `EN` (Enable), `FB` (Feedback)

**Best practices:**

- Use net labels instead of long wires across the page
- Group related components close together
- Keep power flow left-to-right, top-to-bottom
- Add `No Connect` flags (X) to unused pins

### 2.4 Add Power Symbols

1. Press `P` to add power symbols
2. Add for each voltage rail:
   - `+12V`, `+5V`, `-12V` (outputs)
   - `+15V`, `+13.5V`, `-13.5V` (intermediate)
   - `GND` (ground reference)

### 2.5 Add Values and References

For each component:

1. Select component
2. Press `E` to edit properties
3. Set:
   - **Reference** (auto-numbered: U1, R1, C1, etc.)
   - **Value** (10µF, 5.1kΩ, LM7812, etc.)
   - **Footprint** (assigned in next step)
   - **Datasheet URL** (optional but recommended)

### 2.6 Annotate Schematic

Auto-number all reference designators:

1. Tools → Annotate Schematic
2. Select "Use entire schematic" (for multi-sheet projects)
3. Click "Annotate"

**Result:** R?, C?, U? become R1, R2, C1, C2, U1, U2, etc.

### 2.7 Electrical Rules Check (ERC)

Before proceeding to PCB:

1. Inspect → Electrical Rules Checker
2. Run ERC
3. Fix all errors:
   - Unconnected pins
   - Power pins not driven
   - Conflicting outputs
   - Missing power connections

## Stage 3: Footprint Assignment

### 3.1 Import Footprints

**For JLCPCB-compatible parts:**

See [KiCad Parts Download Guide](./kicad-parts-download.md) for detailed instructions.

**Quick workflow:**

```bash
# Download footprint by LCSC ID
easyeda2kicad --lcsc_id C970725 --footprint

# Copy to project directory
cp ~/Documents/Kicad/easyeda2kicad/easyeda2kicad.pretty/*.kicad_mod ./footprints/kicad/
```

### 3.1a Add Footprint Library to KiCad

**IMPORTANT:** Before adding the footprint library, ensure your KiCad project (`.kicad_pro` file) is located in the repository root directory. The `${KIPRJMOD}` variable points to the project file location, so if your project is in a subdirectory (like `kicad/`), the relative paths won't resolve correctly.

**Project structure:**

```
zudo-pd/          ← Repository root
├── zudo-pd.kicad_pro       ← KiCad project file should be here
├── zudo-pd.kicad_sch       ← Schematic file
├── zudo-pd.kicad_pcb       ← PCB file
└── footprints/
    └── kicad/
        └── zudo-power.pretty/   ← Footprint library
            ├── C0603.kicad_mod
            ├── C0805.kicad_mod
            └── ... (37 footprints)
```

**Steps to add footprint library:**

1. **Open Preferences → Manage Footprint Libraries**
   - From main KiCad window (NOT Symbol Editor)
   - Or from PCB Editor: Preferences → Manage Footprint Libraries

2. **Click "Project Specific Libraries" tab** (at bottom)

3. **Add new library:**
   - Click folder icon (➕) to add library
   - Set values:
     - **Nickname**: `zudo-pd` (or any name you prefer)
     - **Library Path**: `${KIPRJMOD}/footprints/kicad/zudo-power.pretty`
     - **Library Format**: `KiCad`
     - **Options**: (leave blank)

4. **Click OK**

**Example configuration:**

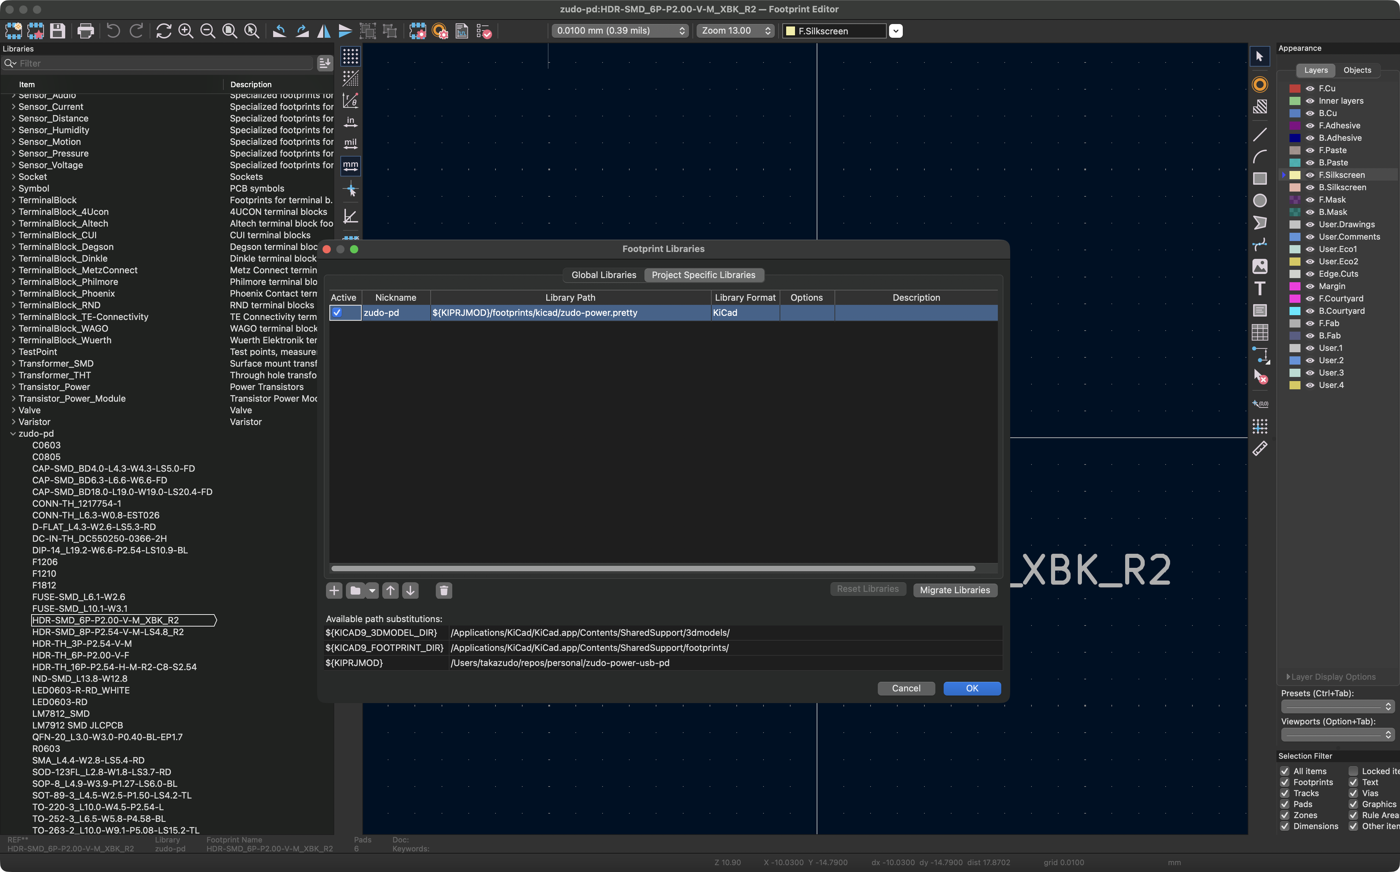
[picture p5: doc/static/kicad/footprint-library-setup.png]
Footprint Library Setup


The dialog should show:

- Library nickname: `zudo-pd`
- Library path: `${KIPRJMOD}/footprints/kicad/zudo-power.pretty`
- At the bottom, "Available path substitutions" shows the resolved path

**Verify the library loaded:**

1. Open **Footprint Editor** (from main KiCad window)
2. Check left panel - you should see `zudo-pd` library
3. Click on it to expand and browse 37 footprints
4. You should see footprints like:
   - `C0603`, `C0805` (capacitors)
   - `TO-252-3`, `TO-263-2` (IC packages)
   - `SOP-8`, `SSOP-10` (IC packages)
   - Component-specific footprints

**Troubleshooting:**

- **Library appears empty:** Verify the path points to `zudo-power.pretty` directory (not `.pretty` or other directories)
- **Path not found:** Check that `${KIPRJMOD}` resolves correctly by looking at "Available path substitutions" at bottom of dialog
- **Wrong symbols showing:** You opened Symbol Libraries instead of Footprint Libraries - close and reopen the correct dialog

### 3.2 Assign Footprints to Symbols

1. In Schematic Editor: Tools → Assign Footprints
2. For each component, select appropriate footprint:
   - **Resistors/Capacitors**: `0805`, `1206` (SMD sizes)
   - **ICs**: Match package type from datasheet (SOIC-8, SOT-23-6, etc.)
   - **Connectors**: Match mechanical dimensions exactly
   - **Large components**: Verify pad sizes for current rating

**Example assignments:**

- LM7812 → `TO-252-2` (DPAK)
- LM2596S → `TO-263-5` (D2PAK)
- CH224Q → `ESSOP-10` (from LCSC)
- 10µF capacitor → `C_0805_2012Metric`
- 5.1kΩ resistor → `R_0805_2012Metric`

### 3.3 Verify Footprint Assignments

1. Check that ALL components have footprints assigned (no "No Footprint" entries)
2. Verify footprint sizes match your requirements:
   - Small passives: 0805 or 1206 (easy hand soldering)
   - ICs: Match JLCPCB assembly capabilities
   - Connectors: Match mechanical specs exactly

## Stage 4: PCB Layout

### 4.1 Generate Netlist and Import to PCB

1. In Schematic Editor: Tools → Update PCB from Schematic (F8)
2. Click "Update PCB"
3. PCB Editor opens with all components loaded

**First import:** Components appear in a cluster, ready to be positioned

### 4.2 Set Board Dimensions

1. Select **Edge.Cuts** layer
2. Draw board outline:
   - Press `Ctrl+Shift+P` for polygon tool
   - Draw rectangle or custom shape
   - Recommended: Start with 100mm × 80mm for this project

### 4.3 Place Components

**Strategic placement:**

1. **Input stage (left):**
   - USB-C connector on board edge
   - CH224Q near connector
   - Input capacitors near CH224Q

2. **DC-DC stage (center):**
   - LM2596S converters in row
   - Inductors next to each converter
   - Output capacitors after inductors

3. **Linear regulators (right of center):**
   - LM7812, LM7805, LM7912 in row
   - Input/output capacitors adjacent

4. **Output connectors (right edge):**
   - Power headers on board edge
   - Fuses before output
   - TVS diodes near output

**Best practices:**

- Keep signal paths short (especially high-current paths)
- Place decoupling capacitors close to IC power pins
- Orient components for logical layout
- Leave space for heat dissipation (regulators, DC-DC)
- Group by function, not just by type

### 4.4 Route Traces

**Layer strategy:**

- **F.Cu (Top layer):** Power traces, signal routing
- **B.Cu (Bottom layer):** Ground plane + additional routing

**Trace widths (for 1oz copper):**

- Power traces (1A+): 0.5mm minimum, 1.0mm recommended
- Signal traces: 0.25mm minimum, 0.3mm recommended
- Ground/return: Wide as possible, or use ground plane

**Routing order:**

1. Route power traces first (+15V, +12V, +5V, -12V)
2. Route critical signals (feedback, enable pins)
3. Route remaining connections
4. Add ground plane on bottom layer (Fill Zone)

**Tools:**

- Press `X` to start routing
- Press `V` to add via (switch layers)
- Press `D` to drag component while maintaining connections

### 4.5 Add Ground Plane

1. Select **B.Cu** layer
2. Press `Ctrl+Shift+Z` to add filled zone
3. Draw zone around entire board
4. Set net: `GND`
5. Press `B` to rebuild all zones

### 4.6 Design Rule Check (DRC)

Before manufacturing:

1. Inspect → Design Rules Checker
2. Run DRC
3. Fix all errors:
   - Trace clearance violations
   - Unconnected nets
   - Board outline issues
   - Silkscreen over pads

## Stage 5: Manufacturing Output

### 5.1 Generate Gerber Files

1. File → Fabrication Outputs → Gerbers (.gbr)
2. Settings:
   - Include layers: F.Cu, B.Cu, F.Mask, B.Mask, F.Silkscreen, B.Silkscreen, Edge.Cuts
   - Coordinate format: 4.6, unit mm
   - Check "Use Protel filename extensions"
3. Click "Plot"

### 5.2 Generate Drill Files

1. File → Fabrication Outputs → Drill Files (.drl)
2. Settings:
   - Drill units: Millimeters
   - Drill map: PostScript or PDF (for verification)
3. Click "Generate Drill File"

### 5.3 Generate BOM (Bill of Materials)

1. In Schematic Editor: File → Fabrication Outputs → BOM
2. Use built-in generator or:
   - Export to CSV
   - Use external tool (KiBoM, InteractiveHtmlBom)

**For JLCPCB assembly:**

- Must include: Reference, Value, Footprint, LCSC Part Number
- Export as CSV format
- Match JLCPCB template exactly

### 5.4 Generate Pick-and-Place File

For SMT assembly:

1. File → Fabrication Outputs → Component Placement (.pos)
2. Format: CSV
3. Units: Millimeters
4. Includes: Reference, X, Y, Rotation, Layer

### 5.5 Verify with Gerber Viewer

1. Open **GerbView** (included with KiCad)
2. Load all Gerber files + drill file
3. Check:
   - Board outline correct
   - All pads visible
   - Silkscreen readable (not over pads)
   - Drill holes aligned with pads
   - Layers aligned correctly

## Stage 6: Order from JLCPCB

### 6.1 Prepare Files

Create ZIP archive with:

- All Gerber files (.gbr)
- Drill file (.drl)
- BOM (CSV format, JLCPCB template)
- Pick-and-place file (CSV format)

```bash
# Example ZIP structure
gerbers.zip
├── F_Cu.gbr
├── B_Cu.gbr
├── F_Mask.gbr
├── B_Mask.gbr
├── F_Silkscreen.gbr
├── B_Silkscreen.gbr
├── Edge_Cuts.gbr
└── drill.drl

bom_jlcpcb.csv
cpl_jlcpcb.csv
```

### 6.2 Upload and Configure

1. Go to [jlcpcb.com](https://jlcpcb.com)
2. Upload gerbers.zip
3. Configure:
   - PCB quantity: 5 (minimum)
   - PCB thickness: 1.6mm (standard)
   - Surface finish: HASL (lead-free) or ENIG (better quality)
   - Copper weight: 1oz (standard for &lt;3A)
4. Add SMT assembly service (optional):
   - Upload BOM + CPL
   - Review component placement
   - Check part availability/substitutions

## Workflow Summary

```
1. Symbol Editor
   ↓
2. Schematic Editor → [ERC Pass] → Assign Footprints
   ↓
3. Update PCB from Schematic
   ↓
4. PCB Editor → Place Components → Route → [DRC Pass]
   ↓
5. Generate Outputs (Gerber, Drill, BOM, CPL)
   ↓
6. Verify in GerbView
   ↓
7. Order from JLCPCB
```

## Troubleshooting

### Common Issues

**Problem:** Symbol not found when placing component

- **Solution:** Add library containing the symbol (Preferences → Manage Symbol Libraries)

**Problem:** Footprint assignment shows "No Footprint"

- **Solution:** Add footprint library (Preferences → Manage Footprint Libraries)

**Problem:** DRC shows "unconnected nets"

- **Solution:** Check for missing wires in schematic, or use "No Connect" flags

**Problem:** Gerber viewer shows misaligned layers

- **Solution:** Check drill origin settings, regenerate Gerbers with correct settings

**Problem:** JLCPCB BOM upload fails

- **Solution:** Verify CSV format matches template, check for special characters

## Next Steps

After completing the KiCad workflow:

1. **Documentation:**
   - Export circuit diagram as SVG (see [Create Circuit SVG Files](./create-circuit-svg.md))
   - Export footprint previews (see [Create Footprint SVG Files](./create-footprint-svg.md))
   - Update parts list with LCSC IDs

2. **Testing plan:**
   - Order PCBs without assembly first
   - Verify board dimensions and mounting holes
   - Check component footprints with actual parts
   - Then order with assembly

3. **Version control:**
   - Commit KiCad project files (.kicad_pro, .kicad_sch, .kicad_pcb)
   - Commit Gerber outputs for reference
   - Tag release versions (v1.0, v1.1, etc.)

## References

- [KiCad Documentation](https://docs.kicad.org/)
- [KiCad Parts Download Guide](./kicad-parts-download.md)
- [JLCPCB SMT Assembly](https://jlcpcb.com/smt-assembly)
- [Create Footprint SVG Files](./create-footprint-svg.md)

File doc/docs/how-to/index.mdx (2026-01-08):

---
sidebar_position: 1
---

import CategoryNav from '@site/src/components/CategoryNav';

# How to use tools

Technical guides and workflow documentation for the USB-PD Power Supply project.

## Purpose

These guides document the workflows used to maintain and update this project's documentation. They ensure consistency and make it easy to add new components or update circuit diagrams.

## Pages in this category

<CategoryNav category="how-to" />

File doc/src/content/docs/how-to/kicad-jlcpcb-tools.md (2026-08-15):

---
title: Generate JLCPCB Files with kicad-jlcpcb-tools
sidebar_position: 6
---

This guide explains how to generate JLCPCB-ready manufacturing files (Gerbers, BOM, CPL) using the `kicad-jlcpcb-tools` KiCad plugin. The plugin replaces the manual export workflow and **automatically applies rotation corrections** that JLCPCB's part library requires.

## Why This Plugin

KiCad's footprint orientation does not always match the orientation in JLCPCB's internal part library. For many packages (QFN, SOT-23-5, SOT-23-6, SOIC, etc.) this mismatch causes the chip to be soldered with the wrong pin 1, killing the board.

PCBA v2 hit this exact issue: U1 (STUSB4500QTR, QFN-24) was placed at 180° in the CPL, but JLCPCB's library expected 270°. JLCPCB caught it during pre-production review, but only because the board has a small part count.

`kicad-jlcpcb-tools` ships with a community-maintained rotation database keyed by footprint name and applies the correction at CPL-generation time. The exported file matches what JLCPCB expects on the first try.

## Installation

The plugin is distributed via KiCad's built-in Plugin and Content Manager (PCM).

### Step 1: Open the Plugin and Content Manager

1. Launch the **KiCad** main app (`/Applications/KiCad/KiCad.app`).
2. On the launcher screen, click **Plugin and Content Manager**.
- Alternatively: menu **Tools → Plugin and Content Manager**.

### Step 2: Find the Plugin

1. Click the **Plugins** tab.
2. In the search box, type `JLCPCB`.
3. Locate **JLCPCB Tools** by **Bouni**.

### Step 3: Install

1. Click **Install** on that row.
2. Click **Apply Pending Changes** at the bottom right.
3. Wait for the download to finish.
4. Close PCM. **Restart KiCad** (close all KiCad windows and reopen).

### Manual Install (Fallback)

If the plugin is not listed in PCM (e.g., not yet updated for a new KiCad major version), install manually:

```bash
cd ~/Documents/KiCad/10.0/scripting/plugins
git clone https://github.com/Bouni/kicad-jlcpcb-tools.git
```

Restart PCB Editor afterward.

## First-Time Project Setup

Open `zudo-pd.kicad_pcb` in **PCB Editor**. After install you should see a new toolbar icon for **JLCPCB Tools** (red square logo). Click it to open the plugin panel.

The panel lists every component on the PCB with columns for designator, footprint, value, LCSC part number, stock, and rotation correction.

### Assign LCSC Part Numbers

For each component:

1. Select the row.
2. Click **Select part** (or double-click the LCSC column).
3. Search by LCSC number (e.g., `C2678061`) or by part description.
4. Confirm the selection.

The plugin writes the LCSC number into the schematic as a custom field, so this is a one-time job per part. Later runs reuse the saved number.

**For this project**, the LCSC numbers are already in the BOM at:

- `jlcpcb-order-snapshots/v0_4_0/used-for-order/BOM-zudo-pd.csv` (the last real order's BOM, committed to the repo — there is no `dist/` directory)
- See also the per-component pages under **Components** in this documentation site.

### Verify Rotation Corrections

The plugin shows a **Rotation** column. For each component, the plugin looks up the footprint name in its built-in rotation database and applies an offset.

- A non-zero rotation means a correction was applied automatically.
- Zero rotation means no correction was needed (or no entry exists for that footprint — confirm manually if the part is polarized).

If you find a missing or wrong correction, use the plugin's **Corrections Manager** to add or override entries — see [Gotcha: EasyEDA-Derived Footprints](#gotcha-easyeda-derived-footprints) below for a worked example.

> **Note**: corrections are stored in a single global SQLite file (`~/Documents/KiCad/<version>/3rdparty/plugins/com_github_bouni_kicad-jlcpcb-tools/jlcpcb/corrections.db`). Edits affect **every** KiCad project on this machine — there is no per-project rotation override in this plugin version. The "Use global corrections" checkbox in the Corrections Manager toggles whether the project uses these rules at all, not whether the rules are project-scoped.

## Generating JLCPCB Files

1. In the JLCPCB Tools panel, click **Generate**.
2. The plugin produces a `jlcpcb/` directory at the project root containing:

   ```
   jlcpcb/
   ├── gerber/                    ← Gerber files (one per layer)
   ├── production_files/
   │   ├── BOM-zudo-pd.csv        ← BOM with LCSC numbers
   │   └── POS-zudo-pd.csv        ← Pick-and-place / CPL with corrected rotations
   └── project.db                 ← Plugin local cache (SQLite)
   ```

3. Zip the contents of `jlcpcb/gerber/` for upload (JLCPCB expects a single `.zip` of Gerbers).
4. Upload to the JLCPCB order page:
- **Gerber**: the zip
- **BOM**: `production_files/BOM-zudo-pd.csv`
- **CPL**: `production_files/POS-zudo-pd.csv`

<Note>
The bare-copper footprints (pogo pads, test pads) carry footprint-level
`exclude_from_pos_files` / `exclude_from_bom` attributes so they never export as
phantom assembly rows. The v0.4.0 order snapshots are evidence the toolchain
honors these attributes: the `MountingHole` footprints carrying them appear in
neither the CPL nor the BOM snapshot, while the then-unexcluded J2/J3/TP* pads
shipped as exactly the phantom rows this guards against
(`jlcpcb-order-snapshots/v0_4_0/used-for-order/CPL-zudo-pd.csv`). At the first
Board A/B order, still confirm the exported `POS-*.csv` contains no
J2/J3/P1/TP* rows; if a phantom row does appear, delete it from the generated
CSV before upload and investigate the plugin's `project.db` cache. Note this
applies to future Board A/B layouts only — the legacy as-built board file
embeds its own frozen `(attr smd)` copies, and KiCad's "Update Footprints from
Library" does not reset fabrication attributes by default.
</Note>

> **Scope note:** `zudo-pd.kicad_pcb` is the legacy root project — the as-built v4
> board — so the worked example below (Q1/D4) reflects that board's fitted parts.
> Board A's schematic redesign removed D4 (USBLC6-2SC6) in favor of DNP
> PESD24VS1UB CC-line ESD diodes (D6/D7); see
> [Board A: USB-PD Core](../overview/board-a-usb-pd-core.md#deltas-vs-the-current-single-board-circuit).
> Board A/B have no PCB layout yet, so this plugin workflow does not apply to them
> until layout starts.

## Gotcha: EasyEDA-Derived Footprints

The plugin's default rotation rules target KiCad's **official** footprint libraries (`Package_TO_SOT_SMD`, `Package_QFP`, etc.). For projects that use footprints downloaded from LCSC/EasyEDA via tools like `easyeda2kicad.py`, several common rules **over-correct** the rotation and produce a CPL that would solder parts incorrectly.

### How to Recognize Affected Footprints

EasyEDA-derived footprints follow a naming pattern with a dimension descriptor and a pin-1 position suffix:

```
<package>_L<length>-W<width>-P<pitch>-LS<lead-span>-{BL|BR}
```

Examples used in this project:

- `SOT-23_L2.9-W1.3-P1.90-LS2.4-BR` (Q1 — AO3401A P-channel MOSFET)
- `SOT-23-6_L2.9-W1.6-P0.95-LS2.8-BL` (D4 — USBLC6-2SC6 ESD protection)
- `QFN-24_L4.0-W4.0-P0.50-BL-EP2.8` (U1 — STUSB4500QTR)

The `BL` / `BR` suffix encodes pin 1's position (Bottom-Left / Bottom-Right), confirming these footprints are already drawn in JLCPCB's pin-1 convention. They should **not** receive any further rotation correction.

### What the Plugin Does Wrong (Without Override)

The default plugin database contains the rule:

```
^SOT-23 → -90°
```

This regex matches everything that starts with `SOT-23`, including the EasyEDA-derived `SOT-23_L2.9-...-BR` and `SOT-23-6_L2.9-...-BL` footprints. The plugin then applies a **bogus** -90° correction, and the resulting CPL would tell JLCPCB to mount Q1 and D4 rotated 90° clockwise from their correct orientation.

JLCPCB's pre-production review may or may not catch this — they flagged U1 (QFN-24) on PCBA v2 but **did not flag** the SOT-23 / SOT-23-6 over-corrections. Don't rely on JLCPCB's review to catch this.

(For QFN-24 the plugin's `+270°` correction is **correct** — even though that footprint also has `BL` in its name. The QFN issue is unrelated to the SOT-23 over-correction. JLCPCB confirmed `270°` was right during the v2 review.)

### Fix: Add Specific Overrides

The plugin's matching logic does an "anchored" pass first (it appends `$` to each regex and tries to match against the end of the string). A more specific regex with `.*$` at the end will win over the generic `^SOT-23` rule before the unanchored fallback runs.

**Steps** (in PCB Editor with the JLCPCB Tools panel open):

1. Click the **Corrections Manager** toolbar button (or right-click any part row → "Add correction by package").
2. The dialog has an **Add / Edit** section at the top. Despite the absence of an explicit "Add" button, **clicking "Save" with a new regex creates a new row** (Save acts as upsert).
3. Add the first rule:
- **Regex**: `^SOT-23-6_L2\.9-W1\.6.*$`
- **Rotation**: `0`
- **Offset X / Y**: `0.00`
- Click **Save**.
4. Add the second rule:
- **Regex**: `^SOT-23_L2\.9-W1\.3.*$`
- **Rotation**: `0`
- Click **Save**.
5. Close the dialog. Click **Generate** in the main panel.

### Verifying the Fix

The plugin's log should now show:

```
... Fixed rotation of D4 (USBLC6-2SC6 / SOT-23-6_L2.9-W1.6-...) on Top Layer by 0 degrees
... Fixed rotation of Q1 (-30V -4A / SOT-23_L2.9-W1.3-...) on Top Layer by 0 degrees
... Fixed rotation of U1 (STUSB4500QTR / QFN-24_L4.0-W4.0-...) on Top Layer by 270 degrees
```

The `0 degrees` lines mean **your override matched and applied a no-op rotation**, blocking the generic `-90°` rule. U1's `+270°` is the QFN correction we want.

The resulting CPL should contain:

```
D4: rotation = 0    ← matches working v1/v2 orientation
Q1: rotation = 0    ← matches working v1/v2 orientation
U1: rotation = 90   ← = 270° in KiCad's convention (the value JLCPCB confirmed for v2)
```

### Why the Numbers Look Different from KiCad's Native CPL

The plugin's CPL uses JLCPCB's coordinate convention (Y-axis flipped vs. KiCad's), so rotation values do not match KiCad's native CPL export numerically — but they are equivalent physical orientations. Don't try to compare the plugin's CPL row-by-row to `jlcpcb-order-snapshots/v0_4_0/used-for-order/CPL-zudo-pd.csv`; verify physical correctness instead (pin 1 visual check on JLCPCB's pre-production rendering).

### Adding More Overrides as the Library Grows

Whenever you add a new EasyEDA-derived footprint to the project, check if its package family has an existing default rule in the Corrections Manager. If yes, add a more specific override (with the `_L\d` shape characteristic of EasyEDA naming) so the over-correction does not apply.

A general pattern that catches both SOT-23 variants in one rule (alternative to the two specific rules above):

```
^SOT-23(-[36])?_L\d
```

Apply the same approach to other package families if they hit the same problem (`^SOIC-`, `^SOP-`, `^TSOP-`, etc., all have default rules that may over-correct EasyEDA footprints).

## Repository Convention

The `/jlcpcb` directory is **gitignored**. Reasons:

- All output is regenerable from the `.kicad_pcb` and `.kicad_sch` (LCSC numbers live in schematic fields, not in `project.db`).
- `project.db` is binary and produces noisy diffs.
- Keeps the repository small.

If you want to retain a snapshot of a specific order, copy the relevant files into `/jlcpcb-order-snapshots/` (which is committed) following the existing folder convention there.

## Verifying Before Order

After generating, do a quick sanity check before uploading:

1. **Open `production_files/POS-zudo-pd.csv`** in a spreadsheet.
2. **Find polarized parts** (ICs, diodes, electrolytic caps, LEDs).
3. **Cross-reference rotation values** against the previous successful order in `jlcpcb-order-snapshots/v0_4_0/used-for-order/CPL-zudo-pd.csv` if applicable.
4. **For new ICs that were not on the previous order**, manually verify pin 1 in the JLCPCB part library page (e.g., search for the LCSC number on jlcpcb.com and inspect their footprint rendering).

This avoids the back-and-forth seen on PCBA v2 where JLCPCB had to flag U1 mid-order.

## Troubleshooting

### Plugin Toolbar Icon Missing After Install

- Confirm KiCad was fully restarted (all windows closed).
- Re-open PCB Editor (the icon only appears there, not in Schematic Editor).
- If still missing, check **PCB Editor → Tools → External Plugins** for the entry.

### "Footprint not in rotation database"

- The plugin will warn for unknown footprints. Manually verify rotation against the JLCPCB part library page.
- Add the footprint and correction to the plugin's rotation database for next time.

### Wrong Rotation Applied (Plugin Over-Corrects)

If the generated CPL has a rotation that disagrees with a previously-working order, the plugin's default regex may be matching an EasyEDA-derived footprint and over-correcting it. See [Gotcha: EasyEDA-Derived Footprints](#gotcha-easyeda-derived-footprints).

### LCSC Search Returns No Results

- Confirm internet connectivity (the plugin queries JLCPCB's API).
- Some discontinued parts no longer appear; check the LCSC number directly at `https://jlcpcb.com/parts`.

## References

- Plugin repository: [`Bouni/kicad-jlcpcb-tools`](https://github.com/Bouni/kicad-jlcpcb-tools)
- Related: [KiCad Project Workflow](./kicad-workflow.md)
- Related: [Download KiCad Footprints and Symbols](./kicad-parts-download.md)

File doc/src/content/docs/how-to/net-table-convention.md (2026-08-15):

---
title: Net-Table + Mermaid Convention
sidebar_position: 50
description: How to document circuit connectivity using net tables derived from the KiCad netlist and Mermaid block diagrams.
---

## Overview

This page explains the repo convention for documenting circuit connectivity.
The preferred AI→human handoff artifact is a **net-connectivity table** (derived
from the KiCad netlist) paired with a **Mermaid block diagram** for stage-level
topology.

**Why not ASCII art?** LLMs are unreliable at 2-D spatial layout — a slight
misalignment makes a diagram misleading. Net tables are geometry-free (no 2-D
representation), generated from the authoritative netlist, and trivially
verifiable. Mermaid renders as a proper block diagram in the doc site. ASCII art
may still be used as an optional human-readable illustration, but it is not the
authoritative connectivity record.

## Net-Table Schema

One sub-table per hierarchical sheet. The three columns are:

| Net | Connected pins (Ref.Pin) | Value/Note |
|-----|---|---|

- **Net** — the KiCad net name exactly as it appears in the exported netlist
  (e.g. `+15V`, `-13.5V`, `GND`, `Net-(U6-OUT)`). Cross-sheet nets keep their
  full path prefix (e.g. `/DC-DC Conversion/+13.5V OUT`).
- **Connected pins (Ref.Pin)** — space-separated list of `Ref.Pin` tokens for
  all pins on that net that belong to the sheet being documented (e.g.
  `U8.2 C16.1 C24.2`). Pins from other sheets may be omitted or listed as
  `<sheet>/Ref.Pin`.
- **Value/Note** — component value, net role, or signal description (e.g.
  `LDO input rail`, `470 µF bulk cap`, `+12V LDO output before polyfuse`).

## Generating the Table

**For `boards/board-a` and `boards/board-b`**, skip the netlist export entirely —
the net table is read directly off the spec module's `NETS` dict
(`scripts/schgen/board_a_spec.py` / `board_b_spec.py`), which **is** the source
of truth the `.kicad_sch` file is generated from. No KiCad install needed.

**For the legacy root project** (`zudo-pd.kicad_sch`), there is no spec module,
so derive the table from the **KiCad netlist** — never by eyeballing symbol
positions in the GUI. Export with (assumes `kicad-cli` is on `PATH`; on macOS
where KiCad wasn't added to `PATH` during install, the binary lives at
`/Applications/KiCad/KiCad.app/Contents/MacOS/kicad-cli`):

```sh
kicad-cli sch export netlist \
  --format kicadxml \
  --output __inbox/<sheet-name>-netlist.xml \
  zudo-pd.kicad_sch
```

The root schematic `zudo-pd.kicad_sch` contains all hierarchical sheets; one
export covers everything. Keep the raw XML in `__inbox/` (gitignored). Parse it
with Python's `xml.etree.ElementTree` — every `<net>` element lists `<node
ref="..." pin="..." />` children that map directly to the `Ref.Pin` column.

## Mermaid Block Diagram

Pair every net table with a `flowchart TD` that shows the stage-level signal
flow. Use one node per functional block; label edges with net names or voltage
levels:

```mermaid
flowchart TD
  IN["+15V USB-PD input"] -->|"+15V"| DCDC1["DC-DC +13.5V"]
  IN -->|"+15V"| DCDC2["DC-DC +7.5V"]
  IN -->|"+15V"| DCDC3["DC-DC (inverting buck-boost) -13.5V"]
  DCDC1 -->|"+13.5V"| U6["U6 L7812\n+12V LDO"]
  DCDC2 -->|"+7.5V"| U7["U7 L7805\n+5V LDO"]
  DCDC3 -->|"-13.5V"| U8["U8 CJ7912\n-12V LDO"]
```

Keep the diagram at the **block level** — one node per functional stage, not
one node per component. Component-level detail lives in the net table.

## Worked Example: Board B — LDO + Protection Stage

Board B (`boards/board-b/board-b.kicad_sch`, generated from
`scripts/schgen/board_b_spec.py`) is a flat (non-hierarchical) schematic, so
there is one net table for the whole board. This example is a filtered slice
covering the LDO stage (U6 L7812CD2T +12V, U7 L7805ABD2T +5V, U8 CJ7912 −12V),
its bypass capacitors, indicator LEDs, polyfuse protection (PTC1–3), and TVS
clamping diodes (TVS1–3).

The table and diagram below are read directly off `board_b_spec.py`'s `NETS`
dict — no KiCad netlist export needed, per the "Generating the Table" section
above.

### Block Diagram

```mermaid
flowchart TD
  IN13V5["+13.5V IN\n(from DC-DC stage)"] -->|"/DC-DC Conversion/+13.5V OUT"\nC14.1 C20.1| U6["U6 L7812CD2T\n+12V LDO"]
  IN7V5["+7.5V IN\n(from DC-DC stage)"] -->|"/DC-DC Conversion/+7.5V OUT"\nC15.1 C22.1| U7["U7 L7805ABD2T\n+5V LDO"]
  IN13V5N["-13.5V IN\n(from DC-DC stage)"] -->|"/DC-DC Conversion/-13.5V OUT"\nC16.1 C24.2 C12.2| U8["U8 CJ7912\n-12V LDO"]

  U6 -->|"Net-(U6-OUT)"| PTC1["PTC1 polyfuse\n1.5A hold / SMD1210P150TF/16"]
  U7 -->|"Net-(U7-OUT)"| PTC2["PTC2 polyfuse\n1.1A hold / mSMD110-33V"]
  U8 -->|"Net-(U8-OUT)"| PTC3["PTC3 polyfuse\n1.5A hold / BSMD1206-150-16V"]

  PTC1 -->|"+12V rail"| OUT12["+12V output"]
  PTC2 -->|"+5V rail"| OUT5["+5V output"]
  PTC3 -->|"-12V rail"| OUT12N["-12V output"]

  TVS1["TVS1 SMAJ15A\n+12V clamp"] --- OUT12
  TVS2["TVS2 SMAJ6.5A\n+5V clamp"] --- OUT5
  TVS3["TVS3 SMAJ15A\n-12V clamp\n(reversed: cathode->GND)"] --- OUT12N

  U6 --- LED2["LED2 Green\n+12V indicator\n(via R7 1k)"]
  U7 --- LED3["LED3 Blue\n+5V indicator\n(via R8 1k)"]
  U8 --- LED4["LED4 Red\n-12V indicator\n(via R9 1k)"]

  GND(["GND"])
  U6 --- GND
  U7 --- GND
  U8 --- GND
  TVS1 --- GND
  TVS2 --- GND
  TVS3 --- GND
  LED2 --- GND
  LED3 --- GND
  LED4 --- GND
```

### Net Table — Board B LDO + Protection Stage

| Net | Connected pins (Ref.Pin) | Value/Note |
|-----|---|---|
| `/DC-DC Conversion/+13.5V OUT` | `U6.1 C14.1 C20.1` (also carries DC-DC-stage pins `L1.2 R1.2 C3.1 C31.2` and test pad `TP3.1`, omitted here) | LDO input for +12V rail; `U6.1` = IN pin; `C14.1`/`C20.1` = 470 µF/35V input bulk caps |
| `/DC-DC Conversion/+7.5V OUT` | `U7.1 C15.1 C22.1` (also `L2.2 R3.1 C4.1 C32.2`, `TP4.1`, omitted here) | LDO input for +5V rail; `U7.1` = IN pin; `C15.1` = 470 nF, `C22.1` = 470 µF/10V |
| `/DC-DC Conversion/-13.5V OUT` | `U8.2 C16.1 C24.2 C12.2` (also `U4.3 U4.5 U4.6 D3.2 C9.2 C10.2 C11.2 R6.2`, `TP5.1`, omitted here) | LDO input for -12V rail; `U8.2` = VIN pin; `C16.1` = 470 nF, `C24.2`/`C12.2` = 470 µF/35V output bank (C12 added by decision `neg-rail-cap-bank`) |
| `Net-(U6-OUT)` | `U6.3 C17.2 C21.1 R7.1 PTC1.1` | +12V LDO output before polyfuse; `C17.2` = 100 nF output bypass, `C21.1` = 470 µF/35V, `R7.1` = LED resistor |
| `Net-(U7-OUT)` | `U7.3 C18.1 C23.1 R8.1 PTC2.1` | +5V LDO output before polyfuse; `C18.1` = 100 nF output bypass, `C23.1` = 470 µF/10V |
| `Net-(U8-OUT)` | `U8.3 C19.1 C25.2 R9.1 PTC3.1` | -12V LDO output before polyfuse; `C19.1` = 100 nF output bypass, `C25.2` = 470 µF/35V |
| `+12V rail` | `PTC1.2 TVS1.1` (also output connectors `J7.1 J7.2 J10.7 J10.8 J11.7 J11.8`, omitted here) | Protected +12V output; `PTC1.2` = polyfuse output, `TVS1.1` = TVS cathode clamp |
| `+5V rail` | `PTC2.2 TVS2.1` (also `J8.1 J8.2 J10.5 J10.6 J11.5 J11.6`, omitted here) | Protected +5V output; `PTC2.2` = polyfuse output, `TVS2.1` = TVS cathode clamp |
| `-12V rail` | `PTC3.2 TVS3.2` (also `J6.1 J6.2 J10.15 J10.16 J11.15 J11.16`, omitted here) | Protected -12V output; `PTC3.2` = polyfuse output, `TVS3.2` = TVS **anode** — TVS3's orientation is reversed vs. TVS1/TVS2 (locked by decision `tvs3-orientation`) |
| `Net-(R7-LED2)` | `R7.2 LED2.1` | +12V indicator LED anode node; `R7.2` = resistor output, `LED2.1` = LED anode (LED2 uses reversed pin numbering: pin 1 = A) |
| `Net-(R8-LED3)` | `R8.2 LED3.2` | +5V indicator LED anode node; `LED3.2` = LED anode |
| `Net-(R9-LED4)` | `R9.2 LED4.1` | -12V indicator LED cathode node; `LED4.1` = LED cathode (LED4 conducts from GND into the -12V network) |
| `GND` (filtered to this stage) | `U6.4 U7.2 U8.1 C14.2 C15.2 C17.1 C18.2 C20.2 C21.2 C22.2 C23.2 C16.2 C24.1 C19.2 C25.1 C12.1 LED2.2 LED3.1 LED4.2 TVS1.2 TVS2.2 TVS3.1` | Common ground; LDO GND pins, all bulk/bypass cap negatives, LED cathodes/anodes, TVS return pins. `GND` is shared board-wide — this row omits DC-DC-stage, interface, and output-connector GND pins also on the net |

<Note>
Pin numbers follow the spec module's `COMPONENTS`/`NETS` tables, which match the
symbol pin numbers `gen_schematic.py` emits into the schematic — not necessarily
the physical package pin numbers. For example, `U6.1` is symbol pin 1 of U6
(L7812CD2T, TO-263-2 package), which is the IN pin.
</Note>

## Reference

- Root `CLAUDE.md` § Schematic Documentation Conventions — the convention spec.
- `doc/CLAUDE.md` § Circuit Diagram Writing Rules — authoring guidance for docs.
- `scripts/schgen/board_b_spec.py` — the source-of-truth spec module the table
  above was read from (see its `NETS` dict).

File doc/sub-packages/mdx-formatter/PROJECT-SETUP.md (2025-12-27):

# MDX Formatter Setup for USB-PD Synth Power

このプロジェクト用にカスタマイズされたMDXフォーマッターのセットアップガイド。

## インストール済み

このプロジェクトには以下が既に設定されています:

- ✅ MDX Formatter (`/doc/sub-packages/mdx-formatter/`)
- ✅ Husky (Git hooks管理)
- ✅ lint-staged (ステージングされたファイルの自動フォーマット)
- ✅ pre-commit hook (コミット時の自動フォーマット)

## Git Hooks の有効化

初回セットアップ時、またはリポジトリをクローンした後に以下を実行:

```bash
# リポジトリルートで実行
git config core.hooksPath .husky
```

これにより、`.husky/pre-commit` フックが有効になります。

## フォーマッターの使い方

### 自動フォーマット (推奨)

Git commitを実行すると、自動的にステージングされた`.md`/`.mdx`ファイルがフォーマットされます:

```bash
git add docs/inbox/my-document.md
git commit -m "ドキュメントを追加"
# → 自動的にフォーマットされてコミットされます
```

### 手動フォーマット

#### 単一ファイル

```bash
cd doc
node sub-packages/mdx-formatter/src/cli.js --write docs/inbox/index.md
```

#### 全ドキュメント

```bash
cd doc
node sub-packages/mdx-formatter/src/cli.js --write "docs/**/*.{md,mdx}"
```

#### フォーマットチェック（書き込みなし）

```bash
cd doc
node sub-packages/mdx-formatter/src/cli.js --check "docs/**/*.{md,mdx}"
```

## フォーマットルール

### 見出し

- ATX形式 (`#`) を使用
- 見出しの後に空行を挿入

```markdown
## 見出し

本文が続きます...
```

### リスト

- 順序なしリストは `-` を使用
- 順序付きリストは `.` を使用
- 最小インデント（2スペース）

### コードブロック

- フェンスコードブロック (\`\`\`) を使用
- 言語識別子を保持
- コード内容は変更しない

### テーブル

- GFMテーブルを整列
- パイプの周りにスペースを追加

### 日本語テキスト

- 日本語の括弧 `（URL）` をmarkdownリンクに変換
- 日本語句読点の間隔を保持
- `、。！？` の周りに余分なスペースを入れない

### MDX/JSX

- JSXコンポーネントを適切なインデントで保持
- import/export文を維持
- 自己閉じタグはそのまま保持

## トラブルシューティング

### Git hookが動かない

```bash
# フックのパスを確認
git config --get core.hooksPath
# → .husky が表示されるはず

# 表示されない場合、設定する
git config core.hooksPath .husky
```

### フォーマッターがエラーを出す

```bash
# フォーマッターの依存関係を再インストール
cd doc/sub-packages/mdx-formatter
npm install
```

### pre-commit hookを一時的にスキップ

```bash
# --no-verifyオプションを使用（推奨しません）
git commit --no-verify -m "メッセージ"
```

## 開発

### フォーマッターのテスト

```bash
cd doc/sub-packages/mdx-formatter
npm test
```

### カバレッジレポート

```bash
cd doc/sub-packages/mdx-formatter
npm run test:coverage
```

## ディレクトリ構造

```
doc/
├── sub-packages/
│   └── mdx-formatter/          # MDXフォーマッター本体
│       ├── src/
│       │   ├── cli.js          # CLIエントリーポイント
│       │   ├── index.js        # APIエントリーポイント
│       │   └── plugins/        # カスタムプラグイン
│       ├── test/               # テストファイル
│       └── package.json
├── docs/                       # ドキュメントファイル
├── package.json                # lint-staged設定を含む
└── .husky/
    └── pre-commit              # Pre-commit hook (doc用)

/.husky/
└── pre-commit                  # Pre-commit hook (ルート)
```

## 参考リンク

- [remark](https://github.com/remarkjs/remark) - Markdownプロセッサー
- [unified](https://unifiedjs.com/) - AST処理フレームワーク
- [Husky](https://typicode.github.io/husky/) - Git hooks管理
- [lint-staged](https://github.com/okonet/lint-staged) - ステージングファイルのlint

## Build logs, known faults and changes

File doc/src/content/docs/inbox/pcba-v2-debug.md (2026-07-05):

---
title: PCBA v2 Debug Report — STUSB4500 CC1DB Failure
sidebar_position: 7
---

<Note title="Superseded by the 2-board split / v4 diagnosis (2026-07)">

The "v3 design fix" documented on this page — external 5.1 kΩ Rd on CC1/CC2 plus
CC1DB/CC2DB grounded (disabling dead-battery mode) — is the topology reversed by
[decision A1](./board-split-decision.md) in the Board Split Decision. The
[v4 USB-PD Failure Diagnosis](./v4-pd-failure-diagnosis.md) found this topology puts the
CC line **out of the USB Type-C sink Rd spec the moment the chip powers up** (external Rd
∥ the STUSB4500's own non-disableable internal Rd ≈ 2.55 kΩ, below the 5.1 kΩ ±20%
window) — a design defect on every board, independent of whether any chip's CC1DB pin
was ever actually shorted. Board A restores `CC1DB↔CC1` / `CC2DB↔CC2` (ST's reference
dead-battery wiring) with the external Rd DNP'd. This page's diagnostic sequence and
root-cause analysis for the specific v2 chip-internal-short symptom remain useful
historical record; its *design recommendation* (the v3 fix) is superseded.

</Note>

Debug analysis of the second PCBA prototype (v2) for the USB-PD modular synthesizer power supply. The STUSB4500 was successfully programmed via NVM, but the chip's **CC1DB pin is internally shorted to GND on every assembled board**, preventing USB-C source detection and blocking PD negotiation entirely. This page documents the failure mode, diagnostic sequence, root cause analysis, and the v3 design fix.

## Symptoms

After PCBA v2 was assembled by JLCPCB and the STUSB4500 NVM was successfully programmed:

| Observation | Detail |
| --- | --- |
| Charger plugged in | **0V on USB-C VBUS pin at the connector itself** |
| STUSB4500 detected on I2C | ✅ Yes — chip responds at address 0x28, NVM read/write works |
| NVM written with target PDOs | ✅ Yes — `SNK_PDO_NUMB = 2`, PDO2 = 15V/3A confirmed via read-back |
| GUI "Dashboard" tab | **"No device attached"** — chip sees nothing on its CC pins |
| Multimeter at D4 (ESD diode) | **CC1 net = 0 Ω to GND** (shorted), CC2 net = 5.1 kΩ to GND (correct) |
| Both PCBAs (2 boards from same JLCPCB order) | **Identical fault** |

## Root Cause

**The STUSB4500's CC1DB pin (pin 1) is internally shorted to GND.**

CC1DB provides "dead battery mode" termination — a passive 5.1 kΩ Rd pulldown that the USB-C source detects in order to apply VBUS. Since CC1DB is internally shorted to 0 Ω instead of presenting 5.1 kΩ Rd, the source sees an invalid CC termination and refuses to enable VBUS.

The v2 schematic correctly ties **CC1DB → CC1 net** (the standard ST-recommended dead-battery wiring). With the chip's internal short, this wiring drags the entire CC1 net to GND.

## Diagnostic Sequence That Isolated the Fault

### Step 1: GUI Dashboard ruled out NVM and software

The STSW-STUSB002 GUI's Dashboard tab showed **"No device attached"** even with a USB-C cable plugged into a working PD charger. NVM-level settings cannot influence the chip's hardware CC detection — this proved the issue was at the physical CC pin level, not software.

### Step 2: Multimeter measurements at D4 (USBLC6-2SC6)

D4 sits between the USB-C connector and the STUSB4500 on both CC lines. With board unpowered:

| Probe | Reading | Conclusion |
| --- | --- | --- |
| D4 pin 1 (J1-CC1 side) to GND | **0 Ω** | CC1 net shorted to GND |
| D4 pin 6 (U1-CC1 side) to GND | **0 Ω** | Confirms short propagates through diode (D4 passes signal correctly) |
| D4 pin 3 (J1-CC2 side) to GND | **5.1 kΩ** | CC2 net correctly terminated |
| D4 pin 4 (U1-CC2 side) to GND | **5.1 kΩ** | CC2 chip-internal Rd works |
| D4 pin 1 to D4 pin 6 (across diode) | **0 Ω** | Diode passes signal — D4 is healthy |

The asymmetry (CC1 shorted, CC2 fine) ruled out a generic short and pointed to a chip-side issue at pin 1 (CC1DB).

### Step 3: Hot-air removal of U1 isolated the source

To definitively localize the short to the chip or the PCB:

1. Applied flux + hot air to U1 (STUSB4500), removed the chip
2. With chip off, measured pad 1 (CC1DB position on the empty footprint) to GND: **OPEN circuit**
3. PCB pads were visually clean — no solder bridges remained under the chip area

**Conclusion**: the chip was the source of the short. The PCB itself has no design or assembly defect on the CC1 net.

### Step 4: Both PCBAs show identical fault

Two boards from the same JLCPCB order exhibited the exact same CC1DB short with the exact same chip placement orientation. This rules out:

- ❌ Random ESD damage (would affect chips randomly)
- ❌ Single-chip manufacturing defect
- ❌ Initial 20V overvoltage during testing (the second board was always programmed with a 5V-only charger first — confirmed by sequence of operations)

## What We Ruled Out Through Investigation

| Hypothesis | Status | How |
| --- | --- | --- |
| Wrong USB-C cable | Ruled out | Multiple cables tested |
| Wrong charger | Ruled out | Multiple chargers (all with 15V/3A support) tested |
| Chip damaged from initial 20V exposure | Ruled out | Second PCBA never saw 20V — same fault |
| Schematic error | Ruled out | Wiring matches SparkFun reference + ST datasheet typical app |
| USB-C connector footprint wrong | Ruled out | 6-pin SMD USB-C correctly maps B5 to CC2 internally |
| D4 (USBLC6) ESD diode dead | Ruled out | 0 Ω across pin 1↔6 confirms diode passes |
| CC1 trace touching GND on PCB | Ruled out | DRC clean on all layers; net visually clean in KiCad layout |
| STUSB4500 chip rotation wrong | Ruled out | I2C works on pins 7/8 → pin numbering is mapped correctly |
| NVM corruption | Ruled out | NVM read/write works; Dashboard says "No device attached" which is hardware-level |
| Footprint pad mapping wrong in PCB | Ruled out | PCB net assignments confirmed (pin 1 → Net-(U1-CC1), pin 6 → GND, etc.) |
| Counterfeit chip | Likely but unconfirmed | Both chips from same LCSC batch (C2678061) |

## Why v2 Design Is Vulnerable

The v2 schematic ties **CC1DB ↔ CC1** and **CC2DB ↔ CC2** — the standard ST-recommended dead-battery mode wiring used by:

- **SparkFun Power Delivery Board** ([schematic](https://cdn.sparkfun.com/assets/9/2/6/8/6/SparkFun_PowerDeliveryBoardSchematic.pdf))
- **ST STEVAL-ISC005V1** evaluation board
- **STUSB4500 datasheet "typical application" (Figure 10)**

This design relies **entirely on the chip's internal Rd** for CC termination. There's no external fallback. If any chip ships with internally-damaged CC1DB or CC2DB pins, **the entire board is bricked** with no rework option short of chip replacement.

## ST Datasheet Reference

Per the STUSB4500 datasheet (DS12499 Rev 5), pin description for CC1DB / CC2DB (page 4, Table 1):

> Pin 1 CC1DB: "Dead battery enable on CC1 pin" — Typical connection: **"To CC1 pin if used or ground"**
>
> Pin 5 CC2DB: "Dead battery enable on CC2 pin" — Typical connection: **"To CC2 pin if used or ground"**

And from §2.2.2 (page 5):

> "CC1DB and CC2DB are used for dead battery mode. This mode is enabled by connecting CC1DB and CC2DB respectively to CC1 and CC2. Thanks to this connection, the pull-down terminations on the CC pins are present by default even if the device is not supplied."
>
> ⚠️ **Warning: "CC1DB and CC2DB must be connected to ground when dead battery mode is not supported."**

**Both wiring options — "to CC1/CC2" (dead-battery) and "to ground" (no dead-battery) — are explicitly ST-supported.** The v3 fix uses the second option.

## v3 Design Fix

### Topology change

```
v2 (vulnerable):                          v3 (robust):

USB-C CC1 ─┬─ D4 ─ STUSB4500 pin 2 (CC1)  USB-C CC1 ─┬─ D4 ─ STUSB4500 pin 2 (CC1)
           │                                          │
           └─────── STUSB4500 pin 1 (CC1DB)           R_CC1 (5.1 kΩ)   ← NEW
                                                      │
                                                     GND

                                          STUSB4500 pin 1 (CC1DB) ─── GND   ← CHANGED

(symmetric for CC2)                       (symmetric for CC2)
```

### Schematic changes

| Change | Detail |
| --- | --- |
| **Add R_CC1 = 5.1 kΩ (0603, 1%)** | From CC1 net (USB-C connector side) to GND |
| **Add R_CC2 = 5.1 kΩ (0603, 1%)** | From CC2 net (USB-C connector side) to GND |
| **Disconnect U1 pin 1 (CC1DB) from CC1 net** | Tie pin 1 directly to GND |
| **Disconnect U1 pin 5 (CC2DB) from CC2 net** | Tie pin 5 directly to GND |

### Why 5.1 kΩ (and not 10 kΩ)?

5.1 kΩ is the **USB-C spec Rd value** (±20%, valid range 4.08–6.12 kΩ). Every USB-C sink uses this.

An earlier draft of this fix proposed 10 kΩ as a hedge in case a future chip batch ships with working internal Rd (so external + internal in parallel wouldn't drop too far below spec). That reasoning was rejected:

| Scenario | Effective Rd | USB-C spec window: 4.08–6.12 kΩ |
| --- | --- | --- |
| Broken chip (current batch, CC1DB → GND, internal Rd dead) + ext 5.1 kΩ | **5.1 kΩ** | ✅ In spec |
| Broken chip + ext 10 kΩ | **10 kΩ** | ⚠️ Above spec — marginal on strict sources |
| Good chip (hypothetical, internal Rd works) + ext 5.1 kΩ | **2.55 kΩ** | ❌ Below spec |
| Good chip + ext 10 kΩ | **3.4 kΩ** | ❌ Below spec |

**10 kΩ is out of spec in every scenario.** 5.1 kΩ is in spec for our actual reality (broken chips, external Rd carries the load alone).

The "good chip" parallel-resistance failure mode is **not** solved by picking a compromise external value — the proper fix is to **remove the external Rd entirely** (board respin, or a populate/DNP jumper) once you know the chip's internal Rd is healthy. So for v3 we use the spec value and don't try to compromise across two failure scenarios.

**Sensitivity on 3 A USB-C sources:** sources advertising 3 A use Rp = 22 kΩ (tightest detection). The CC line voltage with Rp pull-up:

- 5.1 kΩ Rd → 5 V × 5.1 / (5.1 + 22) ≈ **0.94 V** — comfortably below the ~1.7 V "sink connected" threshold
- 10 kΩ Rd → 5 V × 10 / (10 + 22) ≈ **1.56 V** — borderline; some compliant sources will fail to detect

### Why disconnect CC1DB / CC2DB from CC1 / CC2?

**This is the critical change.** If CC1DB stays on the CC1 net (v2 wiring), then a chip with internally-shorted CC1DB still drags the entire CC1 net to 0 Ω, and the external 5.1 kΩ is overpowered (a 0 Ω short wins against any finite resistor). The fault persists.

By routing CC1DB and CC2DB to GND directly:

- The broken pin's internal short is isolated to the GND net (harmless)
- The CC1 / CC2 nets see only the external R_CC1 / R_CC2 and the chip's main CC pins (pin 2, pin 4) for termination

### What we give up: Dead-battery mode

In v3, the chip cannot present passive Rd before being powered. The chicken-and-egg is solved by the external R_CC1 / R_CC2 — these are always present and always provide valid Rd, so the source detects the sink, applies 5V VBUS, which powers the chip via VDD, which then takes over CC handling actively.

Dead-battery mode is only needed when the chip is being powered from a separate depleted battery and needs to advertise itself before that battery recovers. **For VBUS-only powered designs like zudo-pd, dead-battery mode provides no benefit and creates the single-point-of-failure we hit.**

## Additional v3 Improvements (Recommended)

### EPAD F.Paste aperture (footprint fix)

The current QFN-24 footprint defines pad 25 (the EPAD) with a single solid 2.8 × 2.8 mm F.Paste aperture. Standard QFN best practice is to **window the EPAD paste** into a grid of smaller apertures (e.g., 4×4 sub-squares of ~0.5 × 0.5 mm each, ~50-60% area coverage). This:

- Controls solder paste volume on the EPAD
- Prevents excess solder from squeezing out at the EPAD corners during reflow
- Reduces risk of solder bridging to corner pins (CC1DB is at one corner, RESET at the opposite corner)
- Is JLCPCB-recommended for thermal pad SMT assembly

### EPAD GND vias (footprint fix)

The current EPAD has 16 GND vias in a 4×4 grid. Standard QFN recommendation is **4–9 vias** for thermal/electrical GND connection. Excessive vias can wick solder away from the joint during reflow, contributing to solder migration and uneven joint quality.

**Recommendation**: Reduce to a 3×3 grid (9 vias) or 5 vias (4 corners + center). Use solder-mask plug on via-in-pad to prevent paste loss.

### External Rd resistor placement

Place R_CC1 and R_CC2 **physically close to the USB-C connector**, before D4. This ensures the source's first measurement (at first cable plug) sees the external Rd directly, even if D4 or downstream traces have issues.

## v3 Schematic Fix Checklist

- [x] Add R17 = R_CC1 (5.1 kΩ, 0603, 1%, C23186) from USB-C CC1 to GND
- [x] Add R18 = R_CC2 (5.1 kΩ, 0603, 1%, C23186) from USB-C CC2 to GND
- [x] Disconnect U1 pin 1 (CC1DB) from CC1 net; tie to GND via **R19 (0 Ω, 0603, C21189)** — uses a 0 Ω jumper instead of a direct GND tie so the chip-side net keeps the name `CC1DB`. That preserves a uniquely-named test point on the J3 pogo block (pin 1) for verifying chip-pin continuity, and lets us lift R19 for chip-isolation measurement during future debug
- [x] Disconnect U1 pin 5 (CC2DB) from CC2 net; tie to GND via **R20 (0 Ω, 0603, C21189)** — same rationale, J3 pogo pin 2
- [ ] Update QFN-24 footprint: window the EPAD F.Paste into a 4×4 grid of 0.5 mm² apertures
- [ ] Update QFN-24 footprint: reduce EPAD GND vias from 16 to 9 (or 5)
- [ ] Add via tenting / mask-plug on EPAD via-in-pad
- [ ] Run DRC and ERC
- [ ] Bench test on first v3 board: cold-plug a USB-C source, confirm VBUS appears (proves external Rd bootstrap works)

## Reference Designs Compared

| Design | CC1DB wiring | External Rd on CC | Notes |
| --- | --- | --- | --- |
| **zudo-pd v2** (current) | CC1DB ↔ CC1 (dead-battery) | None | ❌ Fails when chip ships with CC1DB internally shorted |
| **SparkFun Power Delivery Board** | CC1DB ↔ CC1 (dead-battery) | None | Standard ST design; works when chips are good |
| **ST STEVAL-ISC005V1** | CC1DB ↔ CC1 (dead-battery) | None | ST's own eval design; works with controlled chip sourcing |
| **STUSB4500 datasheet Fig. 10** | CC1DB ↔ CC1 (dead-battery) | None | "Typical application" — same vulnerability |
| **Instructables DIY Hotplate** | CC1DB ↔ CC1 (dead-battery) | R3 = 10 kΩ on CC1 only | Confirmed working JLCPCB build; asymmetric ext Rd |
| **zudo-pd v3** | CC1DB → GND via R19 (0 Ω), CC2DB → GND via R20 (0 Ω) | **5.1 kΩ on both CC1 and CC2** (R17/R18) | Defensive against chip-side failures; USB-C spec Rd value; symmetric. 0 Ω jumper preserves named `CC1DB`/`CC2DB` nets for J3 pogo testing and chip-isolation rework |

## References

- [STUSB4500 Datasheet DS12499 Rev 5](https://www.st.com/resource/en/datasheet/stusb4500.pdf) — pages 4, 5, 14, 23, 25, 26 referenced
- [STUSB4500L Datasheet](https://www.st.com/resource/en/datasheet/stusb4500l.pdf) — variant with similar CC pin scheme
- [STEVAL-ISC005V1 Schematic Pack](https://www.st.com/resource/en/schematic_pack/steval-isc005v1_schematic.pdf) — ST eval board reference
- [STEVAL-ISC005V1 User Manual UM2547](https://www.st.com/resource/en/user_manual/dm00493783-getting-started-with-the-stevalisc005v1-evaluation-board-for-stusb4500-stmicroelectronics.pdf)
- [SparkFun Power Delivery Board Schematic (PDF)](https://cdn.sparkfun.com/assets/9/2/6/8/6/SparkFun_PowerDeliveryBoardSchematic.pdf)
- [SparkFun Power Delivery Board product page](https://www.sparkfun.com/products/15801)
- [DIY Smart Hotplate (Instructables)](https://www.instructables.com/DIY-Smart-Hotplate-Powered-by-STM32-USB-C-Power-De/) — working JLCPCB design with 10 kΩ external Rd on CC1
- [GitHub: usb-c/STUSB4500](https://github.com/usb-c/STUSB4500) — official ST reference code
- [USB Type-C 2.0 Specification](https://www.usb.org/document-library/usb-type-cr-cable-and-connector-specification-release-22) — Rd termination requirements (§4.11.2)
- [PCBA v1 Debug Report](/docs/inbox/pcba-v1-debug) — v1 issues (different failure mode: pin 18 and pin 22 wiring)
- [NVM Programming Setup](/docs/inbox/nvm-programming) — how to program the chip via STSW-STUSB002 GUI

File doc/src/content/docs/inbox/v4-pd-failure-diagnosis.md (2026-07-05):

---
title: v4 USB-PD Failure Diagnosis (front-end datasheet review)
sidebar_position: 12
description: Ranked root-cause candidates for the v4 (0.4.0) PD failure, verified against the real netlist and the ST datasheets, plus a bench discrimination procedure for the dead v4 boards.
---

The v4 (0.4.0) board still fails USB-PD even though the v3 pin-18 bug is fixed and the
NVM is programmed for 15 V. This page ranks root-cause candidates for the v4 failure
from a datasheet-aware review of the USB-PD front end (`usb-pd-input.kicad_sch`), and
gives a bench procedure that discriminates between the candidates on the dead v4 boards.

**Method.** Every connectivity claim below was generated from the real KiCad netlist
(`kicad-cli sch export netlist --format kicadxml`, exported 2026-07-05 from this repo),
never from symbol screen positions. Datasheet claims cite ST DS12499 Rev 4 (STUSB4500)
and the ST USBLC6-2 datasheet; USB Type-C spec values are labeled for verification where
the primary table could not be fetched.

<Note>

Findings in this page are **leads to verify on the bench, not verdicts**. A static
netlist review cannot measure voltages, observe protocol timing, or prove which of
several stacked defects actually produced the observed failure. The discrimination
procedure below exists precisely because more than one verified defect can explain the
symptoms.

</Note>

## The v4 symptom set collapses to one observable

Reported v4 symptoms: no PD negotiation, VBUS_EN_SNK never asserts, all rails dead.

The NVM on the v4 boards was programmed with `POWER_ONLY_ABOVE_5V = 1`
(see [NVM Programming Setup](./nvm-programming.md)). Per DS12499 Rev 4 Table 10
("VBUS_EN_SNK pin behavior"), with `POWER_ONLY_ABOVE_5V = 1b` the VBUS_EN_SNK pin stays
**Hi-Z at 5 V even in Attached.SNK**, and only asserts (open-drain pulls **low**) when
VBUS operates under PDO2 or PDO3. VBUS_EN_SNK is **active-low open-drain**
(DS12499 Table 1, pin 16): asserted = pulled low = Q1 P-FET on.

Therefore "VBUS_EN_SNK never asserts" and "rails dead" are the *expected downstream
consequences* of a single failure: **no 15 V contract is ever established (or never
survives)**. The diagnosis only has to explain the missing/collapsing 15 V contract.

<Warning>

A fast contract-then-collapse is indistinguishable from "no negotiation" on a DMM. A PD
contract, the 5 V to 15 V transition, an overcurrent event, and the source's protective
shutdown all complete within a few hundred ms. Only a scope on VBUS_IN and CC (procedure
below) can tell these apart.

</Warning>

## Verified front-end topology (from the 2026-07-05 netlist export)

<Note>

In this export the ground net is named `RST`: the `RST` label on U1 pin 6 (RESET,
active-high input, correctly strapped to ground) was absorbed as the name of the whole
GND net. Everywhere `RST` appears below, read **GND**.

</Note>

### Net table — USB-PD Input sheet (front-end nets)

| Net | Connected pins (Ref.Pin) | Value/Note |
|-----|---|---|
| `VBUS_IN` | `J1.A9 J1.B9 U1.24 D4.5 Q1.2 R11.2 R14.1 C1.2 C2.2 J3.4` | Receptacle VBUS. U1.24 = VDD (direct). **D4.5 = USBLC6-2 VBUS pin — candidate 2.** C1 10 µF, C2 100 nF decoupling |
| `Net-(J1-CC1)` | `J1.A5 D4.1 R17.1` | Connector-side CC1. R17 5.1 kΩ external Rd to GND |
| `Net-(U1-CC1)` | `D4.6 U1.2` | Chip-side CC1. **Only joined to the connector through D4's internal 1↔6 flow-through — candidate 3** |
| `Net-(J1-CC2)` | `J1.B5 D4.3 R18.1` | Connector-side CC2. R18 5.1 kΩ external Rd to GND |
| `Net-(U1-CC2)` | `D4.4 U1.4` | Chip-side CC2, via D4 internal 3↔4 |
| `CC1DB` | `U1.1 R19.1 J3.1` | Dead-battery pin, R19 (0 Ω) to GND — dead-battery mode disabled |
| `CC2DB` | `U1.5 R20.1 J3.2` | Dead-battery pin, R20 (0 Ω) to GND |
| `VBUS_VS_DISCH` | `U1.18 R14.2 TP6.1` | Pin-18 sense/discharge node; R14.1 is on `VBUS_IN` → **the v3 fix is present** (470 Ω series from VBUS_IN) |
| `VBEN` | `U1.16 R12.1 J3.8` | VBUS_EN_SNK, active-low open-drain, series R12 56 kΩ to gate node |
| `Net-(Q1-G)` | `Q1.1 R11.1 R12.2 C35.1` | Q1 gate. R11 100 kΩ pull-up to VBUS_IN (gate off = FET off), C35 100 nF to GND |
| `VBUS_OUT` | `Q1.3 R13.1 TP1.1 C5.1 C7.1 C9.1 C6.1 C8.1 C10.1 U2.1 U3.1 U4.1` | Switched rail feeding the DC-DC stage |
| `Net-(U1-DISCH)` | `U1.9 R13.2` | DISCH pin → R13 470 Ω → VBUS_OUT (power-system-side discharge) |
| `VREG_2V7` | `U1.23 C30.2 R15.2 R16.2 J3.3` | 2.7 V regulator, 1 µF decap, I2C pull-up rail |
| `Net-(U1-VREG_1V2)` | `U1.21 C34.1` | 1.2 V regulator, 1 µF decap |
| `SCL-pin1` / `SDA-pin2` | `U1.7 R15.1 J2.1` / `U1.8 R16.1 J2.2` | I2C to J2 pogo pads |
| `RST` (= GND) | `U1.6 U1.10 U1.12 U1.13 U1.22 U1.25 D4.2 J1.A12 J1.B12 J1.7 R17.2 R18.2 R19.2 R20.2 C30.1 C34.2 C35.2 J2.3 J3.5` (front-end members) | RESET, GND, ADDR0/1 (I2C 0x28), VSYS, EP all correctly strapped |

### Block diagram

```mermaid
flowchart TD
  J1["J1 USB-C receptacle"] -->|"Net-(J1-CC1) / Net-(J1-CC2)"| D4["D4 USBLC6-2SC6\nCC flow-through 1-6 / 3-4\nVBUS pin 5 on VBUS_IN"]
  J1 -->|"VBUS_IN"| VDD["U1.24 VDD (direct)"]
  D4 -->|"Net-(U1-CC1) / Net-(U1-CC2)"| U1["U1 STUSB4500\nPD sink controller"]
  RD["R17 / R18 5.1k external Rd\n(connector side, to GND)"] --- J1
  DB["CC1DB / CC2DB via R19 / R20 (0 ohm) to GND\n(dead-battery mode disabled)"] --- U1
  J1 -->|"VBUS_IN"| R14["R14 470 ohm"] -->|"VBUS_VS_DISCH"| P18["U1.18 sense/discharge"]
  U1 -->|"VBEN (active-low OD)"| R12["R12 56k"] --> GATE["Q1 gate node\nR11 100k pull-up to VBUS_IN\nC35 100n to GND"]
  GATE --> Q1["Q1 AO3401A P-FET\nS = VBUS_IN, D = VBUS_OUT"]
  Q1 -->|"VBUS_OUT"| DCDC["DC-DC stage U2/U3/U4"]
```

## Ranked root-cause candidates

### 1. External Rd in parallel with the powered chip's internal Rd — CC termination out of spec the moment U1 boots

**Severity: blocker (design defect, present on every board). Symptom fit: high, charger-dependent.**

**Net evidence.** `Net-(J1-CC1) = J1.A5 D4.1 R17.1` with `R17.2` on GND (5.1 kΩ), and
`Net-(U1-CC1) = D4.6 U1.2` — the external Rd and U1's CC1 pin sit on the same electrical
node (through D4's flow-through). Same for CC2 via R18. `CC1DB`/`CC2DB` are grounded
through R19/R20 (0 Ω), so dead-battery mode is disabled and the external resistors are
the **only** termination while U1 is unpowered.

**Datasheet basis.** DS12499 Rev 4 §7.3 Table 22: the STUSB4500 presents
**Rd = 5.1 kΩ ±10% pull-down on the CC pins** in operation (`RINCC` = 200 kΩ applies only
with "Terminations off", i.e. during reset — §2.2.1 "CC1 and CC2 are HiZ during reset").
The STUSB4500 is an auto-run sink controller; internal Rd cannot be disabled by NVM.
So once VBUS powers VDD (U1.24 is tied to VBUS_IN directly) and the chip loads its NVM
(TLOAD = 30 ms, Table 22), the source sees **5.1 kΩ ∥ 5.1 kΩ ≈ 2.55 kΩ** — below the
USB Type-C sink Rd window of 5.1 kΩ ±20% (4.08–6.12 kΩ; verify against USB Type-C
spec R2.0 §4.11.2 / Table 4-33). The v2 debug page itself computed this case and marked
it "below spec" — see the re-examination section below.

**Failure mechanism.** Source-perspective CC detection windows (USB Type-C R2.0
Table 4-36 — values below reconstructed from implementation datasheets, e.g. onsemi
FUSB3307 places its source-side Ra-vs-Rd comparator for 3 A Rp between 0.75 and 0.85 V;
label: verify against the spec table):

| Source Rp | Rp current | V(CC) with 5.1 kΩ (chip unpowered) | V(CC) with 2.55 kΩ (chip powered) | Rd-detect floor (vRd-Connect min) |
|---|---|---|---|---|
| Default USB | 80 µA ±20% | 0.41 V — valid | **0.20 V — below the 0.25 V floor, reads as Ra/undefined** | 0.25 V |
| 1.5 A | 180 µA ±8% | 0.92 V — valid | **0.46 V — barely above the 0.45 V floor** | 0.45 V |
| 3.0 A | 330 µA ±8% | 1.68 V — valid | **0.84 V — inside the 0.75–0.85 V undefined band** | 0.85 V |

Sequence on every cold plug: the unpowered board presents a clean 5.1 kΩ → the source
debounces, attaches, applies vSafe5V → U1's VDD comes up, and ~30–50 ms later the
internal Rd lands in parallel → the source's CC voltage drops by half, **right when the
source is about to send Source_Capabilities**. A source whose comparator now reads
"Rd removed / Ra" treats the sink as detached or invalid: it never negotiates, or
removes VBUS — which unpowers U1, restores 5.1 kΩ, and re-attaches in a loop. Because
0.84 V sits inside a 100 mV undefined band, resistor and Rp tolerances make the outcome
**charger-dependent and even board-dependent** — consistent with a design that fails
across multiple revisions while looking "almost right".

Note the sink side is marginal too: U1's own attach threshold VTH0.2 (min CC voltage
for a connected sink) is 0.15–0.25 V (Table 22), so on a default-Rp charger (0.20 V at
the chip) even U1's source-detection is a coin flip.

**Why v3's "stable 5 V + live I2C" does not contradict this.** The programming sessions
used USB-A-to-C or dumb 5 V chargers (per the NVM setup page), which supply VBUS without
sink-detection gymnastics. The failure window only opens on a spec-compliant PD source.

### 2. D4 (USBLC6-2SC6) VBUS pin on the 15 V rail — absolute-rating violation at the exact moment a contract succeeds

**Severity: blocker (hard datasheet violation). Symptom fit: high *if* negotiation ever completes; also explains permanently-dead boards afterward.**

**Net evidence.** `VBUS_IN = ... D4.5 ...` — the USBLC6-2's VBUS pin (pin 5) sits
directly on the receptacle VBUS rail, which carries **15 V after a successful contract**.

**Datasheet basis.** ST USBLC6-2 datasheet (Rev 2 text verified; later revisions list
5.25 V): reverse stand-off voltage **VRM = 5 V**, breakdown **VBR = 6 V min at 1 mA
between VBUS and GND**, clamping 12 V at 1 A (8/20 µs). The functional diagram
(Figure 1) shows a zener between pin 5 (VBUS) and pin 2 (GND). This part is designed for
5 V USB — it is never rated for a 15 V rail.

**Failure mechanism.** The instant the source transitions VBUS to 15 V, D4's VBUS-GND
zener goes into hard breakdown (15 V ≫ 6 V), sinking whatever the source can deliver
(up to 3 A). The source hits overcurrent protection within ms and shuts down, hiccups,
or hard-resets the port. On a DMM this reads as "no negotiation, rails dead" (see the
warning above). Depending on the energy delivered, D4 dies short (VBUS_IN then loaded
even at 5 V → the board looks completely dead on subsequent plugs) or survives to repeat
the cycle. **Boards already tested against a 15 V charger may therefore carry a damaged
D4 right now** — the bench procedure checks this first.

Note the interaction with candidate 1: if candidate 1 blocks negotiation on a given
charger, 15 V never arrives and D4 survives — the two candidates mask each other, which
is why the bench order below lifts D4 pin 5 *before* any test that could produce 15 V.

### 3. CC continuity through D4's internal flow-through — the netlist relies on a part-internal join

**Severity: blocker if broken (as-built defect, not a schematic defect). Symptom fit: complete if present.**

**Net evidence.** `Net-(U1-CC1) = D4.6 U1.2` and `Net-(U1-CC2) = D4.4 U1.4` — two-pin
nets. The only path from connector CC to U1's CC pins runs through D4's package-internal
pin 1↔6 and 3↔4 connections. The USBLC6-2 datasheet Figure 1 (functional diagram) does
show pins 1/6 and 3/4 as internally common nodes (flow-through routing), so the
**schematic is electrically valid** — but any substitution, rotation, or footprint
mismatch at D4 silently opens both CC lines to the chip while leaving the connector-side
external Rd intact.

**Failure mechanism.** With the flow-through open: the source still sees R17/R18
(connector side) → attaches → applies 5 V → U1 powers via VDD and I2C works — but U1's
CC pins float, it never sees the source's BMC signaling, never answers
Source_Capabilities, and the source falls back to Type-C 5 V-only. Every v3/v4
observation (stable 5 V, live I2C, no contract, VBUS_EN_SNK stays Hi-Z because
`POWER_ONLY_ABOVE_5V = 1`) is reproduced exactly. The v2 boards measured 0 Ω across
D4 pins 1↔6 (see [PCBA v2 Debug Report](./pcba-v2-debug.md)), but v4 is a different
assembly run — re-verify. (The as-built part-substitution audit is a separate task;
here only the electrical validity and the bench check are in scope.)

### 4. NVM configuration on the failed boards — `SNK_PDO_NUMB` / `POWER_ONLY_ABOVE_5V` read-back

**Severity: marginal (shapes symptoms rather than blocking PD). Symptom fit: partial but cheap to eliminate.**

**Evidence.** Not a netlist item. The intended configuration is `SNK_PDO_NUMB = 2`,
PDO2 = 15 V/3 A, `POWER_ONLY_ABOVE_5V = 1` ([NVM Programming Setup](./nvm-programming.md)).
Two failure shapes worth eliminating by read-back on the *dead* boards:

- The setup page itself warns `POWER_ONLY_ABOVE_5V` "sometimes doesn't save on the first
  write". Other bits can fail the same way. A partial write (e.g. `SNK_PDO_NUMB` still 1,
  or PDO2 voltage not 15 V) produces a sink that negotiates a **5 V-only PD contract** —
  with `POWER_ONLY_ABOVE_5V = 1` the result is symptom-identical to "no negotiation"
  on a DMM (VBUS_EN_SNK stays Hi-Z per DS12499 Table 10).
- VBUS monitoring windows (DS12499 §3.4.1, Table 22: VMONUSBH/VMONUSBL, default
  −20%/+15% at attach) are NVM-programmable; a corrupted shift coefficient could make
  the chip reject valid VBUS. Default values are safe — verify they are still default.

### 5. Re-confirmed items — verified OK in this pass (no action)

| Item | Net evidence (this export) | Verdict |
|---|---|---|
| Pin-18 network (the v3 root cause) | `VBUS_VS_DISCH = U1.18 R14.2 TP6.1`, `R14.1` on `VBUS_IN`, R14 = 470 Ω | **OK.** Matches DS12499 Table 1 pin 18 "From VBUS, receptacle side". Table 22 (IDISUSB) specifies discharge "through external resistor connected to VBUS_VS_DISCH pin", ≤50 mA: 15 V / 470 Ω ≈ 32 mA — inside the rating. The v3 fix is present and correctly valued |
| Q1 gate drive | `Net-(Q1-G) = Q1.1 R11.1 R12.2 C35.1`; R11 100 kΩ → VBUS_IN, R12 56 kΩ → VBEN | **OK.** VBEN asserted (low): V(gate) = VBUS × 56/156 → Vgs ≈ −0.64 × VBUS = −3.2 V at 5 V, −9.6 V at 15 V — both enhance the AO3401A well and stay inside its ±12 V Vgs limit (verify against the AOS AO3401A datasheet). VBEN released: R11 pulls Vgs to 0 V, FET off |
| RESET / ADDR / VSYS / EP | `U1.6 U1.12 U1.13 U1.22 U1.25` all on GND | **OK.** RESET is active-high (DS12499 §2.2.3) so ground = run; ADDR = 0x28; VSYS grounded is correct for VDD-only supply (Table 1) |
| Decoupling | VDD: C1 10 µF + C2 100 nF on `VBUS_IN`; VREG_2V7: C30 1 µF; VREG_1V2: C34 1 µF | **OK.** Matches DS12499 Table 1 typical connections (1 µF typ. on each regulator) |
| VDD rating | U1.24 direct on `VBUS_IN` (15 V contract) | **OK.** VDD range 4.1–22 V (DS12499 Features/§7); 15 V is fine. U1's CC pins carry 22 V short-to-VBUS protection — U1 itself does not need D4 to survive CC faults |
| I2C | `SCL-pin1`/`SDA-pin2` with 4.7 kΩ pull-ups to VREG_2V7 | **OK.** Proven working on v3 hardware |

## Re-examination of the v2 "CC1DB chip-internal short" conclusion

The entire external-Rd topology (candidate 1) exists because of the v2 diagnosis
([PCBA v2 Debug Report](./pcba-v2-debug.md)): CC1 measured 0 Ω to GND on two boards,
the empty pad measured open after hot-air removal of U1, and the conclusion was
"CC1DB internally shorted — batch defect", fixed by grounding the DB pins and adding
external Rd. Re-reading that evidence against DS12499:

**What holds up.** The asymmetry was real on those chips: CC2 (wired CC2DB↔CC2 in v2)
measured 5.1 kΩ unpowered while CC1 measured 0 Ω, and removing U1 removed the short.
Something genuinely differed between pin 1 and pin 5 on those two v2 chips.

**What does not hold up.**

- The 5.1 kΩ read on CC2 was **not** "chip-internal Rd works" as the v2 page says — an
  unpowered STUSB4500 presents no Rd on CC2 itself. What was measured was the
  **dead-battery termination through CC2DB behaving exactly as designed**
  (DS12499 §3.5: the DB path "presents a pull-down termination on its CC pins ... even
  if the device is not supplied").
- A dead-battery termination is an unpowered depletion-type pull-down, characterized
  only by its behavior at Rp currents (80–330 µA). Its small-signal resistance under a
  DMM's test current is **not specified** by ST — a low-ohms reading on an unpowered DB
  pin is not, by itself, proof of a defect. The v2 measurement never recorded DMM test
  polarity or current, never compared a known-good reference chip measured the same
  way, and never confirmed the "short" at operating conditions. "0 Ω" on an autoranging
  DMM can be anything below tens of ohms.
- Even granting a genuine CC1DB defect on that one LCSC batch, the v3 response traded an
  unproven single-batch defect for a **permanent spec violation**: the v2 page's own
  table computes "good chip + ext 5.1 kΩ → 2.55 kΩ — below spec" and even states the
  proper fix is to remove the external Rd once the chip's Rd is known healthy. The v3/v4
  chips demonstrably run (I2C alive, NVM programmable), so their internal Rd is active,
  and 2.55 kΩ is the operating condition on every powered attach — candidate 1.
- DS12499 §3.5 says dead-battery mode "is also used in systems that are powered through
  the VBUS only" — i.e. ST's intended topology for exactly this board is CCxDB↔CCx with
  **no** external Rd (as used by the SparkFun board, STEVAL-ISC005V1, and datasheet
  Figure 10). For a VBUS-only sink, "ground the DB pins" (the no-dead-battery option)
  plus external Rd is structurally self-contradictory: the external Rd is mandatory for
  the unpowered attach, but out of spec the moment the chip runs.

**Verdict: the v2 chips may or may not have been defective — the evidence is
inconclusive — but the redesign built on that conclusion is itself a defect.** The v5
fix should return to the ST reference wiring (CC1DB↔CC1, CC2DB↔CC2, no external Rd,
optionally keeping DNP footprints for R17/R18 as rework insurance), pending the bench
result of test B4 below.

## Bench discrimination procedure (dead v4 boards, cheapest first)

Equipment: DMM with diode mode, fine probes, soldering iron + hot air, a scope
(≥10 MHz is plenty for attach dynamics; CC BMC bursts just need to be *seen*, not
decoded), the 15 V/3 A PD charger that failed, a USB-A-to-C cable, the NVM programming
rig ([NVM Programming Setup](./nvm-programming.md)).

<Warning>

Do all Stage A checks before ever plugging the PD charger in again, and do the D4
pin-5 lift (test C1) **before** any test that could let a 15 V contract succeed.
Candidates 1 and 2 mask each other: fixing the CC termination without lifting D4 pin 5
feeds the first successful 15 V contract straight into a 6 V zener.

</Warning>

### Stage A — unpowered continuity and damage survey (DMM only, 10 minutes)

| # | Test | Expected if OK | Outcome branches |
|---|---|---|---|
| A1 | Continuity `J1.A5` ↔ `U1.2` (probe at R17 pad 1 vs D4 pin 6 or the U1.2 QFN edge) and `J1.B5` ↔ `U1.4` (R18 pad 1 vs D4 pin 4) | ≈ 0 Ω both lines | Open or high on either line → **candidate 3 confirmed as the blocker** (as-built D4 issue: wrong variant, rotation, bad joint). Stop, fix D4, retest attach. Both ≈ 0 Ω → candidate 3 eliminated on this board |
| A2 | Diode-mode D4 pin 5 (`VBUS_IN`) to GND, both polarities | One direction ≈ 0.6–1.1 V drop (zener forward), other direction open below the DMM test voltage | Short both ways → **D4 already destroyed → strong evidence a 15 V contract DID complete at least once** (negotiation works; candidate 2 is the killer, candidates 1/3 were not blocking on this charger). Replace/remove D4 before further tests |
| A3 | Resistance CC1→GND and CC2→GND at the connector (board unpowered) | ≈ 5.1 kΩ each (external Rd only; DB pins are grounded so no chip termination) | ≈ 2.5 kΩ → unexpected unpowered termination, investigate U1/D4 damage. ≈ 0 Ω → damaged D4 or U1 CC pin, or solder fault |
| A4 | Resistance `VBUS_IN` (J3 pad 4) ↔ TP6 | ≈ 470 Ω (R14) | Open or ≫ 470 Ω → pin-18 path broken as-built despite correct schematic — would gate VBUS_EN_SNK even after a good contract (DS12499 Table 10 conditions run on the VBUS_VS_DISCH pin) |
| A5 | Continuity J3 pad 1 (`CC1DB`) → GND and J3 pad 2 (`CC2DB`) → GND | ≈ 0 Ω (R19/R20) | Open → R19/R20 missing; a floating DB pin is out of ST's two sanctioned options (DS12499 §2.2.2 warning) |

### Stage B — powered observation (USB-A-to-C first, then scope the PD attach)

| # | Test | Expected / branches |
|---|---|---|
| B1 | USB-A-to-C 5 V source (no CC negotiation involved): J3 pad 4 ≈ 5 V, J3 pad 3 ≈ 2.7 V, I2C detect at 0x28 | Fails → chip supply problem, stop and fix first (see decision tree in the NVM page). Passes → chip runs; proceed |
| B2 | While on the 5 V source, **read back the full NVM** and diff against target (`SNK_PDO_NUMB = 2`, PDO2 = 15 V/3 A, `POWER_ONLY_ABOVE_5V`, monitor coefficients at default) | Any mismatch → **candidate 4**: rewrite, verify, retest attach before any hardware surgery |
| B3 | Scope CC1 (at R17 pad 1) and CC2 (R18 pad 1) plus `VBUS_IN`, then plug the failing 15 V/3 A PD charger. Watch the first 2 s | See branch table below — this single capture separates candidates 1, 2, 3 |
| B4 | Repeat B3 on the *other* CC line if the cable orientation put activity on CC2 | Same branches |

**B3 branch table** (assuming the charger idles with 3 A Rp; scale by the table in
candidate 1 for other Rp values):

| Observation on the active CC line | Reading |
|---|---|
| CC ≈ 1.68 V after plug, drops to ≈ 0.84 V within ~100 ms of VBUS rising, then VBUS cycles off/on at roughly 0.5–2 Hz | **Candidate 1 confirmed on this charger**: internal Rd landed in parallel, source read "Rd removed", detached, chip lost power, loop |
| CC ≈ 1.68 V, drops to ≈ 0.84 V, VBUS stays 5 V, BMC bursts visible but no 15 V step | Source tolerates 2.55 kΩ but PD exchange dies — look for missing GoodCRC (candidate 3 partially open? U1 dead to PD?); capture longer, and observe `ATTACH` on J3 pad 6 — note it is open-drain with **no pull-up on this board** (net `ATT` = `U1.11 J3.6` only), so first add a temporary 10 kΩ pull-up from J3 pad 6 to VREG_2V7 (J3 pad 3); asserted = pulled low |
| CC ≈ 1.68 V and **stays** ≈ 1.68 V after VBUS rises (no halving), no PD | U1's Rd never appeared on the connector: chip-side CC is disconnected (**candidate 3**) even though A1 passed at DC — re-probe A1 warm, inspect D4 joints |
| VBUS steps toward 15 V then collapses hard, possibly with an audible/thermal event at D4, charger retries or latches off | **Negotiation works; candidate 2 is the blocker.** Confirm with A2 afterward (D4 likely now damaged) |
| CC attach fine, VBUS solid 5 V, `ATTACH` asserts low, BMC visible both directions, contract to 15 V never requested | Re-check B2 (NVM) — this is the candidate-4 shape |

### Stage C — bodge tests (only after A/B, in this order)

| # | Bodge | Validity condition | Expected |
|---|---|---|---|
| C1 | **Lift D4 pin 5** from its pad (leave pins 1/2/3/4/6 soldered — flow-through and GND stay intact, only the 6 V zener rail disconnects). Alternative: remove D4 entirely and bridge pads 1↔6 and 3↔4 with fine wire | Valid on its own — removes candidate 2 without touching CC continuity. ESD protection on CC is degraded at the bench (acceptable: U1's CC pins are rated 22 V short-to-VBUS, DS12499 features) | If B3 showed the 15 V-collapse branch: retest now brings full 15 V and live rails → **done, candidate 2 was the (final) blocker**. Otherwise proceed to C2 |
| C2 | **Restore the ST reference termination**: remove R17 and R18 (kills the external Rd) **and** remove R19 and R20 **and** wire CC1DB↔CC1 (J3 pad 1 → R17 pad 1) and CC2DB↔CC2 (J3 pad 2 → R18 pad 1) | **Removing R17/R18 alone is NOT a valid test** — with DB pins grounded there would be no unpowered Rd at all, the source would never apply VBUS, and the board would look dead for an unrelated reason. The DB rewire must be part of the same bodge so the dead-battery termination replaces the external Rd (DS12499 §2.2.2/§3.5) | Plug the PD charger (with C1 already done): attach via DB termination, CC sits at single-Rd voltage (≈ 1.68 V at 3 A Rp) with **no halving step**, PD negotiates, VBUS → 15 V, VBUS_EN_SNK pulls low, rails live → **candidate 1 confirmed as the v4 blocker and the v5 fix is validated** |
| C3 | If C2 instead shows CC1 dragged to ≈ 0 V and no attach | This is the one outcome that would **rehabilitate the v2 "bad CC1DB" conclusion for this batch too** | Swap U1 with a known-good STUSB4500 (e.g. from a SparkFun breakout) and repeat C2; also measure the removed chip's CC1DB/CC2DB to GND with recorded polarity/current for the record |
| C4 | After any success: verify the full chain at 15 V — TP6 ≈ 15 V, VBUS_OUT ≈ 15 V, Q1 gate ≈ 5.4 V (Vgs ≈ −9.6 V), +12/−12/+5 rails up | Confirms no second-order blockers downstream of the front end |

## What this pass can and cannot catch

This was a static netlist-plus-datasheet review. It **can** catch: wrong-net wiring,
missing/parallel terminations, component ratings violated by design voltages, pin-role
misunderstandings, and invalid bench tests. It **cannot** catch: as-built substitutions
or rotations (only bench A1/A2 and the separate assembly-audit task can), solder
defects, whether the NVM on the dead boards actually contains what the docs say it does
(B2), actual charger behavior inside the CC undefined bands (implementation-specific by
definition), chip authenticity, or dynamic/protocol-timing failures. The USB Type-C
Table 4-36 window values above were cross-checked only against implementation
datasheets, not the spec text itself — verify before treating a marginal reading as
in- or out-of-window. Candidates 1 and 2 are verified *defects*; whether each is *the*
defect that produced the observed v4 symptoms is exactly what Stages A–C decide.

## References

- ST DS12499 Rev 4, STUSB4500 datasheet — Table 1 (pin list; pin 16 "active low";
  pin 18 "From VBUS, receptacle side"), §2.2.1/§2.2.2 (CC HiZ during reset; DB warning),
  §3.4.1–3.4.3 + Table 10 (VBUS monitoring, discharge, VBUS_EN_SNK behavior vs
  `POWER_ONLY_ABOVE_5V`), §3.5 (dead-battery mode, VBUS-only systems), §7.3 Table 22
  (Rd 5.1 kΩ ±10%, RINCC, VTH0.2, IDISUSB 50 mA via external resistor, VMONUSB, TLOAD)
  — [st.com PDF](https://www.st.com/resource/en/datasheet/stusb4500.pdf)
- ST USBLC6-2 datasheet — Table 3 (VRM 5 V, VBR 6 V min at 1 mA VBUS-GND, VCL 12 V at
  1 A; later revisions list VRWM 5.25 V), Figure 1 (functional diagram: 1↔6 / 3↔4
  flow-through, VBUS-GND zener) — [st.com PDF](https://www.st.com/resource/en/datasheet/usblc6-2.pdf)
- USB Type-C Cable and Connector Specification R2.0 — §4.11.2 (Rd 5.1 kΩ ±20%),
  Table 4-36 (source-perspective CC windows; verify — reconstructed here via the onsemi
  FUSB3307/FUSB301 datasheets' source comparator bands)
- [PCBA v2 Debug Report](./pcba-v2-debug.md) — the original CC1DB evidence re-examined above
- [v3 USB-PD Failure Diagnosis](./v3-pd-failure-diagnosis.md) — pin-18 root cause, fixed in v4 and re-confirmed here
- [NVM Programming Setup](./nvm-programming.md) — programmed values, read-back procedure
- [STUSB4500 pinout guide](./stusb4500-pinout.md) — pin-by-pin reference

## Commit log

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2025-12-27 Optimize parts list with high-stock alternatives
    - Replace CH224Q with CH224D (higher stock: 2,291 units)
    - Update USB-PD IC for better 15V support
    - Switch to high-stock LDO regulators:
    * L7812CV-DG (158,795 stock)
    * L7805ABD2T-TR (272,379 stock)
    * CJ7912 (3,386 stock)
    - Update pricing and subtotals
    - Improve long-term procurement stability
    Total cost optimized to $4.68 per board with all parts
    having excellent stock availability at JLCPCB.
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2025-12-27 Convert all footprint PNG images to white backgrounds
    Replaced transparent backgrounds with solid white for better visibility
    and printing compatibility across all 9 footprint images:
    - CH224D.png
    - CJ7912.png
    - ICL7660M.png
    - L7805ABD2T.png
    - L7812CV.png
    - LM2596S-ADJ.png
    - PRTR5V0U2X.png
    - SMAJ15A.png
    - USB-TYPE-C-009.png
    White backgrounds provide:
    - Better contrast when viewing in documentation
    - Consistent appearance across different viewers
    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
2025-12-27 Add missing component datasheets (6 files)
    Completed datasheet collection for all unique parts:
    **Downloaded Datasheets:**
    1. ICL7660M-datasheet.pdf (511 KB, 11 pages)
    - Voltage inverter IC (SOP-8)
    - Manufacturer: HGSEMI
    - Source: LCSC
    2. L7812CV-datasheet.pdf (1.3 MB, 48 pages)
    - +12V Linear regulator (TO-220)
    - Manufacturer: STMicroelectronics
    - Source: Octopart
    3. L7805ABD2T-datasheet.pdf (1.5 MB)
    - +5V Linear regulator (TO-263-2/D2PAK)
    - Manufacturer: STMicroelectronics
    - Source: LCSC
    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
2025-12-27 Add Learning section with open-drain output explanation
    Create new documentation section for circuit design concepts learned
    during project development.
    New files:
    - learning/index.md: Overview of learning topics
    - learning/open-drain-pg-pin.md: Detailed explanation of how the
    CH224Q PG pin works as an open-drain output
    Topics covered:
    - What is an open-drain output vs regular logic output
    - How PG pin acts as a switch to ground
    - Why LED is connected +5V → LED → PG (not the other way)
    - Circuit behavior timeline during USB-PD negotiation
    - Common mistakes to avoid
    Updated navigation:
    - Added "Learning" to navbar (docusaurus.config.js)
    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
2025-12-27 Improve buck converter circuit diagrams with clear topology
    Redesigned Diagram2, Diagram3, and Diagram5 (LM2596S-ADJ stages) to
    clearly show the correct buck converter topology:
    Changes:
    - Clearly show VOUT (pin 4) → Inductor → Output path
    - Add input capacitors (100µF bulk + 100nF decoupling) to diagrams
    - Show flyback diode at switching node (VOUT-inductor junction)
    - Separate feedback voltage divider for clarity
    - Update ICL7660 capacitor designators (C9,C10 → C12,C13)
    Fixes the confusion where inductor appeared to be on input side.
    Now all three buck converter diagrams follow consistent, accurate format.
    Affected diagrams:
    - Diagram2: +15V → +13.5V (U2)
    - Diagram3: +15V → +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
2025-12-27 Add JLCPCB links and fix diagram on all parts pages
    Added direct JLCPCB part links at the top of every component
    documentation page for easy access to stock, pricing, and specs.
    - Added 🔗 JLCPCB links to all 8 component pages:
    * CH224D (C3975094)
    * LM2596S-ADJ (C347423)
    * ICL7660M/TR (C356724)
    * L7812CV-DG (C2914)
    * L7805ABD2T-TR (C86206)
    * CJ7912 (C94173)
    * SMAJ15A (C571368)
    * PRTR5V0U2X (C5199240)
    - Fixed LM2596S-ADJ diagram to show correct topology:
    * Clearly shows VOUT → Inductor → Output
    * Matches the improved circuit diagrams format
    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
2025-12-27 Fix buck converter diagrams: resolve flying lines and use ASCII-only
    Major fixes to all three buck converter circuit diagrams (U2, U3, U5):
    1. Fixed flying/disconnected lines - Vertical line from switching node
    to D1 now properly aligned with junction at VOUT pin 4
    2. Converted to ASCII-only characters:
    - Replaced → with ->
    - Replaced Unicode box-drawing (─│┌┐└┘├┤┬┴) with ASCII (+-|)
    - Better compatibility and monospace rendering
    3. Added comprehensive connection documentation for each converter
    These fixes resolve the critical "line appears floating in space" issue
    that made the topology ambiguous in the previous Unicode version.
    🤖 Generated with [C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
2025-12-27 Convert Diagram1 (USB-PD section) to ASCII-only characters
    Converted USB-C connector and CH224Q circuit diagram from Unicode
    box-drawing characters to ASCII for better compatibility:
    - Replaced Unicode arrows (→ ←) with ASCII (-> <-)
    - Replaced box-drawing characters with ASCII (+-|)
    - Fixed topology: Only VBUS and GND branch to capacitors
    - CC1 and CC2 go straight to CH224Q (no false junctions)
    - Used spacing to show independent signal paths clearly
    Critical fix: Avoided ambiguous junctions that would incorrectly
    show CC1/CC2 connected to the capacitor ground line.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
2025-12-27 Improve Diagram1 (USB-PD) with better ASCII circuit layout
    Major improvements to Diagram1 following enhanced circuit diagram rules:
    - Fix component connections: C1/C2 now show exactly 2 legs with proper T-junctions
    - Eliminate false junctions: CC1/CC2 repositioned above VBUS to avoid crossing capacitor lines
    - Add proper box padding: J1 box expanded from 15 to 17 chars for text clearance
    - Separate LED circuit: Move complex LED indicator circuit to dedicated diagram block
    - Fix vertical line alignment: Correct 1-character misalignment in LED circuit
    Updated ASCII circuit diagram skill with new golden rules:
    - Rule 7: Boxes must have proper padding (1 space minimum on each side)
    - Rule 8: S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
2025-12-29 Complete footprint preview page with all BOM components
    Added missing footprints to preview page:
    - 100µH power inductor (CYA1265-100UH)
    - 0805 capacitors and LEDs
    - D6.3mm electrolytic capacitors (470µF/100µF)
    - PTC resettable fuses (1206 0.75A, 1812 1.1A)
    - SMD fuses (2410 2A, 10.1x3.1mm 1.5A)
    - SMAJ15A TVS diode (SMA package)
    Fixed:
    - L7812 footprint reference (TO-220 → TO-263-2)
    - Removed small Ø4.0mm electrolytic (not in BOM)
    Note:
    - PRTR5V0U2X (SOT-143) footprint unavailable from EasyEDA API
    All components from BOM now documented with visual footprints.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
2025-12-29 Clarify ICL7660 pin connections in Diagram3
    Fixed confusing ASCII art that made pins 1/4/5 look interconnected.
    Clarified:
    - C12 (flying capacitor) connects ONLY between Pin 1 (CAP+) and Pin 4 (CAP-)
    - Pin 5 (V-) is separate and outputs -15V
    - C13 is the output filter capacitor (not part of charge pump)
    Added explicit NOTE to prevent confusion about flying capacitor connections.
2025-12-29 Clarify ICL7660 dual V+ pins (pins 2 & 8) connection
    Changed from ambiguous notation:
    - "2,8 V+" looked like one pin
    To explicit dual pin connection:
    - Pin 2 V+ ──┐
    - Pin 8 V+ ──┤── Both tied to +15V
    (tie pins 2&8)
    Both pins 2 and 8 must be connected to +15V for:
    - Better current distribution
    - Lower noise and better filtering
    - Improved thermal performance
    This is standard IC design practice for power pins.
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2025-12-29 Fix Diagram4 critical connection errors - VIN and FB pins
    CRITICAL ERRORS FIXED:
    ❌ Pin 1 (VIN) was not connected to -15V input
    ❌ Pin 4 (FB) was connected to GND instead of feedback tap
    CORRECTIONS:
    ✅ Pin 1 (VIN) now correctly connects to -15V input
    ✅ Pin 4 (FB) now correctly connects to feedback divider tap
    ✅ Pin 3 (GND) connects to system GND
    ✅ Pin 5 (ON/OFF) left floating
    Updated Key Connections section to clearly show all pin connections.
    Thank you for catching these errors!
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2025-12-30 Add critical section on connecting redundant USB-C pins together
    Add comprehensive explanation of why both VBUS and GND pins must be connected:
    Benefits Explained:
    - 50% reduction in resistance (R → R/2)
    - 50% less voltage drop (better efficiency)
    - 75% less power dissipation (I²R → I²R/4)
    - Current distribution (3A → 1.5A per pin)
    - Reduced heating and EMI
    - Redundancy and reliability
    Practical Example:
    - Single pin: 30mV drop, 90mW dissipation
    - Both pins: 15mV drop, 45mW dissipation (50% better)
    Includes:
    - Correct vs wrong connection diagrams
    - Benefits comparison table
    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
2025-12-30 Fix USB-C connector footprint image path
    Change image path from /footprints/TYPE-C-6P.png to /footprints/USB-TYPE-C-009.png
    This resolves the MDX compilation error: "Markdown image couldn't be resolved"
    The correct filename matches the actual file in doc/static/footprints/
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2025-12-30 Fix C5/C6 capacitor placement in buck-u2-diagram
    Swap C5 and C6 positions to follow best practices:
    - C5 (100µF electrolytic): farther from IC - bulk filtering
    - C6 (100nF ceramic): closer to IC - high-frequency decoupling
    Ceramic capacitors must be placed closest to the IC for proper high-frequency noise filtering.
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2025-12-30 Connect ON pin to GND and improve component sizing in buck-u2-diagram
    - Connect ON pin to GND (tie to ground for always-on operation)
    - Match GND pin line length to ON pin (2.5 → 1.0) for visual consistency
    - Scale down resistors (scale=0.7) for better proportions
    - Tighten feedback network spacing (0.5 → 0.2) for compact layout
    - Adjust inductor label offset for better positioning
    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
2025-12-31 Document feedback compensation network in LM2596S-ADJ
    - Add section 2: Feedback Compensation Network
    - Explain Type II compensation topology with CFF capacitor
    - Document C4, C8, C12 (22nF) compensation capacitors
    - Explain why 22nF works for all three converters
    - Add component values to U2, U3, U4 parts lists
    - Fix output capacitor designators: C3→C3, C4→C7, C7→C11
    - Update section numbering (sections 3-8)
    - Reference LM2596 datasheet Figure 1
    Benefits documented:
    - Improves transient response during load changes
    - Reduces switching noise on feedback line
    - Prevents control loop oscillation
    - Creates pole-zero pair for Type II compensation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
2025-12-31 Add Diagram5: -15V → -13.5V buck converter (U4, negative voltage)
    - Add schemdraw diagram source: diagram-sources/buck-u5-diagram.py
    - Generate SVG diagram: doc/static/circuits/buck-u5-diagram.svg
    - Add fragment with SVG: doc/docs/_fragments/buck-u5-diagram.mdx
    - Component designators: U4, L3, D3, C11, C12, C13, C14, R5, R6
    Key differences for negative voltage regulation:
    - Voltage labels: -15V input, -13.5V output (negative with respect to GND)
    - Electrolytic capacitors REVERSED with .reverse():
    - C13 (100µF input): Negative terminal to -15V, positive to GND
    - C11 (470µF output): Negative terminal to -13.5V, positive to GND
    - Diode polarity FLIPPED (opposite of positive voltage):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
2025-12-31 Refactor circuit diagrams page with Mermaid power flow overview
    - Move Power Flow Overview to the top as first section
    - Replace ASCII diagram with Mermaid flowchart showing relationships between all diagrams
    - Add color coding: blue for input, green for positive outputs, orange for negative output
    - Include output current specifications in overview
    - Remove duplicate Diagram9 section from bottom of page
    The Mermaid diagram provides a clear visual representation of the complete power
    conversion chain from USB-C input through all stages to final outputs.
2026-01-01 Add Diagram4: ICL7660 voltage inverter circuit (+15V to -15V)
    Create complete circuit diagram for the ICL7660 voltage inverter:
    - Schemdraw Python source (diagram-sources/inverter-u5-diagram.py)
    - Generated SVG circuit diagram (doc/static/circuits/inverter-u5-diagram.svg)
    - MDX fragment with SVG and ASCII art (doc/docs/_fragments/inverter-u5-diagram.mdx)
    - Integrate into circuit-diagrams page (replaces ASCII-only section)
    Circuit details:
    - ICL7660M charge pump voltage inverter
    - Flying capacitor C12 (10µF) between CAP+ and CAP- pins
    - Output filter capacitor C13 (10µF)
    - Generates -15V output from +15V input
    - Feeds U4 buck converter for -13.5V intermediate rail
    🤖 Generated with [Cla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
2026-01-01 Replace ICL7660M with LM2586SX-ADJ for high-current negative voltage generation
    Changed Diagram4 from ICL7660M charge pump to LM2586SX-ADJ inverted SEPIC converter
    to meet the 800mA current requirement for the -12V rail.
    Key changes:
    - U5: ICL7660M (100mA max) → LM2586SX-ADJ (3A capable)
    - Topology: Simple charge pump → Inverted SEPIC (2 inductors, coupling cap, feedback)
    - Updated all documentation references across 9 files
    - Added comprehensive LM2586SX-ADJ component documentation
    - Downloaded datasheet and generated TO-263-7 footprint files
    - Updated BOM with new components (inductors, caps, diode, resistors)
    - Added MDX syntax guidelines to CLAUDE.md to prevent < character errors
    -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
2026-01-01 fix: correct LM2586SX-ADJ TO-263-7 pinout (critical error)
    CRITICAL FIX: Pin 7 is VIN, not pin 1
    The LM2586SX-ADJ in TO-263-7 package has this pinout:
    - Pin 1: Freq. Adj. - On/Off (NOT VIN!)
    - Pin 2: Compensation
    - Pin 3: Feedback
    - Pin 4: Ground
    - Pin 5: Switch
    - Pin 6: Freq. Sync.
    - Pin 7: VIN (input voltage)
    Previous diagram incorrectly showed pin 1 as VIN, which would
    prevent the circuit from working. Datasheet page 3 confirms
    the correct pinout.
    Updated:
    - doc/docs/components/lm2586sx-adj.md: Pin configuration table and diagram
    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
2026-01-01 fix: resolve duplicate component designators in BOM
    Renumbered linear regulator stage components to avoid conflicts with
    U5 SEPIC stage:
    Duplicate conflicts resolved:
    - C14, C15, C16 → C26, C27, C28 (input filter capacitors)
    - R7, R8, R9 → R14, R15, R16 (LED current limit resistors)
    U5 SEPIC designators preserved:
    - C14 (100µF output filter)
    - R7 (10kΩ feedback upper)
    - R8 (920Ω feedback lower)
    This ensures each component has a unique designator for proper PCB
    assembly and avoids confusion during manufacturing.
2026-01-01 docs: update circuit diagrams to match renumbered BOM designators
    Updated component designators across all linear regulator diagrams
    and buck converter U4 to match the corrected BOM:
    Linear regulator input filters (ceramic):
    - C14 → C26 (U6 LM7812 input filter)
    - C15 → C27 (U7 LM7805 input filter)
    - C16 → C28 (U8 CJ7912 input filter)
    LED current limit resistors:
    - R7 → R14 (LED2 +12V indicator)
    - R8 → R15 (LED3 +5V indicator)
    - R9 → R16 (LED4 -12V indicator)
    Buck converter U4 input capacitors:
    - C13 → C9 (100µF bulk)
    - C14 → C10 (100nF decoupling)
    This ensures all circuit diagrams use the correct component
    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
2026-01-01 chore(deps): update dependencies and fix security vulnerability
    Updated dependencies:
    - @typescript-eslint/eslint-plugin: 8.50.1 → 8.51.0
    - @typescript-eslint/parser: 8.50.1 → 8.51.0
    Security fixes:
    - Fixed high severity DoS vulnerability in qs package (transitive
    dependency through @docusaurus/core → webpack-dev-server → express)
    - qs now patched to >=6.14.1
    Audit results: No known vulnerabilities found
    Note: eslint-plugin-react-hooks remains at 5.2.0 (latest 7.0.1 is
    a major version jump that may have breaking changes)
    Also fixed:
    - Pre-commit hook to run from correct directory and use existing
    'check' script instead of non-existent 'test' script
    - TypeScript errors in Docs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
2026-01-19 docs: Add CH224D charger compatibility documentation
    - Document known working/not working USB-PD chargers
    - Add technical explanation of CH224D vs PC/tablet PD controllers
    - Document root causes (dynamic power management, timing, missing 5V PDO)
    - Add symptoms when charger is incompatible
    - Update multi-case setup section with compatibility warnings
    - Mark high-wattage multi-port GaN chargers as often incompatible
    - Update box-header 3D print files
    Tested chargers:
    - Working: Anker Nano II 65W (A2663)
    - Not working: Anker Prime 200W, Elecom EC-AC67150BK,
    Digiforce Square 65W, CIO NovaPort SLIM 45W
    Related: #33 (STUSB4500 replacement consideration)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
    [box-header.scad, box-header.stl]
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2026-01-22 fix: Change R12 from 33kΩ to 56kΩ for improved Vgs margin
    Previous 33kΩ value gave Vgs = -11.3V (only 6% margin from ±12V max).
    New 56kΩ value gives Vgs = -9.6V (20% margin from max rating).
    [usb-pd-input.kicad_sch]
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2026-07-05 docs(inbox): v4 as-built audit + v0_4_0 snapshot scaffold (#88)
    Verifies whether the pin-18 fix (VBUS_IN -> R14 -> U1.18) and intended
    BOM actually reached a v0.4.0 JLCPCB order, and audits U1/J1/D4
    footprint geometry (pad position/rotation/mirroring) against their
    datasheet pinouts. Recovers the locally-generated JLCPCB manufacturing
    package (BOM/CPL/gerbers) from this machine's gitignored jlcpcb/
    working directory, dated 2026-06-05 -- the gap the missing
    jlcpcb-order-snapshots/v0_4_0/ directory was hiding -- and scaffolds
    that directory (used-for-order/ populated, from-order-detail/
    placeholder with exact JLCPCB-account-lookup instructions).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
    [BOM-zudo-pd.csv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]
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2026-07-05 fix(usb-pd): restore CCDB topology, DNP external Rd, remove D4, add SMAJ20A (#93)
    Rows 1-5 of the locked spec from #90 (issue #93):
    - Delete D4 (USBLC6-2SC6, C7519): its 6V zener clamped the 15V VBUS rail
    and its internal flow-through carried the CC lines. CC nets now merge
    straight through: CC1 = J1.A5 + U1.2 + R17.1 + R19.2, CC2 = J1.B5 +
    U1.4 + R18.1 + R20.2 (netlist-verified partition match).
    - R17/R18 (external 5.1k Rd): DNP + exclude from BOM + exclude from
    position files. Footprints and value kept for bench-option rework.
    - R19/R20 pin 2 rewired from GND to CC1/CC2: they are now the fitted
    0R CC1DB<->CC1 / CC2DB<->CC2 links (CCDB debug topology restored).
    - Add D5 = SMAJ20A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
    [usb-pd-input.kicad_sch]
2026-07-05 fix(power): merge -12V decoupling to GND + C9 50V swap + cap value fixes (#93)
    Rows 6-8 of the locked spec from #90 (issue #93):
    - Row 6: merge Net-(C16-Pad2) into GND (linear-regulation). The -12V
    LDO decoupling group C16.2/C19.2/C24.1/C25.1 sat on a floating rail
    that was never tied to ground; a GND power symbol (#PWR054) now sits
    on the rail's right endpoint. The PWR_FLAG (#FLG08) that masked the
    floating net is removed - keeping it would put two power-output
    flags on GND (new ERC error); PWR_FLAGs have no netlist footprint.
    - Row 7: C9 part swap (dc-dc-conversion): 100uF 25V RVT1E101M0607 /
    C22383804 -> DMBJ RVT1H101M0810 100uF 50V / LCSC C970687 (bridges
    +15V to -13.5V =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
    [dc-dc-conversion.kicad_sch, linear-regulation.kicad_sch]
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2026-08-14 feat: Board A spec module + generated KiCad project (closes #124)
    scripts/schgen/board_a_spec.py locks the post-fix board-a topology: the
    netlist-derived baseline (D4 removed, R17/R18 + D6/D7 DNP, CC-debounce 0R
    links, D5 SMAJ20A, J4 A-B interface per the locked contract: 1-2=+15V from
    VBUS_OUT post-Q1, 3=ATT, 4=PDOK, 5-6=GND) plus dec-e's D8 gate-source zener
    (cathode D8.1 on VBUS_IN = Q1 source, anode D8.2 on Net-(Q1-G), fitted).
    J2/J3 pogo pads, TP1/TP2/TP6 included as bare-copper (blank-LCSC) entries.
    boards/board-a/ is the generated project: board-a.kicad_pro, generated
    board-a.kicad_sch (28 components, 17 nets, 94 pin specs, 6 no-connects),
    sym-lib-table/fp-lib-table with ${KIPRJMOD}/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
    [board-a.kicad_sch]
2026-08-14 fix: correct copied passive symbols' footprint nickname to house convention
    The five symbol blocks copied from the led-lamp library carried
    zudo-led-lamp:<fp> default footprint properties into the shared zudo-pd
    library and the generated board-a schematic's embedded lib_symbols. Every
    sibling symbol in this library uses the retained easyeda2kicad:<fp> import
    nickname; normalized the copies to match (instance-level footprints written
    by the generator were already zudo-pd:<fp> and are unchanged). Self-review
    finding.
    [board-a.kicad_sch]
2026-08-14 feat: Board B spec module + generated KiCad project (closes #125)
    board_b_spec.py implements the board-b baseline plus the locked wave-6
    decisions: (a) TVS2 = SMAJ6.5A/C87267, (c) C4/C22/C23 canonical LCSC
    C335982, (d) C5/C7 = 470uF/35V C22387780, (g) PTC1 = SMD1210P150TF/16
    C7529589, P1 PogoPad_1x04 ATT/PDOK provision, TVS3 cathode-to-GND lock.
    U4's inverting referencing is carried over exactly (GND/~ON-OFF/TAB on
    the -13.5V OUT net, L3.2 the only system-GND DC-DC pin).
    Eleven bare-MPN symbol clones are added (merge-only) so generator
    symbol names satisfy the audit contract's expected-MPN rule, and the
    TestPad_D1.5mm footprint is ported from zudo-led-lamp for TP3-TP5.
    Derived-not-baselined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
    [board-b.kicad_sch]
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2026-08-14 fix: schgen review fixes — board-a TP footprints, robust errors, geometry verifier
    - board_a_spec.py: TP1/TP2/TP6 now use zudo-pd:TestPad_D1.5mm (the committed
    house footprint board B already uses) instead of the undeclared stock
    TestPoint: nickname; adopt board B's shared-constant tuple style
    - schgen_core.py: SchgenError instead of bare asserts (works under -O, message
    not traceback), check_coverage collects every violation before failing,
    generate() split into _emit_* stages, UTF-8 + context managers on all file
    I/O, shared load_spec_module() for every CLI
    - sexp.py: module docstring, UTF-8 load, drop unused re import, one statement
    per line
    - gen_schematic.py / verify_netli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
    [board-a.kicad_sch]
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2026-08-15 fix(#150): C3/C11 are a Phi 8 can, not Phi 10 — correct the land and the evidence
    Issue #150 framed this as a layout-time decision: shrink the C3/C11 land to
    Phi 8, or keep the Phi 10 pad deliberately and record why. It is neither — it
    is a plain mistake. The HRK datasheet already cited by src-c2983319-datasheet
    (sha256 verified unchanged) states the case three ways on page 1: the header
    "GVT, 25v, 470uF, 8x10.5", the description "D8H10.5mm", and a Dimension &
    Marking table giving A 8.3 / B 8.3 / C 9.0 / D 8.0 / P 3.1 / L 10.5. Those map
    digit-for-digit onto CAP-SMD_BD8.0-L8.3-W8.3-LS9.0-FD, which already existed in
    the library and is already used by C9.
    The record carried no dimension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
    [board-b.kicad_sch]
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2026-08-15 fix(board-b): add C12 to -13.5V output-cap bank per locked spec (#162)
    Locks decision neg-rail-cap-bank: C12 (FOLLON C22387780, 470uF/35V) is
    added in parallel on the -13.5V output rail alongside C11/C24 so the
    three-can bank (C11 || C24 || C12) keeps every output electrolytic
    under 85% of its 150kHz-derated ripple rating at the 0.8A rated load.
    C11 stays on its Phi 8 land, unswapped.
    - board_b_spec.py: new C12 COMPONENTS entry + NETS pin additions
    - decisions.json: locked neg-rail-cap-bank decision entry
    - board-b-allow.json: C12 added_pins + _sources
    - component-project-passives: two new ripple-share facts, updated
    stale exceedance fact, manifest fact-ID parity, coverage.json reasons
    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
    [board-b.kicad_sch]
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
